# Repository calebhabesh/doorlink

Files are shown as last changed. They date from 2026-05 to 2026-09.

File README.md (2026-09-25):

# Doorlink

Doorlink is a self-hosted smart doorbell built around a custom ESP32-S3 board and a Raspberry Pi. A button press wakes the board, captures a still image, and sends the event to a local gateway. The gateway stores the media, updates the web dashboard, and sends a notification. The doorbell plays a local chime; when configured, the gateway also sends a Home Assistant webhook to play a chime on all configured smart speakers in the home. Visitor recordings and stored, turn-based voice replies are also supported.

<p align="center">
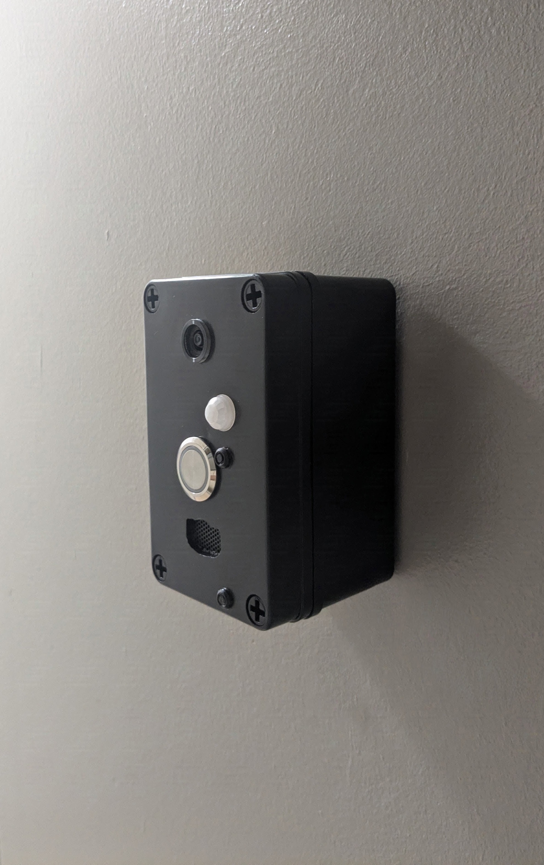
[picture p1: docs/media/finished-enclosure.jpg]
Assembled Doorlink Prototype Mounted on a Wall
  
</p>

## Prototype Status

The assembled Rev C board has completed battery-powered button wake, QXGA image capture, Wi-Fi upload, dashboard display, notification, and return to deep sleep. The microphone, speaker, and stored voice-reply path have been exercised on hardware. The latest session timing and hardened firmware still need a final flashed hardware retest; battery life and closed-enclosure current have not been measured. This is a working prototype, not a qualified outdoor product.

This is my first PCB layout and my first time hand-soldering surface-mount parts, including the ESP32-S3 module and ICS-43434 microphone. It took three revisions to get here: some scope creep, plus a few dumb mistakes that waited until after I ordered the boards to announce themselves.

## How It Fits Together

```mermaid
flowchart LR
    A[Doorbell PCB<br/>ESP32-S3 · camera · audio] -->|Wi-Fi| B[Raspberry Pi gateway<br/>Spring Boot]
    B --> C[(PostgreSQL<br/>events)]
    B --> D[(MinIO<br/>images and audio)]
    B --> E[Next.js dashboard]
    B --> F[ntfy notifications]
    A --> G[Local doorbell chime]
    B -->|Configured webhook| H[Home Assistant]
    H --> I[Smart speaker chimes]
    E -->|Stored voice replies| B
```

The firmware captures the image before joining Wi-Fi, then powers the camera down. Audio is turn-based: the visitor microphone and doorbell speaker do not run as a full-duplex call. The Raspberry Pi also runs Mosquitto for device commands.

## Hardware Gallery

| KiCad Rev C Board | Rev C Schematic |
| :---: | :---: |
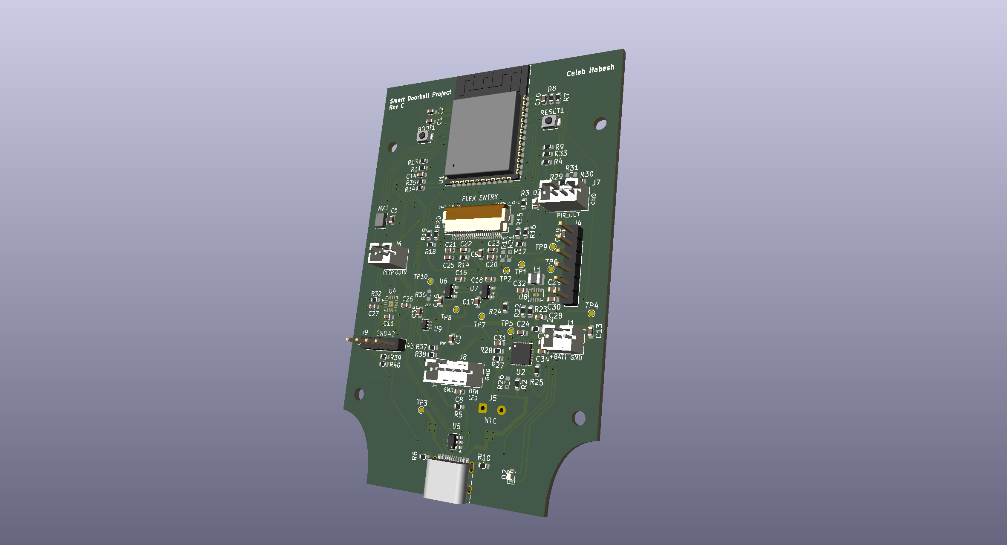
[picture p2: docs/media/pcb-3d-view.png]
KiCad Rev C Board
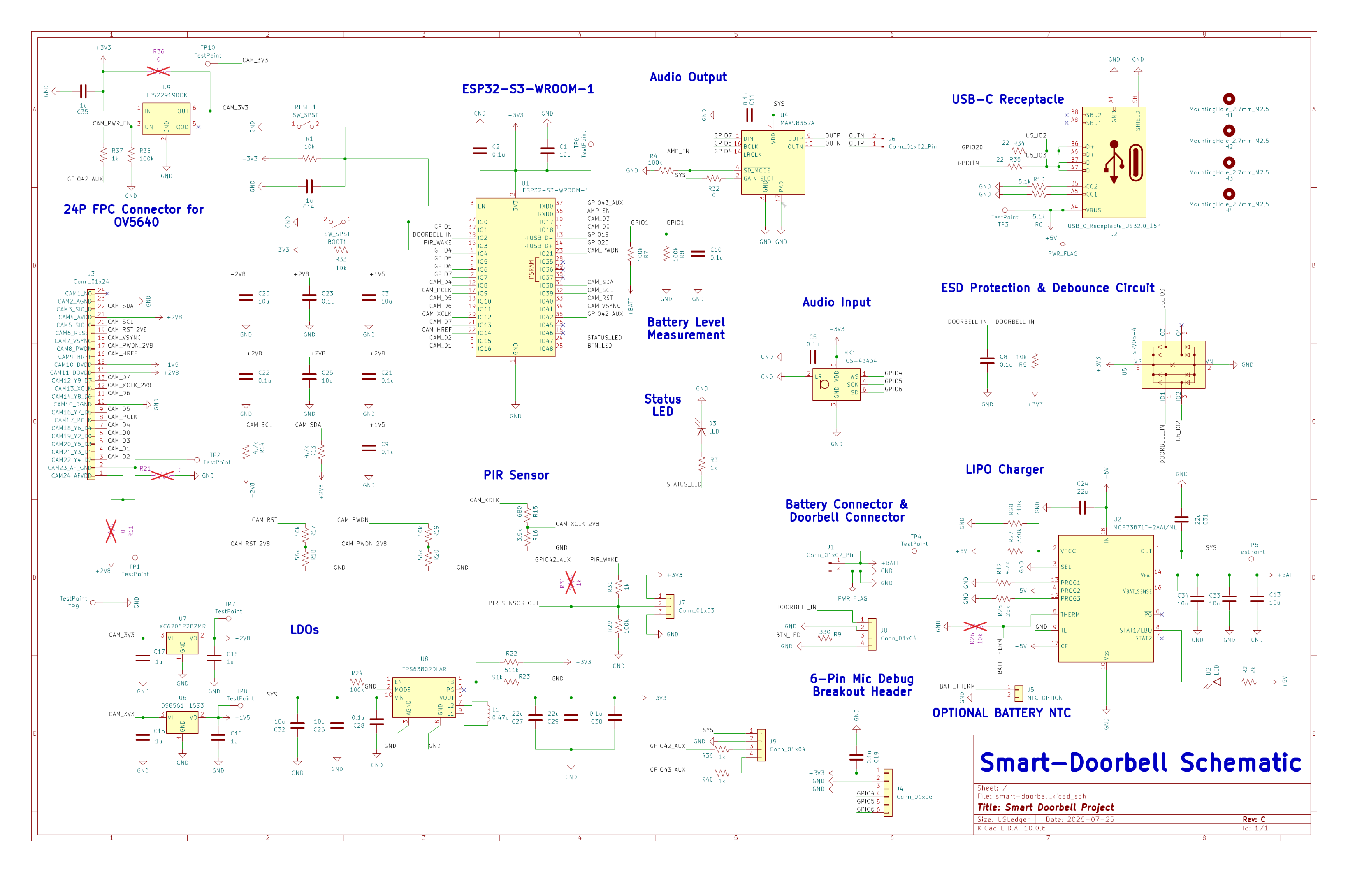
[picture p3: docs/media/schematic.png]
Rev C Schematic
|  |  |

| PCB Copper Layers (F.Cu and B.Cu) | Rev C Board Before ESP32 and Microphone Soldering |
| :---: | :---: |
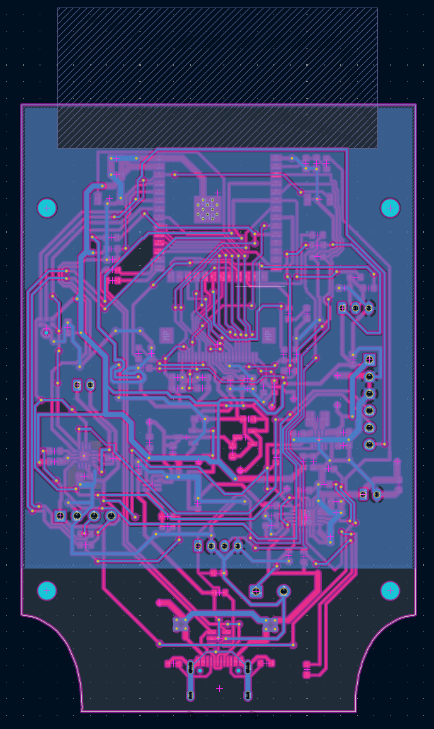
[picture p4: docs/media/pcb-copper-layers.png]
PCB Copper Layers (F.Cu and B.Cu)
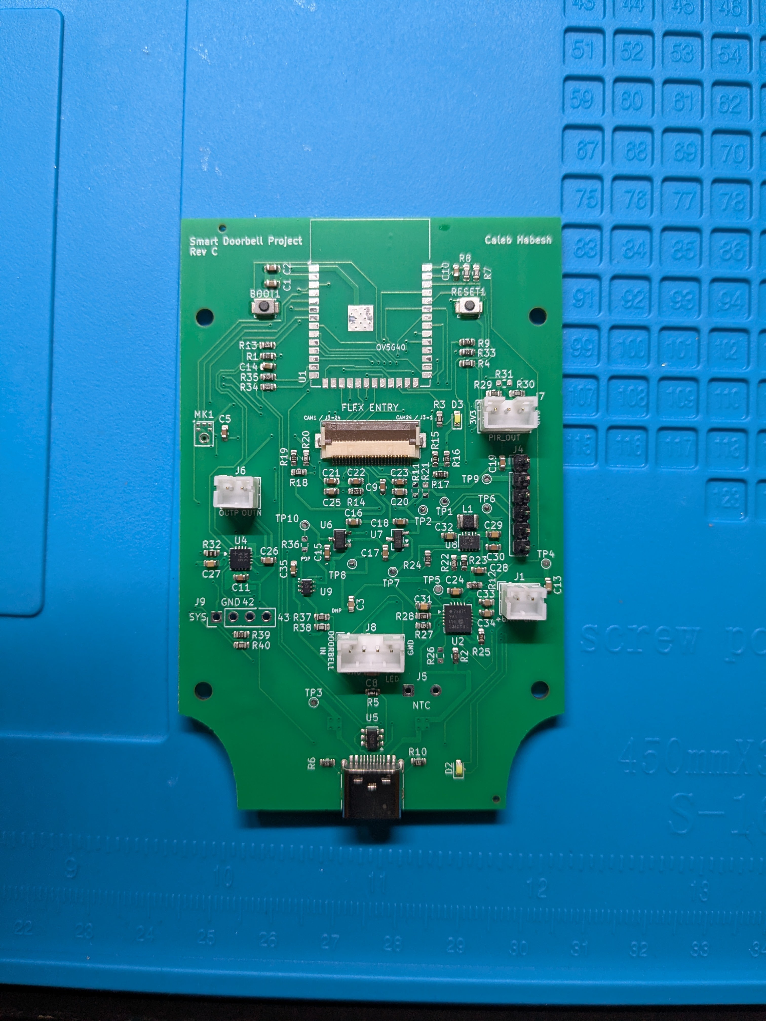
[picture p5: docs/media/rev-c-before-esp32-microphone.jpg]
Rev C Board Before ESP32 and Microphone Soldering
|  |  |

| Bench Bring-Up | Populated PCB | Enclosure Wiring |
| :---: | :---: | :---: |
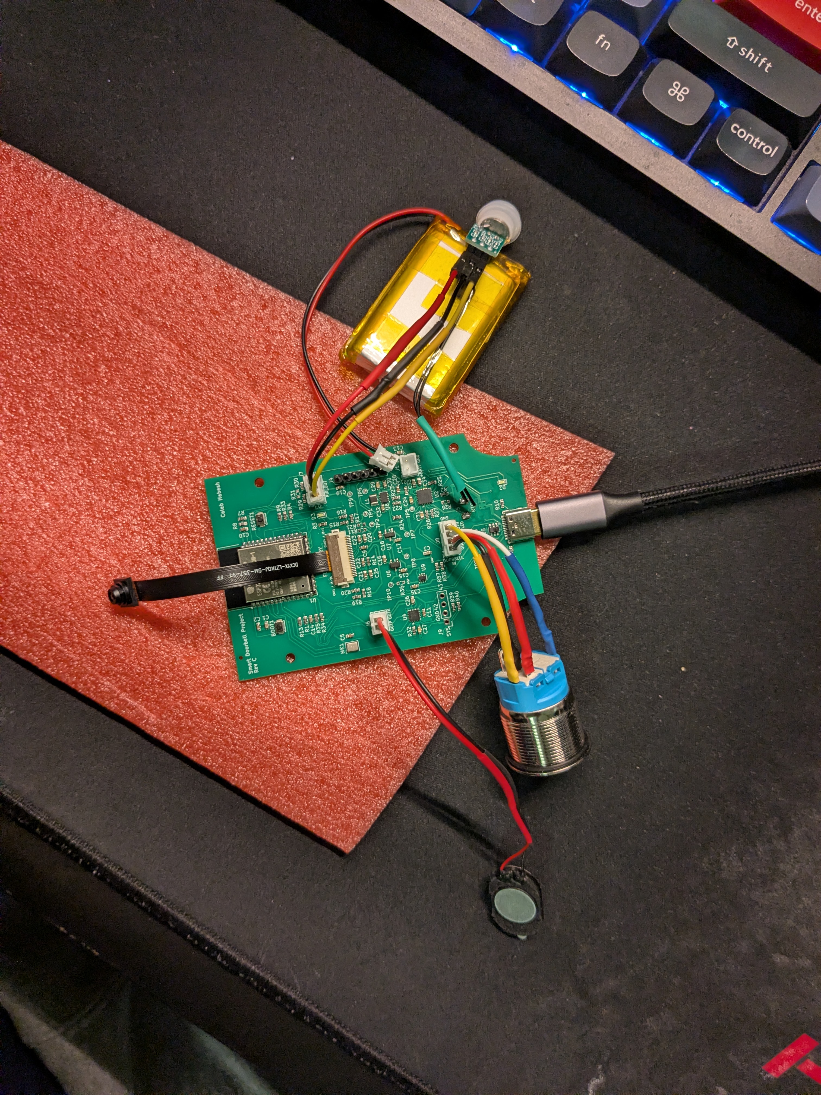
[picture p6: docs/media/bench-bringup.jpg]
Board and Peripherals During Bench Testing
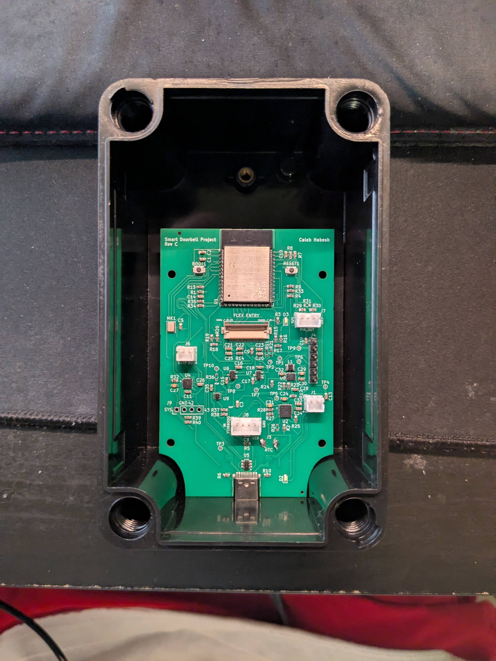
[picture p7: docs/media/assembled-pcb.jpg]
Rev C PCB Fitted in the Open Enclosure
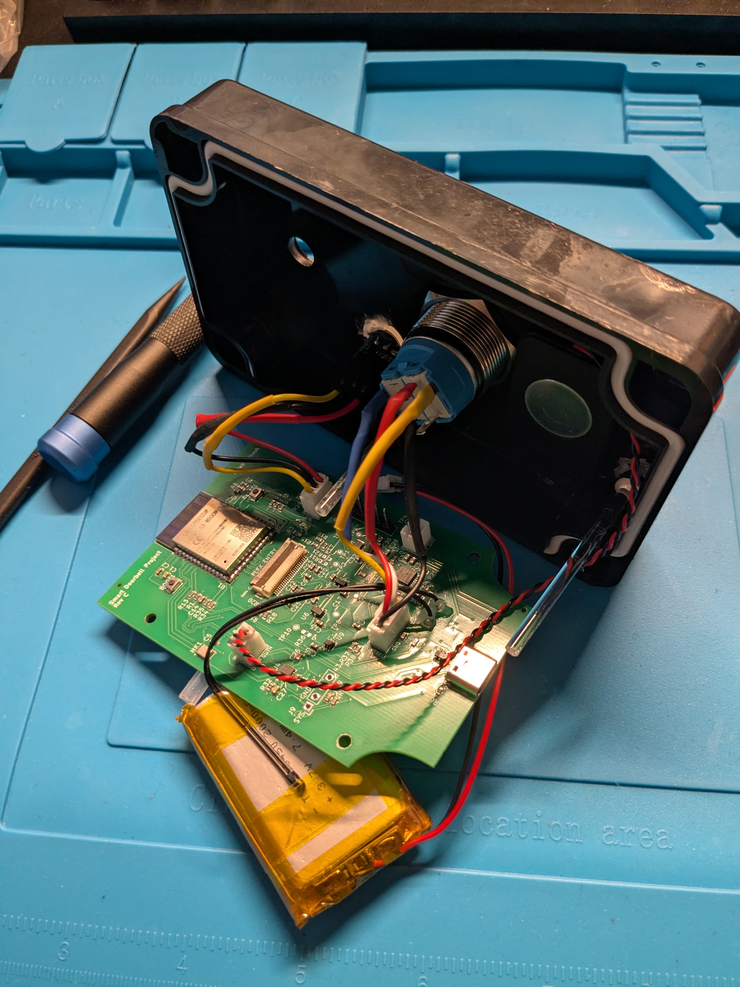
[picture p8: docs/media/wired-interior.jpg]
Board, Battery, Button, and Speaker During Enclosure Assembly
|  |  |  |

The board uses an ESP32-S3-WROOM-1-N16R8, OV5640 camera, ICS-43434 microphone, MAX98357A amplifier, MCP73871 charger, and TPS63802 3.3 V regulator. The [PCB overview](pcb/README.md) links the KiCad source and exact Rev C manufacturing files.

## Explore the Project

| Area | Contents |
| --- | --- |
| [`main/`](main/) | ESP-IDF firmware and routed board pin map |
| [`config/firmware/`](config/firmware/) | Firmware build presets and archived camera configurations |
| [`gateway/`](gateway/) | Spring Boot event API, persistence, media storage, and notifications |
| [`dashboard/`](dashboard/) | Next.js event and intercom interface |
| [`pcb/`](pcb/) | KiCad project and manufacturing records |
| [`docs/parts.md`](docs/parts.md) | Main unit parts and CAD cost |
| [`docs/firmware-architecture.md`](docs/firmware-architecture.md) | Firmware flow and validation status |
| [`docs/hardware-bringup.md`](docs/hardware-bringup.md) | Detailed Rev C hardware test record |

### Dashboard Preview

<p align="center">
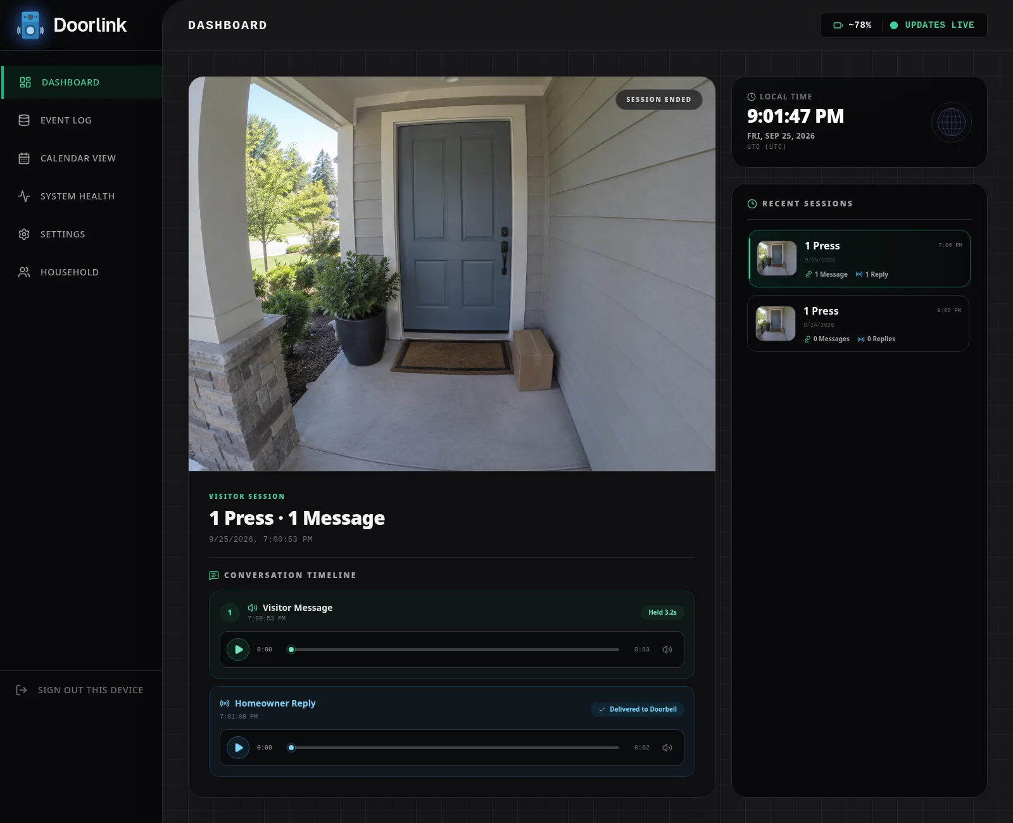
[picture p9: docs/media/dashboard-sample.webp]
Doorlink dashboard showing a sample visitor session, conversation timeline, and recent sessions
  
</p>

The dashboard is shown with synthetic sample sessions and a generated porch image. No visitor or household data is included.

## Run Locally

Install Docker Compose, Java 21, Node.js/npm, and the dashboard dependencies (`cd dashboard && npm ci`). From the repository root, run `./scripts/run-dev.sh` to start the isolated development stack. The gateway uses port 8081 and the dashboard uses [localhost:3001](http://localhost:3001). On first run, enter the setup token printed by the launcher. Ctrl+C stops the stack. The local credentials in `.env.dev` are for development only.

Firmware builds require ESP-IDF. Copy `main/config.example.h` to the ignored `main/config.h`, set your Wi-Fi and gateway values, then see [firmware architecture](docs/firmware-architecture.md) for the safe and production build commands. Raspberry Pi deployment is documented in [docs/pi-deployment.md](docs/pi-deployment.md).

## License

Software and written documentation: [MIT](LICENSE). KiCad hardware designs and manufacturing files under `pcb/`: [CERN-OHL-P-2.0](pcb/LICENSE). [Project photographs](docs/media/README.md): [CC0 1.0](https://creativecommons.org/publicdomain/zero/1.0/).

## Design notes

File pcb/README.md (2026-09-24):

# Doorlink PCB

The routed [KiCad schematic](smart-doorbell/smart-doorbell.kicad_sch) and [PCB](smart-doorbell/smart-doorbell.kicad_pcb) are the source for Rev C connections, footprints, and population intent. The Rev C design uses an ESP32-S3-WROOM-1-N16R8, an OV5640 24-pin camera connector, MCP73871 battery charging and power path, TPS63802 3.3 V regulation, and a GPIO-controlled camera power switch.

## Manufacturing files

The [Rev C ordered release](smart-doorbell/jlcpcb/rev-c/ORDERED_RELEASE.md) identifies the exact Gerber, JLCPCB BOM, and placement files submitted for the assembled prototype. Its BOM contains the 85 JLCPCB-populated references. U1 (ESP32-S3) and MK1 (microphone) were added after PCB assembly; several optional footprints remain unpopulated. The [protected assignment record](smart-doorbell/production/Smart_Doorbell_Project_B_bom-JLCPCB_FINAL.csv) retains per-reference LCSC assignments inherited from Rev B.

The [Rev B ordered release](smart-doorbell/jlcpcb/ORDERED_RELEASE.md) is historical. Its camera connector wiring differs from Rev C, so use the Rev C package for the photographed board. Do not regenerate or overwrite either ordered package.

The Rev C charger expects a suitable external 10 kΩ battery thermistor at J5; no thermistor is included in the PCB assembly BOM. See the [bring-up record](../docs/hardware-bringup.md) for the prototype checks and [board pin map](../main/board_pins.h) for firmware assignments.

Hardware design and manufacturing files in this directory: © 2026 Caleb Habesh, licensed under [CERN-OHL-P-2.0](LICENSE).

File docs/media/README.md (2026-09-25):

# Project Media

The schematic, PCB copper layer, and PCB 3D screenshots show the Rev C hardware design and follow the [hardware license](../../pcb/LICENSE).

`dashboard-sample.webp` shows the real dashboard interface with synthetic session data and a generated porch image. It follows the [software documentation license](../../LICENSE).

The project photographs in this folder are dedicated to the public domain under [CC0 1.0](https://creativecommons.org/publicdomain/zero/1.0/).

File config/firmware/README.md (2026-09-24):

# Firmware Build Configurations

Keep `sdkconfig.defaults` and `partitions.csv` at the project root for the normal ESP-IDF build. The small `sdkconfig.*.defaults` files here are optional overlays for production, microphone, wake, and camera experiments. Pass an overlay after the root defaults file with `SDKCONFIG_DEFAULTS`, as shown in [Firmware Architecture](../../docs/firmware-architecture.md).

The full `sdkconfig.revc-camera-*` files are archived configurations from Rev C camera bring-up. They are retained for reference and are not part of the default build.

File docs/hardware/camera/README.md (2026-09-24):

# OV5640 357-V1 seller documentation

The pinout below is transcribed from a mechanical drawing supplied by the
AliExpress seller for the fixed-focus `DCXYX-LZTKQJ-5M-357-V1` OV5640 camera
module. The seller's original image is not redistributed here.

The drawing identifies the 24 contacts as:

| Pin | Signal | Pin | Signal |
| --- | --- | --- | --- |
| 1 | NC | 13 | XCLK1 |
| 2 | AGND | 14 | Y8 |
| 3 | SIO_D | 15 | DGND |
| 4 | AVDD | 16 | Y7 |
| 5 | SIO_C | 17 | PCLK |
| 6 | RESET | 18 | Y6 |
| 7 | VSYNC | 19 | Y2 |
| 8 | PWDN | 20 | Y5 |
| 9 | HREF | 21 | Y3 |
| 10 | DVDD | 22 | Y4 |
| 11 | DOVDD | 23 | AF_GND |
| 12 | Y9 | 24 | AFVDD |

The seller drawing lists AVDD as 2.8 V, DOVDD as 1.8/2.8 V, and DVDD as
1.5 V. It also depicts a 24-contact, 0.5 mm-pitch FPC tail.

This is seller-provided evidence rather than a manufacturer-controlled
datasheet. The received module has now been compared with the drawing, but that
does not make the module a universal OV5640 mechanical standard. Every future
module must still be checked for physical pin 1, exposed-contact side, all
24 functions, and rail voltages. Pins 23 and 24 remain isolated by the board's
DNP contingency links for the fixed-focus module.

## Received first-article orientation

Front and rear photographs of the received camera were inspected on
2026-07-25. The flex marking reads `DCXYX-LZTKQJ-5M-357-V1 FF`, and the
24 exposed contacts are on the rear/shield side, opposite the lens. This
matches the seller drawing.

Both PCB revisions use J3 `FH12-24S-0.5SH(55)`, a horizontal bottom-contact
connector. With the PCB component side facing up, its antenna at the top, and
USB-C at the bottom:

- approach J3 from the antenna/U1 side;
- keep the camera lens facing up, away from the PCB;
- keep the exposed flex contacts facing down, toward the PCB;
- J3 pin 1 is the right-hand end near J7, and J3 pin 24 is the left-hand end
  near MK1.

This orientation mates the contact surfaces, but it does **not** preserve pin
order. The seller drawing's bottom/contact-side view has the camera body above
the tail, pin 1 at the right, and pin 24 at the left. Viewed from the
lens/printed side, that order is mirrored: pin 1 is at the left. Therefore the
photographed lens-up/contact-down insertion maps camera pin `n` to J3 pin
`25 - n`: camera pin 1 reaches J3 pin 24, and camera pin 24 reaches J3 pin 1.
The camera advertisement's enlarged tail drawing also visibly labels pin 24 at
the left and pin 1 at the right in the depicted contact-side view; it is
additional evidence of the same orientation, not evidence that the lens-side
orders match.

## Rev C physical mapping

Rev C keeps J3 in the mechanically correct Rev B orientation and corrects the
electrical nets on its physical pads. The footprint pad numbers remain honest:
camera pin `n` mates with physical J3 pad `25 - n`.

| Camera pin | Function | Physical J3 pad | Rev C board net |
| ---: | --- | ---: | --- |
| 1 | NC | 24 | NC |
| 2 | AGND | 23 | `GND` |
| 3 | SIO_D | 22 | `CAM_SDA` |
| 4 | AVDD | 21 | `+2V8` |
| 5 | SIO_C | 20 | `CAM_SCL` |
| 6 | RESET | 19 | `CAM_RST_2V8` |
| 7 | VSYNC | 18 | `CAM_VSYNC` |
| 8 | PWDN | 17 | `CAM_PWDN_2V8` |
| 9 | HREF | 16 | `CAM_HREF` |
| 10 | DVDD | 15 | `+1V5` |
| 11 | DOVDD | 14 | `+2V8` |
| 12 | Y9 / D7 | 13 | `CAM_D7` |
| 13 | XCLK1 | 12 | `CAM_XCLK_2V8` |
| 14 | Y8 / D6 | 11 | `CAM_D6` |
| 15 | DGND | 10 | `GND` |
| 16 | Y7 / D5 | 9 | `CAM_D5` |
| 17 | PCLK | 8 | `CAM_PCLK` |
| 18 | Y6 / D4 | 7 | `CAM_D4` |
| 19 | Y2 / D0 | 6 | `CAM_D0` |
| 20 | Y5 / D3 | 5 | `CAM_D3` |
| 21 | Y3 / D1 | 4 | `CAM_D1` |
| 22 | Y4 / D2 | 3 | `CAM_D2` |
| 23 | AF_GND | 2 | Isolated contingency net through DNP R21 |
| 24 | AFVDD | 1 | Isolated contingency net through DNP R11 |

The top silkscreen labels the ends `CAM1 / J3-24` and `CAM24 / J3-1`. The
project-local `ov5640_pinout.kicad_sym` library gives every J3 symbol pin both
the camera-pin identity and physical pad number. Run
`python3 scripts/verify-camera-interface.py` from the repository root to export
a fresh schematic netlist and enforce the complete mirrored map, contingency
links, level networks, and Rev C camera load switch.

Do not insert or power this camera directly in Rev B J3 again. A simple
lens-side flip is not a correction because J3 is bottom-contact and requires
the exposed flex contacts on the bottom. Recovering Rev B requires a verified
24-way crossover/interposer. Rev C needs no J3 rotation or flex twist, but its
first powered camera test still requires a known-good camera and the staged,
current-limited plan in `docs/hardware-bringup.md`.

The Rev C KiCad correction was submitted as the minimum five-board prototype
order on 2026-07-26 after its actual JLCPCB BOM match and top-side assembly
preview passed. Its exact upload files, hashes, and preview evidence are
recorded in `pcb/smart-doorbell/jlcpcb/rev-c/ORDERED_RELEASE.md`. Preserve both
immutable ordered releases: Rev B as fault history and Rev C as the corrected
first-article package. Insert or remove any flex only with every power source
disconnected, and keep R11 and R21 DNP for this fixed-focus module.

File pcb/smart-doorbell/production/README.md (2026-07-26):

# PCB release artifacts

The routed KiCad project is the electrical and population source of truth.
`Smart_Doorbell_Project_B_bom-JLCPCB_FINAL.csv` remains the protected,
authoritative per-reference LCSC assignment record for all references inherited
by Rev C.

The external `bom-JLCPCB Assembly Order.xls` describes the obsolete
MCP73831/AP2112 topology. It is not an upload BOM and may only be consulted for
substitution candidates after every current requirement has been reverified.

## Ordered Rev B release

The exact PCB/PCBA package submitted on 2026-07-15 remains at:

- `../jlcpcb/production_files/GERBER-smart-doorbell.zip`
- `../jlcpcb/production_files/BOM-smart-doorbell.csv`
- `../jlcpcb/production_files/CPL-smart-doorbell.csv`

Its immutable hashes, order identifiers, and provenance are recorded in
`../jlcpcb/ORDERED_RELEASE.md`. Run `sha256sum -c ORDERED_RELEASE.sha256` from
`../jlcpcb/` before using Rev B as comparison evidence.

Rev B contains the known physical J3 camera-pin reversal. Never reorder it and
do not insert the selected lens-up/contact-down camera directly into a Rev B
board. Rev B populated R36, left U9/R37 DNP, and used populated fixed R26 in
place of real cell-temperature sensing; these facts describe only the ordered
historical batch.

## Ordered Rev C release

Rev C has a separate ordered-release directory:

- `../jlcpcb/rev-c/production_files/GERBER-smart-doorbell.zip`
- `../jlcpcb/rev-c/production_files/BOM-smart-doorbell.csv`
- `../jlcpcb/rev-c/production_files/CPL-smart-doorbell.csv`

Exact hashes, generation provenance, local verification results, and the
signed-off JLCPCB BOM/preview evidence are recorded in
`../jlcpcb/rev-c/ORDERED_RELEASE.md`. Run
`sha256sum -c ORDERED_RELEASE.sha256` from that directory whenever verifying
the submitted bytes.

Rev C contains 85 populated references in both BOM and CPL. Existing protected
Rev B references retain their exact value/LCSC assignment. The intentional
population delta is:

- add/populate C35 (`1u`, C15849);
- add/populate R37 (`1k`, C21190);
- add/populate U9 (`TPS22919DCKR`, C2149796);
- remove/DNP R26 and R36.

U9 is the only populated path from `+3V3` to `CAM_3V3`. R38 and the TPS22919
internal pulldown keep it default-off; GPIO42 reaches `CAM_PWR_EN` through
populated R37. R31 must remain DNP so GPIO42 is not also connected to the PIR
fallback. QOD is intentionally open.

Rev C intentionally excludes these references from both BOM and CPL:

- U1 (`ESP32-S3-WROOM-1-N16R8`) and MK1 (`ICS-43434`), hand solder;
- R11 and R21, DNP camera contingency links;
- R26, DNP fixed THERM resistor;
- R31, DNP GPIO42 PIR fallback;
- R36, DNP camera-power bypass;
- J5 and J9, unpopulated hand-solder/expansion connections;
- TP1 through TP10, bare test points;
- H1 through H4, mechanical mounting holes.

J5 is only a connection for an external thermistor. No NTC is present in the
Rev C JLCPCB BOM. Do not charge a battery until a suitable
10 kOhm-at-25-degrees-C NTC is wired to J5 and thermally attached to the cell.

The BOM explicitly targets timer-disabled `MCP73871T-2AAI/ML`; do not substitute
the six-hour-timer `MCP73871T-2CCI/ML` at the present approximately 213 mA
charge current.

## Legacy comparison evidence

`Smart_Doorbell_Project_B.zip` and its adjacent Fabrication Toolkit exports are
retained only as previously reviewed comparison evidence. They were not the
files submitted for the 2026-07-15 order.

Neither a local CPL inspection nor this manifest replaces JLCPCB's rendered
assembly preview. The Rev C order passed that external gate before submission:
all 85 top-side placements, every DNP, package, side, and rotation were checked,
with special attention to U9 pin 1 at the corrected 180-degree CPL rotation.
The retained evidence and sign-off are part of the ordered Rev C release.

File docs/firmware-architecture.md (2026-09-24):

# Firmware architecture

The firmware uses controlled C++ for event orchestration while retaining C for
the proven hardware and ESP-IDF-facing layers. Exceptions and RTTI are disabled.
The default build remains the core-only safe image; production mode is an
explicit, isolated configuration.

## Runtime path

`app_main.cpp` selects either a diagnostic image or `DoorbellController`.
Production mode follows this bounded session sequence:

1. `BOOTING`: reapply the retained camera/audio-safe GPIO state, release the
   sleep holds without a pad glitch, and classify the wake.
2. `LOCAL_CHIME`: start the bounded low-power camera-overlap chime profile. One
   playback claim, including rapid repress retriggers, has a 15-second wall
   limit and a 1.5-second zero-progress I2S limit.
3. `CAPTURING`: with RF off, enable GPIO42/U9, initialize the OV5640, capture QXGA, copy the
   JPEG to owned PSRAM, return the frame, deinitialize the driver, and disable
   U9.
4. `CONNECTING` / `TRIGGERING`: connect Wi-Fi after shutter close and post the
   authenticated session/press trigger.
5. `UPLOADING`: independently POST available JPEG and visitor WAV media under
   stable per-press identifiers. All retries share one stage wall deadline.
6. `VISITOR_RECORDING`: if GPIO2 remains held after the first chime, or on any
   later press, retain 1-15 seconds of release-driven microphone audio.
7. `PTT_SESSION`: accept only HMAC-authenticated MQTT commands for the active
   random session, reject replay IDs, and queue homeowner playback behind any
   active visitor capture. Media and acknowledgement URLs must match the exact
   configured gateway origin and route; redirects are disabled.
8. `SHUTTING_DOWN`: explicitly close the gateway session, release media, stop
   Wi-Fi, drive the load gates and I2S pads safe, latch those states, configure
   wake sources, and enter deep sleep.

Camera and Wi-Fi are deliberately non-overlapping high-load phases. The camera
frame never survives camera-driver shutdown; only the owned PSRAM copy does.
The event ID also makes a retry after a lost HTTP response idempotent at the
gateway and gives media a stable object key.

## Ownership and boundaries

| Layer | Language | Responsibility |
| --- | --- | --- |
| `DoorbellController` | C++ | State machine, retry policy, event type, shutdown orchestration |
| `CameraService` / `CapturedImage` | C++ | RAII ownership of the PSRAM JPEG |
| `ConnectivityManager` | C++ | Bounded Wi-Fi/upload lifecycle and shutdown guard |
| `IntercomService` / `intercom_protocol` | C++ | Signed command validation, fragment assembly, URL policy, and bounded playback |
| `AudioService` / `chime_player` | C++ / C | Deadline-bound I2S ownership, capture, playback, and fail-safe teardown |
| `PowerManager` | C++ | Wake classification, stuck-input handling, and deep-sleep entry |
| `camera_capture` | C | OV5640 configuration and guaranteed frame/driver/power cleanup |
| `camera_power`, `ov5640_mode_fix`, bring-up modules | C | Auditable hardware sequencing and diagnostics |

There is no inheritance hierarchy, exception path, or RTTI dependency.
Follow-up turn metadata is bounded heap state and visitor WAV/JPEG payloads use
PSRAM where available. ESP-IDF errors remain `esp_err_t`.

## Wake behavior

- GPIO2 `DOORBELL_IN`: EXT0, active low, routed 10 kOhm pull-up and debounce
  capacitor.
- GPIO3 `PIR_WAKE`: EXT1, active high, routed 100 kOhm pulldown through the
  populated Rev C R30 path.
- A held button or still-high PIR is excluded from that sleep cycle to prevent
  a rapid wake loop. A 30-second timer is enabled so the input can be checked
  again.
- Cold boot, timer-recovery wake, and unknown wake causes enter sleep without
  taking a picture.
- GPIO48 uses a non-blocking LEDC fade on timer/channel 1. Camera XCLK remains
  on timer/channel 0.
- Before deep sleep, GPIO42, GPIO44, and GPIO4-7 are individually held in their
  safe state. ESP32-S3's global digital deep-sleep hold is enabled for the two
  non-RTC load gates. Wake code programs the same safe state before releasing
  the latches.

## Builds

Safe core-only build:

```bash
idf.py build
```

Production-controller build, isolated from the safe `sdkconfig`:

```bash
idf.py -B build-production -D SDKCONFIG=sdkconfig.production \
  -D 'SDKCONFIG_DEFAULTS=sdkconfig.defaults;config/firmware/sdkconfig.production.defaults' build
```

Both configurations build with ESP-IDF 6.0.1. The hardened production image is
approximately 1.56 MiB and leaves about 48% of the 3 MiB application partition
free.

## Validation status

Implemented and independently proven hardware operations include QXGA capture,
camera shutdown, battery-only Wi-Fi upload, gateway persistence, dashboard
display, notifications, and isolated GPIO2 button and GPIO3 PIR wakes followed
by return to deep sleep. An RTC-fast wake stub gives immediate visual acknowledgement on D3
before the bootloader; GPIO48 begins its nonblocking ring animation as soon as
the application starts. Cold boots still validate the
application image. The pre-fast-trigger production controller has completed QXGA capture, HTTP
upload, cleanup, and return to deep sleep from both button and PIR triggers on
hardware; notification delivery and Doorlink display were observed for both
event types. The fast-trigger/idempotent-upload flow was USB-validated on Rev C
on 2026-08-05. Corrected PIR and button events received HTTP `200` for the early
trigger in approximately 1.2-1.6 seconds, fully stopped Wi-Fi before camera
startup, completed isolated QXGA capture, uploaded under the same event ID, and
returned to deep sleep. The gateway stored one event per ID and did not invoke
the chime again during upload. Production now leaves PIR event wake disabled
unless `CONFIG_SMART_DOORBELL_ENABLE_PIR_EVENTS` is explicitly selected. The
isolated GPIO48 diagnostic and production path both validated an off-to-full
1.8-second fade, 2.5-second hold, and 1.8-second fade-out without delaying Wi-Fi
or camera work. Camera
convergence remains the dominant image-delivery delay.
Deep-sleep current remains unmeasured. The earlier fixed-duration visitor audio
and stored PTT playback path passed hardware tests; release-driven capture and
multi-press arbitration are implemented and build-tested but still require an
instrumented board validation pass.

The 2026-08-23 pre-enclosure hardening pass added strict fragmented-MQTT
assembly, HMAC-SHA256 command authentication and replay rejection, gateway-only
URL policy, redirect suppression, shared wall deadlines for retries, bounded
I2S stall handling, a bounded greeting-task join with fail-safe sleep, and
deep-sleep GPIO retention. The host guard tests, all 42 gateway tests, and a
clean ESP-IDF 6.0.1 production build pass. This revision has not yet been
flashed or battery-cycle tested; see `firmware-release-checklist.md`.

The production controller also takes a calibrated 16-sample +BATT reading from
GPIO1 before starting the speaker, camera, or radio. The gateway retains the
millivolt value and sample time; System Health exposes those authoritative
fields plus a coarse, explicitly estimated one-cell Li-ion percentage. It does
not infer charger state, thermistor temperature, remaining runtime, or a
low-battery cutoff.

The current production flow supersedes the USB-validated trigger-first order:
the first QXGA frame is captured before Wi-Fi starts, then its owned JPEG is
uploaded before the controller waits for a held-button recording. Repress
lifecycle work may remain ordered for persistence, but only the press reserved
for immediate controller handling can dispatch remote alerts; all others are
registered with alerts permanently suppressed. Repress local acknowledgements
remain opportunistic and are never queued behind microphone or homeowner audio.
This revision is compiler- and gateway-test-verified and still needs
flashed-board timing validation. EXT0 is re-armed only after session close,
cleanup, and the existing button-release guard.

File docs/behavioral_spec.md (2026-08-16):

# Smart Doorbell Production Interaction Contract

This is the locked production behavior for the Rev C door-mounted device. It
defines product behavior; hardware-dependent timing and audio quality still
require validation on the assembled board after firmware changes.

## Non-negotiable hardware rules

- `PWR-01`: Wi-Fi RF and `CAM_PWR_EN`/GPIO42 are never active together.
- `PWR-02`: Camera rails and `AMP_EN`/GPIO44 are disabled immediately after use.
- `MEM-01`: the camera frame is copied to owned PSRAM before its driver buffer is
  returned and U9 is disabled.
- `AUDIO-01`: local chime, visitor microphone, and homeowner reply are
  half-duplex users of the shared I2S bus.
- `SLEEP-01`: a button still held at shutdown is handled by the GPIO2
  wake-on-release guard; it must not cause a wake loop or another visitor event.

## Visitor session

The first debounced button press creates a random 32-character `sessionId` and
press ID `<sessionId>-1`. More button-down edges before session expiry create
ordered press IDs `<sessionId>-2`, `<sessionId>-3`, and so on.

The session ends at the earlier of:

- 60 seconds since the last visitor/PTT activity; or
- 90 seconds since the first press.

Firmware explicitly closes the session before sleep when the gateway is
reachable. The gateway and dashboard infer closure from the same 60/90-second
limits if that close request is lost.

Every press is persisted with its own idempotency key. The first press dispatches
the indoor/Home Assistant chime immediately after the initial shutter closes.
Each fresh repress independently requests the whole-home chime; the gateway
drops requests during its playback cooldown instead of retaining a trailing
request. Represses that cannot be handled promptly remain persisted but are
ineligible for a delayed chime.

## First press

1. GPIO2 must remain stable for 20 ms.
2. Start the ring LED and the complete local chime on the camera-safe 12 dB
   profile.
3. Keep RF quiesced and start the initial QXGA snapshot without waiting for the
   camera-safe chime to finish. Capture the first complete frame; do not spend
   several QXGA frame periods on unrequested convergence discards.
4. Return the camera frame, disable U9, connect Wi-Fi, and send the authenticated
   gateway trigger.
5. Upload the owned JPEG immediately, without waiting for button release or a
   visitor recording to finish.
6. If the visitor is still holding when the complete chime releases I2S, start
   the microphone immediately and record until release or the 15-second cap.
   Attach any retained WAV to the existing press in a separate upload.
7. Open the bounded homeowner reply window after the visitor turn finishes.

A visitor recording is retained only when it contains at least 1.0 second of
microphone audio. Releasing during the first chime, or before one second of
post-chime microphone audio, is a normal short press and creates no empty WAV.

## Later presses

- Restart LED acknowledgement on every valid down-edge.
- Start an onboard acknowledgement chime when I2S is idle. Never queue a
  delayed chime behind visitor microphone or homeowner playback. If a local
  chime is already audible, rewind its live stream at the next PCM chunk
  boundary so every valid physical down-edge gets prompt audible feedback.
- Treat repress chimes as interruptible: a visitor still holding after 1,200 ms
  stops the repress chime cleanly and receives the microphone. A tap may let
  its acknowledgement chime finish.
- Until that same down-edge has remained continuously held for 1,200 ms, it
  cannot reserve the microphone or stop a local chime. A newer down-edge
  invalidates every older pending hold classification, so an old tap cannot
  mistake the new press for its own continued hold.
- Retain visitor microphone audio only after the one-second recording threshold
  is crossed. Release creates one logical recording.
- A release followed by another hold creates another ordered press/recording.
- Keep the initial snapshot for the active session. Do not repower the camera
  for a repress: its RF-off capture boundary would make the global chime and
  intercom unavailable during the refresh. The next session takes a new image.
- Each repress launches a separate immediate gateway request from its physical
  edge while RF is available, independently of camera/media lifecycle work.
  A request already in flight causes the new edge to be dropped rather than
  queued. Later lifecycle or media work persists the press with
  `dispatchAlerts=false` and cannot manufacture a delayed whole-home chime.
- There is no three-press product limit. The 60/90-second session bounds and
  memory/queue limits are the safety boundary.

Recordings stay in bounded RAM through their upload attempt; firmware does not
write visitor audio to flash.

## Half-duplex arbitration

The first press starts a complete chime. A later deliberate 1,200 ms hold may
reclassify the active local stream as interruptible so the visitor can claim
the microphone. Established visitor/homeowner turns remain protected except at
the 90-second hard deadline:

1. The first local chime completes unless a subsequent held repress explicitly
   yields it to the microphone.
2. A repress acknowledgement may play only while I2S is otherwise idle; a
   sustained visitor hold or arriving homeowner WAV interrupts it cleanly.
   The repress does not claim the microphone window until its own continuous
   1,200 ms hold qualification completes.
3. An active visitor recording completes on release or at 15 seconds.
4. A homeowner reply received during visitor capture is queued.
5. The microphone is off while the queued homeowner WAV plays through the
   speaker.
6. An already-playing homeowner reply completes; a new visitor hold waits for
   I2S and records afterward if the visitor is still holding.
7. Session cleanup overrides queued work at the hard deadline.

Dashboard PTT records a stored 16 kHz mono PCM WAV; it is not a live phone call.
The gateway reports `ARMING` when it publishes the device command and reports
reply delivery only after the ESP32 playback acknowledgement.

## Speaker and camera power arbitration

The production speaker paths apply 6 dB of digital attenuation by default to
support the 4-ohm enclosure speaker without demanding the full-scale current
used during the failed integrated test. Local chimes and homeowner replies both
use the same setting and a 25 ms linear fade-in/fade-out envelope. These values
are build-time configurable through
`CONFIG_SMART_DOORBELL_SPEAKER_ATTENUATION_DB` and
`CONFIG_SMART_DOORBELL_SPEAKER_RAMP_MS`.

The initial camera capture runs before Wi-Fi startup so network latency cannot
move the shutter toward button release. Its owned JPEG is also uploaded before
joining a held-button recording. Gateway triggers remain idempotent per physical
`pressId`, and the gateway acknowledges and persists each press without waiting
for Home Assistant. Whole-home webhook delivery uses a 1.5-second leading-edge
cooldown: the first request
dispatches immediately, requests during the cooldown are dropped, and the first
request after expiry dispatches immediately. No trailing webhook is retained,
so rapid presses cannot become a delayed playback burst. Repress uploads never
act as fallback chime requests.

The first press claims the bounded 12 dB camera-overlap profile before playback
starts, so RF shutdown and camera startup no longer wait for the complete
waveform. Represses during the boundary restart the same complete quiet
waveform. If that low-power chime already owns AMP_EN, camera rail enable waits
for its 25 ms ramp plus a 5 ms guard before adding the camera load. Camera
startup still refuses overlap with any unverified speaker owner. Visitor
microphone and homeowner playback retain I2S priority. Transient I2S DMA
backpressure during QXGA work is retried in place and is not treated as the end
of the chime.

Normal session expiry stops button monitoring first, then allows an already
audible local chime to drain before entering sleep. Firmware force-stops that
playback only when it remains active past the bounded four-second shutdown
deadline, which indicates a wedged audio path rather than an ordinary session
transition.

## Persisted and UI model

```text
Visitor session
├── Press 1
│   ├── optional snapshot
│   └── zero or more visitor recordings
├── Press 2
│   └── zero or more visitor recordings
└── homeowner reply turns
```

`sessionId`, `pressId`, `recordingId`, and reply `messageId` are stable retry
keys. The gateway emits lifecycle SSE updates (`session-started`,
`press-started`, `press-ended`, `session-updated`, and `session-closed`). Active
Event, Event Log, and Calendar render one grouped session, with an ordered
conversation timeline instead of one card per upload.

Legacy event rows remain readable during rollout; rows with the historical
`<sessionId>-<pressNumber>` pattern are grouped into closed sessions.

## Production constants

| Constant | Value |
| --- | ---: |
| GPIO2 stable debounce | 20 ms |
| Minimum retained visitor audio | 1,000 ms |
| Maximum visitor recording | 15,000 ms |
| Repress chime-to-microphone handoff | 1,200 ms |
| Production speaker attenuation | 6 dB |
| Speaker fade-in/fade-out | 25 ms |
| Camera-overlap chime | Full waveform at 12 dB attenuation |
| Discarded first-snapshot convergence frames | 0 |
| Repress edge-request timeout | 750 ms, no waiting queue |
| Whole-home chime cooldown | 1,500 ms, leading edge, no queue |
| Session idle limit | 60,000 ms |
| Session absolute limit | 90,000 ms |
| Browser homeowner reply limit | 20,000 ms |

## Failure behavior

- Wi-Fi failure never prevents the complete first local chime or LED
  acknowledgement.
- The first chime is not stopped merely because time elapsed. A physical
  repress may restart its live stream from sample zero; a deliberate held
  repress may yield it to the microphone after 1,200 ms.
- After the final quick press, the restarted chime is allowed to complete.
  Repress chimes may also yield to homeowner WAV or safe shutdown.
- Camera failure leaves the early session/press alert intact and cuts camera
  power; the dashboard may show snapshot pending.
- A lost trigger or media response is retried with stable identifiers, so it
  does not create another notification or recording.
- Quiet speech is retained; firmware does not use voice-activity detection to
  discard it.
- The 15-second recording cap does not bypass stuck-button wake-on-release
  protection.

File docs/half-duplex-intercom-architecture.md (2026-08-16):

# Doorlink Half-Duplex Intercom Architecture

The fixed-duration visitor WAV and stored dashboard-to-speaker reply path have
passed on assembled Rev C hardware. The release-driven multi-press policy below
is implemented and build-tested; its thresholds and latency still require a
flashed-board validation pass.

Doorlink is a turn-based voicemail relay, not a full-duplex call. The local
chime, ICS-43434 microphone, and MAX98357A speaker share a half-duplex I2S path,
so only one owns it at a time. MQTT transports small control commands and HTTP
transports stored WAV media.

## Visitor flow

```mermaid
sequenceDiagram
    actor Visitor
    participant ESP as ESP32-S3
    participant GW as Spring Gateway
    participant UI as Dashboard
    actor Homeowner

    Visitor->>ESP: First press / hold
    par Local acknowledgement
        ESP->>ESP: Play one complete local chime
    and Early alert
        ESP->>GW: POST session + press trigger
        GW-->>UI: session-started SSE
    end
    ESP->>ESP: If still held, record until release (1-15 s retained)
    ESP->>ESP: RF off, capture snapshot, camera power off
    ESP->>GW: Upload available JPEG/WAV with stable IDs
    GW-->>UI: session-updated SSE

    Visitor->>ESP: Later press / hold
    ESP->>ESP: LED + interruptible local chime if I2S idle
    ESP->>ESP: If held 1,200 ms, stop repress chime and record
    ESP->>GW: Register press and upload WAV

    Homeowner->>UI: Hold PTT, then release
    UI->>GW: Store canonical 16 kHz mono PCM WAV
    GW->>ESP: MQTT PLAY_AUDIO with HTTP URL
    Note over ESP: Queue behind active visitor recording
    ESP->>ESP: Microphone off; enable amp and play complete reply
    ESP->>GW: Playback acknowledgement
    GW-->>UI: session-updated SSE
```

The initial microphone can start only after the complete local chime. A visitor
who releases during that chime leaves no recording. Later presses request an
immediate local acknowledgement only when I2S is idle. A tap may let that chime
finish; a new valid down-edge while a local chime is audible rewinds the live
stream at its next PCM chunk boundary. A hold continuing for 1,200 ms interrupts
interruptible repress audio and hands I2S to the microphone. Repress chimes are
skipped, not delayed, while visitor or homeowner audio owns the bus. A release
followed by another hold is another ordered press and recording in the same
60/90-second session.

## Arbitration

Priority is:

1. Finish the first local chime.
2. Yield an interruptible repress chime to a sustained visitor hold or an
   arriving homeowner WAV.
3. Finish an active visitor turn on release or at 15 seconds.
4. Play a queued homeowner reply completely.
5. If a visitor presses during that playback, finish the active reply and give
   the microphone to a visitor who is still holding.
6. Enforce the 90-second hard session deadline and safe shutdown.

No voice-activity detector discards quiet speech. Recordings shorter than one
second are discarded solely to avoid empty tap/accidental-hold files.

## Control and data planes

Homeowner replies are stored in MinIO before this command is published on
`doorbell/commands/audio`:

```json
{
  "type": "PLAY_AUDIO",
  "eventId": "0123456789abcdef0123456789abcdef",
  "messageId": "6db2995e-4c0e-4717-9b95-8c0330031eb2",
  "audioUrl": "http://gateway:8080/api/events/media/reply.wav",
  "ackUrl": "http://gateway:8080/api/system/ptt/messages/6db2995e-4c0e-4717-9b95-8c0330031eb2/delivered",
  "durationMs": 3200
}
```

`eventId` is the session target. The ESP32 fetches and streams the canonical WAV
over HTTP, disables the amplifier after its final sample, and POSTs `ackUrl`.
The dashboard distinguishes `Playback queued` from `Played at door` using that
acknowledgement. A successful MQTT publish alone is reported as `ARMING`, not as
confirmed device playback.

## Persistence model

- `visitor_sessions`: session bounds, activity, and explicit close state.
- `events`: ordered physical presses and their snapshot/lifecycle state (kept as
  the table name for compatibility).
- `visitor_recordings`: stable recording ID, press relationship, media key, and
  measured WAV duration.
- `intercom_messages`: homeowner WAV, creation time, and playback delivery time.

Active Event, Event Log, and Calendar consume grouped session DTOs. Legacy rows
using numbered press IDs are grouped into closed sessions during migration.

## Why stored half-duplex turns

- It avoids acoustic echo cancellation and intentional chime contamination.
- It keeps radio activity bounded for a battery-powered device.
- Stable files and identifiers can be retried after intermittent Wi-Fi.
- The UI can present a truthful, durable conversation timeline rather than
  claiming unsupported live audio streaming.

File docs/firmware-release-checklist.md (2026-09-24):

# Firmware release checklist

This is the final pre-enclosure acceptance gate for the Rev C production
firmware. Passing the software checks makes the image a release candidate; it
does not replace current, temperature, supply-droop, or battery-life
measurements on the assembled device.

## Verified in the development checkout

- Fragmented MQTT messages are accepted only when every offset and total is
  contiguous, consistent, and leaves room for the terminator.
- Gateway commands use protocol `v1`, a unique UUID, and HMAC-SHA256 over every
  field consumed by firmware. Altered, unsigned, and recently replayed commands
  are rejected.
- Reply media and acknowledgement URLs must use the exact scheme, host, and
  port from `GATEWAY_API_URL`, plus the expected API path shape. Query strings,
  fragments, escapes, traversal, user-info, and redirects are rejected.
- One chime claim has a 15-second wall limit and a 1.5-second no-progress limit.
  Microphone capture, HTTP playback, stage retries, and the greeting task join
  use finite deadlines. A missed task join proceeds to safe sleep rather than
  returning with a live stack reference.
- `CAM_PWR_EN`, `AMP_EN`, I2S WS/SCK, speaker data, and microphone data are
  latched in their safe states through deep sleep and released glitch-free on
  wake.
- Production samples the populated GPIO1 battery divider before high-current
  peripherals start and reports calibrated millivolts on both the early event
  trigger and media upload. Dashboard percentage is an estimate; it is not a
  measured state of charge or a low-battery cutoff.

Run the reproducible software gates:

```bash
./scripts/test-firmware-guards.sh

cd gateway
./mvnw test

cd ..
source /home/ethioking/.espressif/v6.0.1/esp-idf/export.sh
idf.py -B build-production -D SDKCONFIG=sdkconfig.production \
  -D 'SDKCONFIG_DEFAULTS=sdkconfig.defaults;config/firmware/sdkconfig.production.defaults' build
```

## Rollout order

The hardened firmware deliberately rejects commands from an older gateway.

1. Confirm the Pi and `main/config.h` use the same high-entropy
   `GATEWAY_API_KEY`.
2. Deploy and restart the gateway first:
   `./scripts/build-pi-production.sh --gateway-only --restart`.
3. Flash the production firmware and retain USB access for the first smoke run.
4. Confirm a dashboard PTT start/cancel/reply round trip. The device log must
   show the MQTT subscription and normal playback, with no
   `unauthenticated intercom command` message for gateway-generated commands.

## Required physical acceptance before sealing

1. On USB power, run one complete press, QXGA capture, image upload, optional
   held-button recording, reply playback, session expiry, and return to sleep.
2. Repeat a complete cycle on battery only with the final camera, 4-ohm
   speaker, button, PIR harness state, and enclosure cable routing fitted.
3. During the battery cycle, check 3.3 V droop/reset behavior, image integrity,
   amplifier and regulator temperature, and camera shutdown. Exercise at least
   one repress during the bounded camera-overlap chime.
4. Confirm System Health shows a plausible battery voltage from that event and
   compare it with TP4 using a multimeter. Record the pair; the earlier 4.028 V
   firmware / 4.05 V meter result is only one calibration point.
5. Measure awake and deep-sleep current. Battery life remains unqualified until
   those values are recorded; do not infer it from the earlier one-cycle test.
6. Verify `CAM_PWR_EN` and `AMP_EN` remain low in deep sleep. If practical,
   confirm I2S WS/SCK are also low rather than floating.
7. Power-cycle twice from battery and confirm GPIO2 wakes once per press, the
   held-input guard does not create a wake loop, and every cycle returns to
   deep sleep.

Record the measurements in `docs/hardware-bringup.md`. Only then treat this
firmware and the assembled battery unit as production-signed-off.

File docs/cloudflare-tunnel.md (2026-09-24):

# Cloudflare Tunnel and household device access

Doorlink uses Cloudflare Tunnel for private origin connectivity and its own
revocable household-device sessions for browser authentication. Cloudflare
Access email OTP must not sit in front of the hostname: its one-month maximum
session would reintroduce the login prompt before Doorlink can see the device
cookie.

## Traffic path

`doorbell.example.com` → Cloudflare Tunnel → Next.js on `localhost:3000` →
Spring gateway on `127.0.0.1:8080`

No router port is opened. Cloudflare still provides DNS proxying, TLS, Tunnel,
and normal edge/WAF protections. Doorlink authenticates every dashboard page,
API read/write, event stream, and media response.

## 1. Keep or create the tunnel

In **Cloudflare Zero Trust → Networks → Tunnels**, keep the `doorbell-pi`
connector and its public hostname (replace these examples with yours):

- Hostname: `doorbell.example.com`
- Service: `HTTP`
- URL: `localhost:3000`

If the connector is not installed yet, use the Cloudflare-provided ARM64
installation command on the Raspberry Pi. Never commit its tunnel token.

## 2. Remove the interactive Access challenge

In **Zero Trust → Access → Applications**, remove the existing Smart Doorbell
self-hosted application, or add a highest-priority **Bypass** policy for this
exact hostname. Confirm in a private browser that Cloudflare no longer displays
an email/OTP page and Doorlink displays its own “device needs an invitation”
screen instead.

Do not point the tunnel directly at port 8080. Only the Next.js service on port
3000 should be public through the tunnel.

## 3. Configure the one-time owner bootstrap secret

On a trusted machine, generate a secret:

```bash
openssl rand -base64 32
```

Set it as `HOUSEHOLD_BOOTSTRAP_TOKEN` in the Pi checkout's ignored `.env` file,
then deploy/restart both gateway and dashboard. Visit:

```text
https://doorbell.example.com/setup
```

Enter the secret, owner details, and a recognizable device name. After setup,
remove `HOUSEHOLD_BOOTSTRAP_TOKEN` from `.env`; the bootstrap endpoint is also
permanently disabled by the stored owner record.

For isolated local development, provide the same variable when starting the
stack, for example `HOUSEHOLD_BOOTSTRAP_TOKEN=... ./scripts/run-dev.sh`.

The gateway stores only SHA-256 hashes of session and enrollment tokens.
Browser cookies are Secure, HttpOnly, SameSite=Lax, and renewed while a device
is used. The browser's practical 400-day cookie cap is handled by renewal, so an
active device remains signed in without a monthly prompt.

## 4. Add household devices

Open **Household** in Doorlink:

1. Add a person's name and email.
2. Copy the generated single-use enrollment link and send it privately.
3. They open the link on the exact phone/browser they want to enroll and give
   that device a name.
4. Repeat **New device link** for another browser or phone.

Enrollment links expire after 72 hours by default. They contain a short-lived
secret, so do not post them publicly. ntfy action links contain no bearer token;
they open the ordinary dashboard URL, where the device cookie authenticates the
browser.

The owner can revoke one device or remove a member (which revokes every device).
Revoked devices immediately lose new API and media access, any open event stream
is closed by the next 20-second heartbeat, and the browser is redirected to the
enrollment screen on its next page request.

## ntfy membership

Doorlink's current `ntfy.sh` topic is still a shared, hard-to-guess topic. Device
revocation in Doorlink does not remotely unsubscribe the ntfy mobile app. If
notification subscription must be revoked per person too, use authenticated
ntfy users/topic ACLs (hosted or self-hosted) and manage those subscriptions
separately. Never put a permanent Doorlink session token in an ntfy URL.

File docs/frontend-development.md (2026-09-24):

# Frontend development with live Raspberry Pi data

Use the dashboard-only development mode for rapid UI work. It runs Next.js on
the Arch development server with hot reloading while reading current sessions,
media, health, settings, and server-sent events from the Raspberry Pi gateway.

```bash
SMART_DOORBELL_DEV_GATEWAY_URL=http://192.168.1.10:8080 ./scripts/run-dashboard-dev.sh
```

Replace the example address with your Raspberry Pi gateway's LAN address.

The launcher starts scanning at port 3001 and prints the URL using the first
available port. For example, when another service already owns port 3001, the
dashboard normally starts at `http://localhost:3002`. Changes under
`dashboard/src/` should appear without rebuilding or deploying the production
dashboard.

From another computer, keep the service loopback-only and create an SSH tunnel
using the selected port. For port 3002:

```bash
ssh -L 3002:127.0.0.1:3002 user@dev-machine.local
```

You can then use `http://localhost:3002` in that computer's browser. For direct
access on a trusted LAN, set `SMART_DOORBELL_DEV_HOST=0.0.0.0`. Do not expose
the raw development port to the internet; place a development hostname behind
an authenticated tunnel such as Cloudflare Access.

The browser only talks to the local Next.js server. Next.js proxies reads to the
Pi gateway set in `SMART_DOORBELL_DEV_GATEWAY_URL`, so the browser does not need direct
database, MinIO, API-key, or CORS access. The development proxy blocks writes
to event, device, and settings data. Its one exception is the token-backed
device enrollment request, which creates a revocable browser session. Controls
such as push-to-talk and settings can still be styled in the UI, but cannot
change the Pi system while this launcher is in use.

## Enroll the local development browser

The local URL is a different browser origin from the deployed dashboard. Its
browser profile needs its own household device session to read private gateway
data.

1. Start `./scripts/run-dashboard-dev.sh` and note the URL it prints, including
   its selected port.
2. In an already-enrolled **owner** browser, open the deployed Doorlink
   **Household** page. Click **New device link** beside the owner account and
   copy the resulting single-use URL. Keep the token private.
3. Open the local URL from step 1 in the browser profile used for UI
   development. On the Access page, paste the entire link and click
   **Open enrollment here**. The app opens the enrollment path on `localhost`.
4. Name the browser, such as `Arch frontend dev`, and submit the enrollment
   form. The local origin now has its own revocable household session. Return
   to the printed local URL to view live data with hot reload.

The owner can later revoke this development browser from **Household**. If the
browser still returns to the access page after enrollment, check that the URL
uses the same hostname and browser profile as the enrollment page; cookies are
scoped to a hostname. Browsers that reject `Secure` cookies on a loopback HTTP
origin need an HTTPS local origin for this workflow.

To use a different gateway, host binding, or starting port:

```bash
SMART_DOORBELL_DEV_GATEWAY_URL=https://doorbell.example.com \
SMART_DOORBELL_DEV_HOST=127.0.0.1 \
SMART_DOORBELL_DEV_PORT=3002 \
./scripts/run-dashboard-dev.sh
```

If the requested starting port is occupied, the launcher continues scanning
upward until it finds a free TCP port.

Keep `GATEWAY_READ_ONLY=true` when the target is the production Pi. The existing
`./scripts/run-dev.sh` remains the mode for frontend/backend integration work
that needs writable, isolated Postgres, Mosquitto, and MinIO containers.

## Why the Pi gateway is the data boundary

Do not expose PostgreSQL or MinIO from the Pi to the development machine and do
not run the local Spring gateway against the Pi database. Reusing the gateway's
read APIs keeps schema handling, media access, and session serialization in one
place and makes the read-only boundary enforceable at the frontend proxy.

If stable or destructive test scenarios are needed later, take a one-way,
sanitized snapshot of Pi Postgres and MinIO into the isolated local stack rather
than writing tests against production data.

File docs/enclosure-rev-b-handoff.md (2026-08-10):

# Smart Doorbell Rev B Enclosure Handoff

This document condenses the enclosure/mechanical decisions for the wireless
battery-powered doorbell build. Use it as the starting context before changing
the KiCad Rev B PCB outline, mounting holes, or component placement.

## Target Product Shape

- Apartment-door-mounted, Ring-style doorbell.
- Mounted outside an apartment door using renter-friendly Command strips.
- Corridor is well lit and has decent ventilation.
- Interface is vertical along the longest enclosure dimension.
- Front interface layout:
  - Camera in the upper half, centered.
  - Status LED/light pipe near the camera.
  - Optional PIR below/near the status LED.
  - Main illuminated button near the bottom, centered.
  - Charging LED near the bottom.
  - Speaker, mic, and USB-C cutouts around sides and bottom.

## Enclosure Decision

Use a black, solid-cover `DS-AG-0813`-style ABS enclosure:

- Selected outside size: `80 x 130 x 70 mm` (`W x H x D`), with no external
  mounting ears.
- The catalogued enclosure uses a `50 mm` deep base and `20 mm` lid. Mount the
  PCB to the deep base/back side; use the lid as the hallway-facing front panel
  for the button, camera, PIR, and light-pipe openings.
- This is a compact, vertical doorbell form factor. It is a better visual fit
  than the previously considered `158 x 90 x 60 mm` and `115 x 90 x 55 mm`
  project boxes while retaining useful depth for the button and battery.
- Do not design the PCB around the enclosure's lid-screw pattern or molded
  bosses. Use custom standoffs fixed to the deep base instead.

Why this enclosure:

- The old `100 x 68 x 50 mm` box was too tight.
- The 22 mm button plus battery plus PCB stack caused the lid not to close.
- User dry-fit showed that even with the PCB basically sitting on the 10 mm
  battery, the `100 x 68 x 50 mm` enclosure could not fully close.
- The `80 x 130 x 70 mm` enclosure keeps a much more doorbell-like front
  profile and has more total depth than the old box.
- The present PCB outline is shaped for rounded corners: it is wide through
  its middle and narrow at its USB-C end. Preserve that advantage for the
  first fit instead of converting it to a plain rectangle.

Depth math:

- Old `100 x 68 x 50 mm` box measured roughly:
  - deep base internal depth: `33 mm`
  - lid internal depth: `12 mm`
  - total usable internal depth: about `45 mm`
- The selected enclosure has a catalogued `50 mm` base plus a `20 mm` lid.
- Button internal protrusion when mounted correctly through the front lid is
  about `31 mm`.
- PCB stack on the selected standoffs:
  - `10 mm` standoff + `1.6 mm` PCB + `5 mm` tallest JST = `16.6 mm`
- The available depth works only when the battery uses the side-wall/depth
  volume described below rather than stacking behind the button or PCB.

Catalog fit evidence for the standard `DS-AG-0813`:

- Reference: [Switch Box mechanical document](https://images.100y.com.tw/pdf_file/DMCA.pdf),
  pages 5-6. Treat this as the geometry reference for the standard mould; the
  exact marketplace enclosure may be a compatible clone and still needs
  measurement.
- Published outside dimensions: `130 x 80 x 70 mm` (`H x W x D`).
- Published dimension table: `H1/H2/H3/H4 = 130/124/112/100 mm`,
  `W1/W2/W3 = 80/74/62 mm`, and `D1/D2 = 50/20 mm`; stated tolerance is
  `+/-1 mm`.
- The matching internal mounting plate is `116 x 68 x 1.6 mm`.
- The current roughly `59 x 91 mm` board fits within that mounting-plane
  envelope with about `9 mm` total width margin and `25 mm` total height
  margin. This supports the current outline, but the actual purchased case
  still requires a physical fit check for ribs, bosses, and molding variation.

## Current PCB Context

Current KiCad source of truth:

- PCB file: `pcb/smart-doorbell/smart-doorbell.kicad_pcb`
- Current outline bounding box is roughly `59 x 91 mm`:
  - x range: `107.25..166.25`
  - y range: `55.95..146.95`
- Current mounting holes are M2.5:
  - footprint: `MountingHole_2.7mm_M2.5`
  - positions: `(111.05, 71.425)`, `(162.45, 71.425)`,
    `(111.05, 122.825)`, `(162.45, 122.825)`
  - current pattern: `51.4 x 51.4 mm`
- Current mechanically relevant footprints:
  - `MK1` ICS-43434 mic at `(110.95, 89.442)`
  - `J6` speaker JST-PH 2-pin at `(115.55, 98)`
  - `J7` PIR JST-PH 3-pin at `(155.25, 86.45)`
  - `J8` button/LED JST-PH 4-pin at `(133.65, 122.1)`
  - `J1` battery JST-PH 2-pin at `(158.442, 114.371)`
  - `J2` USB-C receptacle at `(136.85, 143.45)`

Do not stretch or scale the PCB to the enclosure. The existing outline is
already within the documented mounting-plane envelope. The USB-C end tapers to
about `41 mm`, which is useful around the enclosure's rounded end corners.

## Camera Module Target and FPC Contingency

The selected camera is the `DCXYX-LZTKQJ-5M-357-V1 FF`: the 120-degree
distortion-free, fixed-focus OV5640 24-pin DVP module. Fixed focus is the
intended production choice; autofocus is not a requirement for this doorbell.

The first 22 connector positions use the eight-bit DVP/SCCB/power arrangement
documented in the KiCad source. The seller drawing now recorded in
`docs/hardware/camera/README.md` identifies position 23 as `AF_GND` and position
24 as `AFVDD`. Rev B keeps both contacts isolated by default, with test pads and
normally-unpopulated configurable links:

- `J3.23` -> test pad -> `0R`, DNP -> GND (`AF_GND` contingency).
- `J3.24` -> test pad -> `0R`, DNP -> `+2V8` (`AFVDD` contingency).

For the selected fixed-focus camera, both `0R` resistors remain unpopulated and
neither pin connects to power, ground, GPIO, or pull resistors. Populate them
only after a specific autofocus module's pinout confirms pin 23 is `AF_GND`
and pin 24 is `AFVDD`. This is a future AF contingency, not a requirement for
the fixed-focus build.

Before powering the camera, inspect the received module and verify its pin-1
and exposed-contact orientation against the seller drawing. R11 and R21 remain
DNP for the selected fixed-focus camera.

## Recommended PCB Mechanical Direction

Keep the PCB at its current envelope for the first enclosure fit:

- Width target: current `58-59 mm` maximum; do not grow it.
- Height target: current `91 mm`; do not grow it.
- Preserve the tapered/scalloped edge treatment, especially around the USB-C
  end. Do not replace it with a full rectangle before the physical fit test.
- Do not chase the enclosure boss pattern.
- Use custom internal standoffs attached to the enclosure floor.
- Prefer the current M2.5 mounting direction:
  - PCB holes: `2.7-2.8 mm` NPTH.
  - Hardware: M2.5 machine screws, washers, and short threaded standoffs.

Mounting concept:

- Attach custom standoffs to the ABS floor using epoxy/plastic bonder.
- Do not epoxy the PCB itself.
- Do not use RTV silicone as the primary structural mount; it is too flexible.
- Neutral-cure silicone/E6000 is fine for strain relief and non-structural
  retention.
- Avoid acetic/vinegar-cure silicone near electronics.

Standoff process:

1. Screw standoffs loosely to the PCB.
2. Put a small amount of plastic-compatible epoxy on the bottom of each
   standoff.
3. Place the PCB into the enclosure at the exact final position.
4. Let cure with the PCB acting as the alignment jig.
5. Remove the screws and lift the PCB out.
6. Add a small epoxy fillet around each standoff base if needed.
7. Reinstall the PCB with nylon washers.

Standoff height:

- Use `10 mm` M2.5 female-to-female standoffs, OD ideally `<=5 mm`.
- Physical comparison with the received enclosure found that the existing
  `6 mm` standoffs are about `1 mm` shorter than the unused molded bosses.
  The `10 mm` selection provides useful tolerance above those bosses and more
  comfortable clearance for the silicone mic tube.
- The resulting PCB stack is about `16.6 mm` deep. The selected `70 mm`
  enclosure has adequate depth when the battery uses the right-side L-shaped
  placement and the button's rear keepout does not overlap the PCB laterally.
- Confirm actual boss clearance, screw engagement, wiring bends, and lid
  closure with a dry fit before bonding the standoffs.

Consider adding an extra support near the upper-left/mic area if the tube
preload causes board flex.

## Volume Allocation Inside Box

Do not stack everything in one depth column. Separate the mechanical volumes:

- Button barrel: front/lid area, lower center, must have a clear rear keepout.
- PCB: mounted flat to the back floor of the deep base on short standoffs.
- Battery: mounted to the right interior side wall in the forward portion of
  the deep base, not under the PCB and not behind the button.
- Speaker: wired/movable, mounted to bottom or side grille.
- Mic tube: short duct near the left side and `MK1`.
- Wiring gutters: use side/corner space.

The battery and PCB form an L-shaped volume: the PCB occupies the back plane;
the LiPo lies vertically on the right wall, with its `34 mm` dimension running
front-to-back. Keep the battery entirely on the deep-base side of the
lid/base seam. Never bond it to the lid or bridge the seam, because opening the
lid would flex the pouch and its leads.

## Battery

Existing battery:

- Type: `103450` LiPo.
- Dimensions: `50 x 34 x 10 mm`.
- Connector: JST-PH 2.0.
- Nominal voltage: `3.7 V`.
- Advertised capacity: `2000 mAh`.

Nothing is wrong with this battery. `103450` means approximately:

- `10 mm` thick
- `34 mm` wide
- `50 mm` long

Use it as the baseline/prototype battery. Capacity may be optimistic; treat it
as roughly `1500-2000 mAh` until measured.

Recommended placement:

- Mount battery to the right interior wall of the `80 x 130 x 70 mm` deep
  base. The right side keeps the left side free for the short `MK1` mic duct
  and is close to battery connector `J1`.
- Orientation:
  - `50 mm` dimension vertical.
  - `34 mm` dimension front-to-back.
  - `10 mm` thickness protruding inward from the side wall.
- Place it in the forward part of the deep base, away from the lower-centre
  button rear keepout and clear of the PCB's tallest components.

"Battery bay" means a reserved internal keepout/placement zone, not a separate
plastic part. The battery can sit against the ABS side wall, retained by
foam tape, adhesive Velcro, or a light strap.

Battery safety/mechanical notes:

- Do not clamp or compress the pouch.
- Use fishpaper/Kapton/plastic insulation between the LiPo and any PCB
  solder joints or hard edges.
- Do not rely on loose tape permanently.
- Bigger battery is okay only if thickness stays near `10 mm`; larger
  footprint is less risky than greater thickness.

## Button

Current button:

- 22 mm illuminated metal momentary button.
- White LED.
- LED voltage listing: `3-6 V` / `5 V`.
- Rear depth from listing: about `33 mm`.
- When mounted correctly through the front lid with face/gasket outside the
  enclosure, internal protrusion is about `31 mm`.
- Blue rear harness/socket makes total depth too long and should be removed.

Keep the current 22 mm button. The button is not the main problem if the
battery is side-mounted and the PCB does not stack behind it.

Button wiring:

- Use JST-PH 2.0 4-pin 26 AWG pigtail if it matches PCB connector `J8`.
- Solder pigtail wires directly to the button tabs.
- Use heat shrink over each soldered terminal.
- Do not friction-fit bare wires.
- Do not use the original 18 AWG harness wires unless necessary; they are
  mechanically bulky.

Button pinout:

- Red: NC, leave unused and insulated.
- Blue: NO, connect to doorbell signal.
- Black: C/common, connect to button common/GND side.
- Yellow: LED positive.
- Green: LED negative.

PCB `J8` pin mapping:

- `J8 pin 1`: `/DOORBELL_IN` -> button NO/blue.
- `J8 pin 2`: `GND` -> button C/black.
- `J8 pin 3`: button LED positive path via `R9=330` to `/BTN_LED` -> yellow.
- `J8 pin 4`: `GND` -> LED negative/green.

Verify JST pigtail wire order by continuity. Do not assume AliExpress color
order matches the PCB pin order.

## Microphone

Current mic:

- `MK1`: ICS-43434 I2S MEMS microphone.
- It is a bottom-port mic.
- The KiCad footprint includes a small non-plated acoustic hole through the
  PCB under the mic.
- Sound enters from the underside of the PCB, not from the top of the mic
  package.

Existing material:

- Silicone tubing: `2 mm ID x 4 mm OD`, 1 meter.

Accepted mechanical concept:

- Use the silicone tube as a side-tapped acoustic duct/manifold under the PCB.
- The tube should be mic-only. Do not share the speaker grille.
- Because `MK1` is already near the upper-left side of the PCB, the duct can be
  short.

Recommended mic duct:

```text
left side wall mic hole
-> open tube end against side-wall mic hole
-> short tube run under PCB near MK1
-> small upward-facing window/slit in tube wall aligned to PCB mic acoustic hole
-> tube continues 5-10 mm past MK1
-> far end sealed
```

Details:

- Exterior mic hole: about `1.0-1.5 mm`.
- Tube window under mic: start about `1 mm`, enlarge only if needed.
- Align the tube window to the PCB acoustic hole, not just the `MK1` package
  outline.
- Use tape only for dry fit.
- Final sealing/retention: neutral-cure silicone, E6000, or similar flexible
  adhesive.
- Do not let adhesive block the PCB acoustic hole or tube bore.
- Add PCB keepout around the under-board tube path.
- The selected `10 mm` standoffs provide comfortable tube clearance. Retain
  the tube without enough preload to bow the PCB.

Avoid:

- Long curved mic tube paths.
- Routing mic to the speaker grille.
- Leaving the mic to listen only to the sealed enclosure interior.
- Moving the mic off-board unless the PCB-mounted solution fails.

## Speaker

Previously tested speaker:

- 8 ohm, 1 W, small oval speaker.
- Size: `24 x 15 mm`.
- This unit passed the original conservative J6 electrical bring-up but was
  judged too small, quiet, and tinny for the enclosure target.

Current construction target, recorded 2026-08-10:

- One speaker from a five-piece pack described by the seller as `4 ohm`,
  `3 W`, with a `2.0` terminal.
- Outdoor metal speaker cover mounted inside the enclosure between the speaker
  and the cutout in the ABS panel.
- Verify the received speaker dimensions, terminal housing/latch, pin order,
  polarity, and cover geometry before machining. The seller photo is not a
  dimensional drawing, and `2.0` does not by itself prove JST-PH compatibility.
- The 3 W marking is speaker power handling, not guaranteed board output. U4
  is powered from `/SYS`; the MAX98357A's advertised 3.2 W into 4 ohms is a
  5 V condition, while this design does not provide U4 a dedicated fixed 5 V
  speaker rail.

Recommended placement:

- Prefer a bottom- or side-facing grille for water shedding. A forward-facing
  installation is acceptable only with full cover overlap, a perimeter gasket,
  and suitable water protection.
- Keep away from mic grille/tube.
- Use a foam/EVA perimeter gasket to couple the speaker to the metal cover and
  prevent front-to-rear acoustic leakage.
- Cut one controlled opening behind the metal cover rather than improvising a
  visible hole pattern. Size it from the measured diaphragm, cover open area,
  and bonding flange.
- A metal cover is not a water barrier. Add a hydrophobic acoustic membrane if
  outdoor exposure requires one.

Electrical caution:

- Speaker connector `J6` is driven by the MAX98357A bridged output.
- Do not connect either speaker lead to ground.
- Do not connect multiple speakers to J6.
- Retain the populated R32 6 dB gain strap and determine maximum usable output
  through digital level, clipping, current, and temperature testing.

See the [enclosure construction guide](enclosure-construction-guide.md) for
the speaker stack, tools, cutout method, assembly order, and acceptance tests.

## Light Pipe And LEDs

Existing light-pipe parts:

- LPA3.5 light guide column.
- Purchased size: `LPA3.5-21.1 mm`.
- Ten clear acrylic rods, `3 mm x 100 mm`.
- Ten black `3 mm` panel-mount clip LED bezels.

Likely issue:

- `21.1 mm` is a test/spare part, not a presumed final fit. With the PCB
  mounted to the rear/deep base on 10 mm standoffs, the likely LED-to-inner-lid
  distance is roughly `51-56 mm`; confirm this only with the actual enclosure
  and installed PCB.

Final light-pipe construction:

- Use the `3 mm` acrylic rods with the matching `3 mm` black panel-mount
  bezels. The bezel is the intentional, finished front-panel interface; do
  not glue a short LPA3.5 part to a rod.
- The bezel's nominal `3 mm` describes the LED/rod it accepts, not necessarily
  its required panel-hole diameter. Obtain the seller's dimension drawing or
  test one in scrap ABS before drilling the enclosure. Confirm its clip tabs
  work with the actual enclosure wall thickness.
- Cut the finished pipes slightly long and trim in small steps. Use a fine
  hobby/razor saw, then sand the end flat (`400 -> 800 -> 1200` grit). An
  X-Acto knife may score the material but is not the preferred cutter for a
  clean, square optical end.
- Leave about `0.25-0.5 mm` axial clearance rather than preloading the PCB LED
  or front lid.
- Insert the rod from the enclosure interior and retain its rear with a small
  black sleeve/stop plus a tiny neutral-cure silicone dab. Keep adhesive away
  from the visible optical end; do not use Loctite 404 for an optical joint.
- Keep the light pipe path vertical/straight where possible.

## PIR Sensor

Existing PIR:

- AM312 module.
- Dome/head diameter: about `13 mm`.
- Approximate depth from head to end of 3 pins: `25 mm`.

Recommendation:

- Treat PIR as optional/future.
- Do not rigidly plug the AM312 into the PCB if that creates mechanical stress.
- Prefer wiring it to `J7` with a short pigtail and mounting it to the front
  lid.
- Reserve front-panel keepout now if PIR is desired later.

PCB `J7` pin mapping:

- `J7 pin 1`: `+3V3`
- `J7 pin 2`: `PIR_SENSOR_OUT`
- `J7 pin 3`: `GND`

The default Rev B path is J7.2 `PIR_SENSOR_OUT` through populated R30 (1 kohm)
to `PIR_WAKE` on GPIO3. R29 (100 kohm) is the pulldown. GPIO42 is only the DNP
fallback through R31 and must not be treated as the default PIR input.

## USB-C

- USB-C connector is on bottom edge (`J2`).
- Keep bottom enclosure cutout aligned with USB-C.
- Do not place a standoff/boss directly below the USB-C port.
- This is one reason not to use the enclosure's bottom molded boss spacing for
  PCB mounting.

## Holes And Tools

Existing tools/materials:

- 4-32 mm HSS titanium-coated step drill bit for larger ABS holes.
- Smaller Ryobi drill bits for small IO/interface holes.
- Sandpaper for ABS rough edges.
- Heat shrink tubing.
- JST-PH 2.0 pigtails, including 4-pin 26 AWG.

Use:

- Step bit for button and larger clean ABS openings.
- Small bits for speaker grille, mic hole, charging/status LED hole, and pilot
  holes.
- A Dremel 4000 is useful for non-round speaker and USB-C openings when paired
  with a 561/561HP plastic-cutting bit and 565 depth guide. Cut inside the line
  and hand-file to final size; do not freehand the visible finish edge.
- Sandpaper/deburring after drilling.
- Heat shrink on soldered button terminals.

The construction workflow and per-opening methods are maintained in the
[enclosure construction guide](enclosure-construction-guide.md).

## Hardware Shopping List

Core mechanical:

- Black `DS-AG-0813`-style `80 x 130 x 70 mm` solid-cover ABS enclosure;
  preferably buy a spare.
- M2.5 female-to-female threaded standoffs, `10 mm` length, OD ideally
  `<=5 mm`.
- M2.5 machine screw assortment matched to standoff length.
- M2.5 nylon washers.
- Plastic-compatible epoxy or JB Weld Plastic Bonder.
- Optional E6000 or neutral-cure silicone for strain relief and acoustic seals.
- Fishpaper/Kapton/plastic insulation sheet.
- Thin foam tape, adhesive Velcro, or light battery-retention strap.
- Foam/EVA speaker gasket material.
- Optional acoustic vent membrane stickers for mic/speaker dust protection.

Optional replacements/upgrades:

- Bigger LiPo only if thickness remains around `10 mm`; avoid thick packs.

## KiCad Modification Approach

Before editing:

1. Start from a clean checkpoint or commit.
2. Keep `pcb/smart-doorbell/` as source of truth for routed nets.
3. Use current project guide pin mappings:
   - `AMP_EN`: GPIO44
   - `PIR_WAKE`: GPIO3 through populated R30
   - GPIO42: DNP PIR fallback through R31 / AUX contingency
   - USB native D-/D+: GPIO19/GPIO20 only

Recommended KiCad process:

1. Add mechanical reference geometry on a non-fabrication drawing layer:
   - `DS-AG-0813` enclosure mounting plane / inner envelope
   - front/lid plane
   - button rear keepout cylinder
   - side battery bay
   - mic tube path
   - speaker grille region
   - USB cutout region
2. Keep critical electrical layout stable at first:
   - ESP32-S3 module
   - camera FPC connector
   - USB-C connector
   - mic and local support parts
   - power/audio support passives
3. Keep the present outline for the first dry fit. Adjust it only when a
   measured enclosure interference requires a change.
4. Place mounting holes for custom standoffs, not molded enclosure bosses.
5. Preserve or improve support around the mic/tube area.
6. Resolve any routing damage after the mechanical geometry is set.
7. Re-run DRC/ERC.
8. Export a 1:1 paper/cardboard outline and physically test it inside the real
   enclosure with button, battery, speaker, and mic tube.

## Open Items For Next Session

- Measure the received black `80 x 130 x 70 mm` enclosure and confirm its
  internal ribs/bosses against the documented `DS-AG-0813` geometry (which
  permits `+/-1 mm`).
- Dry-fit the unmodified PCB, including its USB-C connector, before changing
  the outline or ordering another board.
- Confirm the final PCB position and USB-C bottom cutout.
- Dry-fit the selected `10 mm` standoffs and confirm molded-boss clearance,
  screw engagement, component clearance, and lid closure.
- Dry-fit the right-wall L-shaped battery placement, the lower-centre button,
  speaker, and left-side mic tube together.
- Confirm whether to add a fifth support point near `MK1`.
- Treat the stock enclosure's ingress rating as void after drilling camera,
  button, USB-C, microphone, and speaker openings unless those openings receive
  appropriate gaskets or acoustic membranes.

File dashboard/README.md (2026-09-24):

# Doorlink dashboard

The Next.js dashboard displays doorbell events, stored media, and turn-based voice replies from the [Spring Boot gateway](../gateway/). See the [project overview](../README.md) for hardware and validation status.

For the complete local stack, install dependencies with `npm ci` in this directory, then run `./scripts/run-dev.sh` from the repository root. The dashboard opens at [localhost:3001](http://localhost:3001).

To run only the dashboard against an already running gateway:

```bash
GATEWAY_URL=http://127.0.0.1:8081 npm run dev -- -p 3001
```

The gateway handles authentication, media, and notifications. [Frontend development notes](../docs/frontend-development.md) cover remote gateway testing.

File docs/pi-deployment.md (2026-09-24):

# Raspberry Pi Deployment Guide

This document outlines the deployment topology for the Smart Doorbell system on the local Raspberry Pi 4 gateway.

## Network Topology

- **Host:** Raspberry Pi 4 (4GB)
- **Local IP Address:** assign the Pi a stable LAN address; examples below use `192.168.1.10`.

### Active Services & Ports

| Service | Port | Description |
| :--- | :--- | :--- |
| **Dashboard (Next.js)** | `3000` | The web interface for viewing events and interacting with the doorbell. |
| **Gateway (Spring Boot)**| `8080` | The main backend API that the firmware communicates with. |
| **Mosquitto (MQTT)** | `1883` | Message broker for half-duplex audio and device commands. |
| **MinIO (S3 Storage)** | `9000` | Local object storage for saving event images and audio. (Console on `9001`) |
| **PostgreSQL** | `5432` | Relational database for storing event metadata. |

## Running the Services

The deployment relies on a hybrid approach: Docker Compose runs infrastructure containers, while systemd manages the Spring Boot gateway and Next.js dashboard services. The unit files are tracked in `scripts/systemd/`.

### 1. Infrastructure (Docker Compose)
The database, message broker, and media storage are containerized. On the Pi, systemd runs `smart-doorbell-infra.service` at boot to execute `docker compose up -d` from the repository root before the gateway starts.

Manual command:

```bash
cd /home/ethioprince/dev/smart-doorbell
docker compose up -d
```

### 2. Build Production Artifacts On Arch

The Raspberry Pi systemd services are production runtime services. They must not run `./mvnw spring-boot:run` or `npm run dev`; those commands keep build/watch tooling alive and can cause large CPU spikes on the Pi.

Build the runtime artifacts in the Arch development checkout. The gateway JAR is
architecture-neutral. The dashboard is built as a traced standalone server
through Docker Buildx. Compilation runs natively on the fast Arch CPU, and the
script refuses to deploy the result if tracing ever introduces an x86 runtime
binary. The current standalone runtime is portable JavaScript and assets.

```bash
cd /home/ethioking/dev/smart-doorbell
./scripts/build-pi-production.sh
```

This creates:

- `dist/pi-production/gateway/gateway.jar`
- `dist/pi-production/dashboard/server.js` and its traced standalone runtime

Native compilation and Docker layer caching make later dashboard builds
substantially faster. The Pi does not need Maven, npm dependency installation,
TypeScript compilation, or a Next.js production build.

Build and deploy both components without restarting them:

```bash
./scripts/build-pi-production.sh --deploy
```

For the quickest edit/build/deploy/restart loop, target only the changed part:

```bash
./scripts/build-pi-production.sh --dashboard-only --restart
./scripts/build-pi-production.sh --gateway-only --restart
```

`--restart` is the only option that restarts Pi services. The default command
only builds local artifacts. The host defaults to the `rpi` SSH alias; override
it with `DOORBELL_PI_HOST` if needed. Releases are installed under
`.pi-production/<component>/releases/`, and an atomic `current` symlink keeps
each systemd service on a complete artifact set. Unchanged files in consecutive
releases are hard-linked to reduce transfer time and disk use.

The first time this workflow is installed, pull the tracked changes on the Pi,
copy the gateway and dashboard units as described below, and run
`sudo systemctl daemon-reload`. The build script checks the installed unit paths
before it permits `--restart`, so an old unit cannot silently launch a stale
artifact.

### 3. Install Or Refresh Systemd Units

After changing files under `scripts/systemd/`, copy them into systemd and reload:

```bash
cd /home/ethioprince/dev/smart-doorbell
sudo cp scripts/systemd/smart-doorbell-gateway.service /etc/systemd/system/
sudo cp scripts/systemd/smart-doorbell-dashboard.service /etc/systemd/system/
sudo cp scripts/systemd/smart-doorbell-infra.service /etc/systemd/system/
sudo systemctl daemon-reload
sudo systemctl enable smart-doorbell-infra.service
```

### 4. Infrastructure Service
The Docker Compose bootstrap is managed by `smart-doorbell-infra.service`.
```bash
sudo systemctl status smart-doorbell-infra.service
sudo systemctl restart smart-doorbell-infra.service
journalctl -u smart-doorbell-infra.service -f
```

### 5. Backend Gateway
The Spring Boot gateway is managed by `smart-doorbell-gateway.service`.
```bash
sudo systemctl status smart-doorbell-gateway.service
sudo systemctl restart smart-doorbell-gateway.service
journalctl -u smart-doorbell-gateway.service -f
```

### 6. Frontend Dashboard
The Next.js dashboard is managed by `smart-doorbell-dashboard.service`.
```bash
sudo systemctl status smart-doorbell-dashboard.service
sudo systemctl restart smart-doorbell-dashboard.service
journalctl -u smart-doorbell-dashboard.service -f
```

Application builds no longer run on the Pi. Pull source changes only when the
tracked deployment configuration changed. Normal application iteration uses the
Arch build command with `--restart` and targets only the changed component.

## Emergency CPU Recovery

If SSH or the local TTY is already sluggish because the old dev-mode services are consuming CPU, stop the app services first, then build and restart them with the production units:

```bash
sudo systemctl stop smart-doorbell-dashboard.service smart-doorbell-gateway.service
cd /home/ethioprince/dev/smart-doorbell
git pull
sudo cp scripts/systemd/smart-doorbell-gateway.service /etc/systemd/system/
sudo cp scripts/systemd/smart-doorbell-dashboard.service /etc/systemd/system/
sudo cp scripts/systemd/smart-doorbell-infra.service /etc/systemd/system/
sudo systemctl daemon-reload
sudo systemctl enable smart-doorbell-infra.service
sudo systemctl restart smart-doorbell-infra.service
```

Then return to Arch and deploy prebuilt artifacts with
`./scripts/build-pi-production.sh --restart`.

If CPU spikes persist after this, capture evidence while the spike is happening:

```bash
cd /home/ethioprince/dev/smart-doorbell
./scripts/pi-cpu-snapshot.sh
```

The script prints the path to a log under `/tmp/smart-doorbell-diagnostics/` with process CPU usage, memory pressure, Docker stats, and recent service logs.

## Gateway environment

Before deploying a gateway build from the public configuration, set these values in the Pi's ignored `.env` file. The checked-in defaults use localhost and leave Home Assistant chimes disabled.

```dotenv
INTERCOM_DEVICE_BASE_URL=http://192.168.1.10:8080
DASHBOARD_URL=https://doorbell.example.com
CHIME_PROVIDER=homeassistant
CHIME_HOMEASSISTANT_WEBHOOK_URL=http://192.168.1.10:8123/api/webhook/your-private-id
```

Replace the addresses and private webhook ID with your own. If Home Assistant is not used, set `CHIME_PROVIDER=none` and omit its webhook URL. Keep the webhook ID out of git.

## Firmware Configuration (`config.h`)

For the ESP32-S3 firmware to successfully communicate with this Pi, ensure your `main/config.h` reflects the following:

```c
#define WIFI_SSID "Your_WiFi_SSID"
#define WIFI_PASSWORD "Your_WiFi_Password"

// Gateway API for image/audio HTTP POSTs
#define GATEWAY_API_URL "http://192.168.1.10:8080/api/events"
#define GATEWAY_API_KEY "the-same-high-entropy-value-as-the-Pi-environment"

// MQTT Broker for half-duplex interaction
#define MQTT_BROKER_URI "mqtt://192.168.1.10:1883"
```

`GATEWAY_API_KEY` is also the HMAC key for MQTT intercom commands. The firmware
rejects unsigned commands, changed command fields, and replayed command IDs.
Deploy the matching gateway build before flashing this firmware:

```bash
./scripts/build-pi-production.sh --gateway-only --restart
```

The gateway's `intercom.device-base-url` and firmware `GATEWAY_API_URL` must use
the same scheme, host, and port. Firmware accepts reply media only from the
gateway's `/api/events/media/<key>` route and acknowledgements only on the
matching `/api/system/ptt/messages/<uuid>/delivered` route. Redirects are not
followed when the hardware API key is attached.

## External Access (WAN)

To securely access the Next.js Dashboard and Gateway API from outside the local network without exposing ports to the public internet, we use **Cloudflare Tunnel** (`cloudflared`) plus Doorlink's revocable household-device sessions.

See `docs/cloudflare-tunnel.md` for the Cloudflare Tunnel and Access configuration.

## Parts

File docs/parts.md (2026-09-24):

# Main unit parts and cost

One assembled Rev C doorbell in its enclosure. Prices are in Canadian dollars and are allocated from the purchase quantities supplied for this build. The PCB row includes five fabricated boards with JLCPCB assembly; the ESP32-S3 and microphone were purchased separately. This is a build cost record, not a shopping list or a quote for a new order.

| Part | Used per unit | Purchase (CAD) | Purchased quantity | Allocated to one unit (CAD) |
| --- | ---: | ---: | ---: | ---: |
| Rev C PCB, fabricated and assembled | 1 | $190.45 | 5 boards | $38.09 |
| ESP32-S3-WROOM-1-N16R8 | 1 | $6.41 | 1 | $6.41 |
| ICS-43434 microphone | 1 | $13.78 | 5 | $2.76 |
| 103450 LiPo battery | 1 | $12.99 | 2 | $6.50 |
| MF52D B3950 10 kΩ battery thermistor | 1 | $1.93 | 10 | $0.19 |
| OV5640 camera module | 1 | $9.43 | 1 | $9.43 |
| 22 mm illuminated button | 1 | $6.02 | 1 | $6.02 |
| 4 Ω, 3 W speaker | 1 | $8.25 | 5 | $1.65 |
| Speaker grille | 1 | $6.43 | 2 | $3.22 |
| ABS enclosure | 1 | $19.08 | 1 | $19.08 |
| AM312 PIR module | 1 | $2.31 | 2 | $1.16 |
| 3 mm light pipes | 2 | $4.52 | 10 | $0.90 |
| Plastic lamp bases | 2 | $2.42 | 10 | $0.48 |
| PCB standoffs | 4 | $2.56 | 10 | $1.02 |
| M2.5 spacers | 4 | $2.27 | 100 | $0.09 |
| Hook-and-loop battery fastening, hard/soft pair | 1 pair | $1.82 | 1 pair | $1.82 |
| **Known allocated subtotal** | | | | **$98.82** |

The thermistor and PIR are installed. PIR event wake is currently disabled in firmware and can be enabled with a firmware update. The subtotal uses unrounded unit allocations, so it can differ by a cent from adding the displayed rows.

Less than 5 cm of the 1 m silicone microphone sound pipe was used. At $3.83 per metre, its share is under $0.20 and is excluded from the subtotal because the exact length was not recorded.

Small assembly consumables and wiring, including screws, washers, connectors, adhesive, and speaker gasket material, are not priced here. The Raspberry Pi gateway, its power supply, and storage are also outside this **main enclosure** cost.

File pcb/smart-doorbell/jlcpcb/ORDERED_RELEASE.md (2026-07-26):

# Smart Doorbell Rev B ordered release

This directory records the exact PCB/PCBA package submitted to JLCPCB and paid
on 2026-07-15. The local files were independently rehashed after submission.

## Ordered upload files

| Purpose | File | SHA-256 |
| --- | --- | --- |
| Fabrication | `production_files/GERBER-smart-doorbell.zip` | `308147675567d52b2c969652221e89e74eb338f233dc546a0f6a8c3fbe2cefe4` |
| Assembly BOM | `production_files/BOM-smart-doorbell.csv` | `259df70355df98f8d69fe8e36467e864358dbc74648b01cfa6c947faa1909097` |
| Placement | `production_files/CPL-smart-doorbell.csv` | `4568b054b96dbd2f7c47d4aba105d7f1d151f0aa36835294cef4a8d51ea8b242` |

Run `sha256sum -c ORDERED_RELEASE.sha256` from this directory for a
machine-readable verification of all three files.

JLCPCB PCB order: `Y7-6841583A`. The signed-in PCBA order page displayed the
prefix `SMT026071560509`. The order contained five PCBs and five top-side
economic PCBA assemblies.

## Delivered hardware

The physical Smart Doorbell Rev B boards now in hand were received on
2026-07-23 from the following retained JLCPCB order:

| Item | Identifier |
| --- | --- |
| JLCPCB web order | `W2026071513150300` |
| PCB order | `Y7-6841583A` |
| PCBA order | `SMT026071560509` |

This is the batch whose final DFM placement review was completed before
shipment. It is the only valid physical baseline for Rev B bring-up. The later
duplicate order (`W2026071513290609`, PCB `Y8-6841583A`, PCBA
`SMT026071560541`) was cancelled and must not be used as a hardware reference.

## Source and generation provenance

| Item | Saved/generated timestamp (America/Toronto) |
| --- | --- |
| Schematic | 2026-07-14 19:24:03.678626984 -0400 |
| PCB | 2026-07-14 23:39:10.332831080 -0400 |
| CPL | 2026-07-14 23:39:10.802850493 -0400 |
| BOM | 2026-07-14 23:39:10.804061473 -0400 |
| Corrected top mask | 2026-07-14 23:39:11.101603061 -0400 |
| Fabrication ZIP | 2026-07-14 23:39:11.161865321 -0400 |

The package was generated with KiCad 10.0.4 and kicad-jlcpcb-tools. Project-local
LCSC assignments and placement corrections are in `project.db`.

The plugin omitted top-mask apertures for NPTH pads. Its configured
post-generation hook, `../../../scripts/fix-jlcpcb-mask.sh`, replaced the top
mask with a KiCad-native plot, verified the 0.5 mm MK1 acoustic aperture and all
four 2.7 mm mounting-hole apertures, rebuilt the 13-member ZIP, and tested the
embedded result.

The assembly package contains 37 BOM groups and 84 unique top-side placements.
Its per-reference LCSC assignments match
`../production/Smart_Doorbell_Project_B_bom-JLCPCB_FINAL.csv`. The intended 23
hand-solder, DNP, test-point, and mechanical references are absent from both BOM
and CPL.

The saved DRC report has one known source-metadata parity warning: R37 has a
blank PCB `LCSC Part #` field while the schematic carries `C21190`. R37 is DNP
and is absent from both ordered assembly files, so this does not change the PCB
or PCBA package. The two excluded J2 silkscreen-to-edge warnings are intentional
for the USB-C connector overhang.

## Post-order rule

Saving or editing the local KiCad project cannot alter the files already held by
JLCPCB. It can, however, make these manufacturing outputs older than the source
files. Do not regenerate, replace, or re-upload an ordered file without treating
the result as a new release candidate and repeating the manufacturing review.

At the time of this snapshot, JLCPCB data preparation was still pending. Final
CAM/DFM files must be checked against this Rev B release before production-file
approval.

The corrected ordered Rev C package is isolated under `rev-c/` with its own
manifest, hashes, and signed-off JLCPCB evidence. None of those files replaces
the three Rev B uploads above.
`sha256sum -c ORDERED_RELEASE.sha256` must continue to pass from this directory;
run the separate `ORDERED_RELEASE.sha256` check from `rev-c/` for Rev C.

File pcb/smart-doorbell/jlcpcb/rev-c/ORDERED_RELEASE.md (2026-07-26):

# Smart Doorbell Rev C ordered release

This directory records the isolated Rev C PCB/PCBA package submitted to JLCPCB
on 2026-07-26 as the minimum five-board prototype batch. It does not replace or
modify the immutable Rev B order recorded in `../ORDERED_RELEASE.md`.

## Exact ordered upload files

| Purpose | File | SHA-256 |
| --- | --- | --- |
| Fabrication | `production_files/GERBER-smart-doorbell.zip` | `7ebd19abdf2506559d982eb9ccf2855b6e97c4294295550f7871b72116f74491` |
| Assembly BOM | `production_files/BOM-smart-doorbell.csv` | `b8c32a878c7caabdf3b9f238a1eec08a2a92a1a69c329369d7b5a2bb62ae5043` |
| Placement | `production_files/CPL-smart-doorbell.csv` | `bb05144a3e20f71e30b5ff7071b05e1eb57f1dc3faacc909f88bdab1a21b15aa` |

Run `sha256sum -c ORDERED_RELEASE.sha256` from this directory whenever checking
the exact submitted package. Do not substitute files from the parent Rev B
paths or from `pcb/smart-doorbell/production/`.

These three hashes define the exact Rev C order identity. The tracked bytes and
hash manifest are immutable order evidence; any later regeneration is a new
release candidate.

## Source and generation provenance

- KiCad source title blocks: Smart Doorbell Project, revision C.
- Gerber generator: KiCad Pcbnew 10.0.5.
- Gerber generation timestamp: `2026-07-26T05:11:30-04:00`.
- Gerber project metadata: revision C.
- Git release tag: `pcb-rev-c-ordered-2026-07-26`.
- Project-local plugin database snapshot: `project.db`
  (`02549d60fb4e8063091f892665035068eef0c9bd039da6491a4b0a322385b46e`).
- Camera symbol library: `../../ov5640_pinout.kicad_sym`, referenced through
  `../../sym-lib-table`.
- Top-mask post-processing: `../../../../scripts/fix-jlcpcb-mask.sh`.

The exact source content used for this freeze was:

| Source | SHA-256 |
| --- | --- |
| `../../smart-doorbell.kicad_pcb` | `a29030c30a896c481777cf684eb9f4e7a3ffd209cc45e68b115e549563aee3d0` |
| `../../smart-doorbell.kicad_sch` | `32523098141959951881cd6337a0f85f3e38096cae66ab706157dfb62308d481` |
| `../../smart-doorbell.kicad_pro` | `f4404cd6d46fe735ec5cfc337edff98ec06ce8cfc56d595d8b6d1a6f49f1079d` |
| `../../ov5640_pinout.kicad_sym` | `064e62d8f5685142a9031123e77b1df5f2efce731c3e43bdf72688f9a9682b8a` |

All 108 PCB footprints are locked in this saved PCB source. Lock flags do not
change fabrication geometry; the regenerated package was independently
compared with a fresh KiCad export using the plugin's solder-mask subtraction
and routed-slot options.

The 13-member fabrication ZIP contains files byte-for-byte identical to the
adjacent `gerber/` directory. The native top mask contains the 0.5 mm MK1
opening and all four 2.7 mm mounting-hole openings, including the corrected
lower-hole Y coordinate of 128.825 mm.

## Assembly record

The BOM and CPL contain the same 85 unique top-side references. All inherited
Rev B references retain the exact value/LCSC assignment recorded by
`../../production/Smart_Doorbell_Project_B_bom-JLCPCB_FINAL.csv`.

The intentional population delta from that protected record is:

| Action | Reference | Value / part | LCSC |
| --- | --- | --- | --- |
| Add | C35 | 1 uF | C15849 |
| Add | R37 | 1 kOhm | C21190 |
| Add | U9 | TPS22919DCKR | C2149796 |
| Remove / DNP | R26 | 10 kOhm fixed THERM resistor | C15401 |
| Remove / DNP | R36 | 0 ohm camera-power bypass | C21189 |

U9 is top-side with a CPL rotation of 180 degrees. The generated top copper and
paste each contain all six U9 pad apertures. R31 remains DNP, so populated R37
dedicates GPIO42 to `CAM_PWR_EN`. R11 and R21 remain DNP camera contingency
links. U1 and MK1 remain hand-soldered.

J5 is only an external thermistor connection. No NTC is included in this BOM;
do not charge a battery until a suitable 10 kOhm-at-25-degrees-C NTC is wired
to J5 and thermally attached to the cell.

## Reproducible local gates

Run from the repository root:

```bash
python3 scripts/verify-camera-interface.py
python3 scripts/verify-rev-c-release.py

kicad-cli sch erc --severity-all --exit-code-violations \
  --output /tmp/smart-doorbell-rev-c-erc.rpt \
  pcb/smart-doorbell/smart-doorbell.kicad_sch

kicad-cli pcb drc --schematic-parity --all-track-errors \
  --severity-all --exit-code-violations \
  --output /tmp/smart-doorbell-rev-c-drc.rpt \
  pcb/smart-doorbell/smart-doorbell.kicad_pcb
```

The ERC report may include only the intentionally excluded MAX98357A exposed-pad
warning. The DRC report may include only the two intentionally excluded USB-C
silkscreen warnings. Any other violation blocks upload.

## JLCPCB BOM and assembly-preview sign-off

Status: **signed off before order**.

- [x] The JLCPCB BOM-matching export contains the same 85 unique references as
      the ordered BOM and CPL.
- [x] All 38 matched rows retain the expected value, package, and JLCPCB/LCSC
      part number.
- [x] All placements are top-side; no bottom designators are present.
- [x] U9 pin 1 matches the PCB pin-1 marker and its 180-degree CPL orientation.
- [x] J3 pin 1 is at the `CAM24 / J3-1` end and the flex opening faces the
      `FLEX ENTRY` label.
- [x] U2, U4, U5, U6, U7, U8, D2, D3, J1-J4, and J6-J8 orientations match the
      Gerber overlay.
- [x] U1, MK1, R11, R21, R26, R31, R36, J5, J9, TP1-TP10, and H1-H4 are not
      placed.
- [x] BOOT1 and RESET1 use the intended B3U-1000P, C231329. The JLCPCB
      multiple-match warning was reviewed and accepted.
- [x] No substitutions, unresolved parts, bottom-side placements, or quantity
      changes remain.

| Field | Sign-off |
| --- | --- |
| Reviewer | Codex independent release audit; BOOT1/RESET1 confirmed by Caleb Habesh |
| Date | 2026-07-26 |
| Order timestamp (as supplied) | `2026-07-26 06:01:45` |
| PCB prototype ID | `Y9-6841583A` |
| PCBA ID | `SMT026072660566-6841583A` |
| Related web-order ID | `W2026072618014602` |
| Assembly quantity | Five top-side PCBAs |
| Preview evidence | `evidence/JLCPCB-assembly-preview-top.png` |
| BOM-match evidence | `evidence/JLCPCB-BOM-matching-2026-07-26.xlsx` |
| Evidence hashes | `ORDER_EVIDENCE.sha256` |
| Result | PASS — approved for the minimum Rev C prototype order |

The BOM evidence was downloaded from JLCPCB at
`2026-07-26 17:48:43`, identifies five assembled boards, and records an
estimated matched-parts total of `$57.3764`. Its 38 groups expand to the same
85 references as the ordered BOM/CPL. The source `JLCPCB Part #` column is
blank because the rows were selected by JLCPCB's matching system, but every
resulting matched part number was independently compared with the protected
assignments and passed.

## Post-order rule

Saving or editing the local KiCad project cannot alter the files already held
by JLCPCB. Do not regenerate, replace, or re-upload any ordered file. Any
future manufacturing output must use a new release directory, manifest, and
complete review.

This order establishes manufacturing-package and preview approval only. It
does not establish successful camera startup, OV5640 capture, current
consumption, charger/thermistor behavior, battery protection or polarity, RF
performance, audio performance, or enclosure fit. Perform the documented
current-limited first-article bring-up with a fresh known-good exact 357-V1
camera.

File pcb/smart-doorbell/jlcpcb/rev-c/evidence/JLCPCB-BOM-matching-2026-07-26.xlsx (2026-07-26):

JLCPCB BOM Tool - BOM Matching
BOM name：BOM-smart-doorbell-JLCPCB Assembly Order.xlsx |  |  | Download Time：2026-07-26 17:48:43 |  |  |  | * Our matching results are updated in real-time, but stock and prices may change. If it's been over 24 hours, please re-match before placing your order.
PCB Assembled Qty：5 |  |  | Est. Total Price：57.3764
Your BOM |  |  |  |  | Matched Parts |  |  |  |  |  |  | Order Information
Top Designator | Bottom Designator | Comment | Footprint | JLCPCB Part # | Matches | Part # | Manufacturer | Footprint | Description | Category | Warning | JLCPCB Part # | Product link | Lib Type | Qty | Source | Total Price ($)
BOOT1,RESET1 |  | SW_SPST | SW_SPST_B3U-1000P |  | Unconfirmed | B3U-1000P | Omron Electronics | SMD,3x2.5mm | -25℃~+70℃ 1.53N 1.6mm 12V 2.5mm 3mm 50mA Round Button SMD(SMT) Tab SPST Surface Mount,Vertical SMD,3x2.5mm Tactile Switches ROHS | Tactile Switches | 1.There may be multiple types of parts, but one type of part has been matched. Please check.; | C231329 | https://jlcpcb.com/partdetail/OmronElectronics-B3U1000P/C231329 | Extended | 12 | 12 JLCPCB | 2.1048
C1,C13,C20,C25,C26,C3,C33,C34 |  | 10u | C_0603_1608Metric |  | Select by System | CL10A106KP8NNNC | Samsung Electro-Mechanics | 0603 | 10V 10uF X5R ±10% 0603 Multilayer Ceramic Capacitors MLCC - SMD/SMT ROHS | Multilayer Ceramic Capacitors MLCC - SMD/SMT |  | C19702 | https://jlcpcb.com/partdetail/20411-CL10A106KP8NNNC/C19702 | Basic | 40 | 40 JLCPCB | 1.632
C10,C11,C19,C2,C21,C22,C23,C28,C30,C5,C8,C9 |  | 0.1u | C_0603_1608Metric |  | Select by System | CC0603KRX7R9BB104 | YAGEO | 0603 | 100nF 50V X7R ±10% 0603 Multilayer Ceramic Capacitors MLCC - SMD/SMT ROHS | Multilayer Ceramic Capacitors MLCC - SMD/SMT |  | C14663 | https://jlcpcb.com/partdetail/YAGEO-CC0603KRX7R9BB104/C14663 | Basic | 60 | 60 JLCPCB | 1.446
C14,C15,C16,C17,C18,C35 |  | 1u | C_0603_1608Metric |  | Select by System | CL10A105KB8NNNC | Samsung Electro-Mechanics | 0603 | 1uF 50V X5R ±10% 0603 Multilayer Ceramic Capacitors MLCC - SMD/SMT ROHS | Multilayer Ceramic Capacitors MLCC - SMD/SMT |  | C15849 | https://jlcpcb.com/partdetail/16531-CL10A105KB8NNNC/C15849 | Basic | 30 | 30 JLCPCB | 2.892
C24,C27,C29,C31 |  | 22u | C_0603_1608Metric |  | Select by System | GRM188R61A226ME15D | Murata Electronics | 0603 | 10V 22uF X5R ±20% 0603 Multilayer Ceramic Capacitors MLCC - SMD/SMT ROHS | Multilayer Ceramic Capacitors MLCC - SMD/SMT |  | C84419 | https://jlcpcb.com/partdetail/MurataElectronics-GRM188R61A226ME15D/C84419 | Extended | 28 | 28 JLCPCB | 3.248
C32 |  | 10u | C_0603_1608Metric |  | Select by System | GRM188R61A106ME69D | Murata Electronics | 0603 | 10V 10uF X5R ±20% 0603 Multilayer Ceramic Capacitors MLCC - SMD/SMT ROHS | Multilayer Ceramic Capacitors MLCC - SMD/SMT |  | C90053 | https://jlcpcb.com/partdetail/MurataElectronics-GRM188R61A106ME69D/C90053 | Extended | 20 | 20 JLCPCB | 1.962
D2,D3 |  | LED | LED_0603_1608Metric |  | Select by System | KT-0603W | Hubei KENTO Elec | 0603 | -40℃~+85℃ 100mW 120° 2.6V~3.1V 360mcd 5mA Discrete Diode Top-mount White Yellow Lens 0603 LED Indication - Discrete ROHS | LED Indication - Discrete |  | C2290 | https://jlcpcb.com/partdetail/Hubei_KENTOElec-KT0603W/C2290 | Basic | 10 | 10 JLCPCB | 0.121
J1,J6 |  | Conn_01x02_Pin | JST_PH_B2B-PH-K_1x02_P2.00mm_Vertical |  | Select by System | B2B-PH-K-S(LF)(SN) | JST | 插件,P=2mm | -25℃~+85℃ 1 100V 1x2P 2 2A 2P 2mm 4.5mm 5.9mm 6mm Brass K Pin PA66 PH Through Hole Tin UL94V-0 White 插件,P=2mm Wire To Board Connector ROHS | Wire To Board Connector |  | C131337 | https://jlcpcb.com/partdetail/JST-B2B_PH_K_S_LF_SN/C131337 | Extended | 11 | 11 JLCPCB | 0.385
J2 |  | USB_C_Receptacle_USB2.0_16P | USB_C_Receptacle_HRO_TYPE-C-31-M-12 |  | Select by System | TYPE-C-31-M-12 | Korean Hroparts Elec | SMD | -30℃~+80℃ 1 10,000 cycles 16P 20V 5A 7.35mm Female Surface Mount, Right Angle Type-C SMD USB Connectors ROHS | USB Connectors |  | C165948 | https://jlcpcb.com/partdetail/Korean_HropartsElec-TYPE_C_31_M12/C165948 | Extended | 5 | 5 JLCPCB | 0.9205
J3 |  | Conn_01x24 | Hirose_FH12-24S-0.5SH_1x24-1MP_P0.50mm_Horizontal |  | Select by System | FH12-24S-0.5SH(55) | HRS(Hirose) | SMD,P=0.5mm,卧贴 | -40℃~+85℃ 0.3mm 0.5mm 24P 2mm Bottom Contact Gold Hinged Lid Phosphor bronze Surface Mount, Right Angle SMD,P=0.5mm,卧贴 FFC, FPC (Flat Flexible) Connector Assemblies ROHS | FFC, FPC (Flat Flexible) Connector Assemblies |  | C202112 | https://jlcpcb.com/partdetail/HRS_Hirose-FH12_24S_0_5SH_55/C202112 | Extended | 5 | 5 JLCPCB | 3.3935
J4 |  | Conn_01x06 | PinHeader_1x06_P2.54mm_Vertical |  | Select by System | 2.54-1x6P直针 | BOOMELE(Boom Precision Elec) | 插件,P=2.54mm | -40℃~+105℃ 1 1x6P 2.54mm 2.5mm 3A 3mm 6P 6mm Black Brass Gold Pin Header Through Hole 插件,P=2.54mm Pin Headers ROHS | Pin Headers |  | C37208 | https://jlcpcb.com/partdetail/38187-2_54_1x6P/C37208 | Extended | 5 | 5 JLCPCB | 0.206
J7 |  | Conn_01x03 | JST_PH_B3B-PH-K_1x03_P2.00mm_Vertical |  | Select by System | B3B-PH-K-S(LF)(SN) | JST | 插件,P=2mm | -25℃~+85℃ 1 100V 1x3P 2A 2mm 3 3P 4.5mm 6mm 7.9mm Brass K Pin PA66 PH Through Hole Tin UL94V-0 White 插件,P=2mm Wire To Board Connector ROHS | Wire To Board Connector |  | C131339 | https://jlcpcb.com/partdetail/JST-B3B_PH_K_S_LF_SN/C131339 | Extended | 6 | 6 JLCPCB | 0.267
J8 |  | Conn_01x04 | JST_PH_B4B-PH-K_1x04_P2.00mm_Vertical |  | Select by System | B4B-PH-K-S(LF)(SN) | JST | 插件,P=2mm | -25℃~+85℃ 1 100V 1x4P 2A 2mm 4 4.5mm 4P 6mm 9.9mm Brass K Pin PA66 PH Through Hole Tin UL94V-0 White 插件,P=2mm Wire To Board Connector ROHS | Wire To Board Connector |  | C131334 | https://jlcpcb.com/partdetail/JST-B4B_PH_K_S_LF_SN/C131334 | Extended | 6 | 6 JLCPCB | 0.2748
L1 |  | 0.47u | L_1008_2520Metric |  | Select by System | MHCH252010A-R47M-Q8 | Chilisin Elec | 1008 | 27mΩ 3.9A 470nH 5A ±20% 1008 Power Inductors ROHS | Power Inductors |  | C2981231 | https://jlcpcb.com/partdetail/ChilisinElec-MHCH252010A_R47MQ8/C2981231 | Extended | 9 | 9 JLCPCB | 0.4761
R1,R17,R19,R33,R5 |  | 10k | R_0603_1608Metric |  | Select by System | 0603WAJ0103T5E | UNI-ROYAL(Uniroyal Elec) | 0603 | -55℃~+155℃ 100mW 10kΩ 75V Thick Film Resistor ±100ppm/℃ ±5% 0603 Chip Resistor - Surface Mount ROHS | Chip Resistor - Surface Mount |  | C15401 | https://jlcpcb.com/partdetail/16079-0603WAJ0103T5E/C15401 | Extended | 35 | 35 JLCPCB | 0.0875
R2 |  | 2k | R_0603_1608Metric |  | Select by System | 0603WAF2001T5E | UNI-ROYAL(Uniroyal Elec) | 0603 | -55℃~+155℃ 100mW 2kΩ 75V Thick Film Resistor ±1% ±100ppm/℃ 0603 Chip Resistor - Surface Mount ROHS | Chip Resistor - Surface Mount |  | C22975 | https://jlcpcb.com/partdetail/23702-0603WAF2001T5E/C22975 | Basic | 5 | 5 JLCPCB | 0.0585
R3,R30,R37,R39,R40 |  | 1k | R_0603_1608Metric |  | Select by System | 0603WAF1001T5E | UNI-ROYAL(Uniroyal Elec) | 0603 | -55℃~+155℃ 100mW 1kΩ 75V Thick Film Resistor ±1% ±100ppm/℃ 0603 Chip Resistor - Surface Mount ROHS | Chip Resistor - Surface Mount |  | C21190 | https://jlcpcb.com/partdetail/21904-0603WAF1001T5E/C21190 | Basic | 25 | 25 JLCPCB | 0.225
R9 |  | 330 | R_0603_1608Metric |  | Select by System | 0603WAF3300T5E | UNI-ROYAL(Uniroyal Elec) | 0603 | -55℃~+155℃ 100mW 330Ω 75V Thick Film Resistor ±1% ±100ppm/℃ 0603 Chip Resistor - Surface Mount ROHS | Chip Resistor - Surface Mount |  | C23138 | https://jlcpcb.com/partdetail/23865-0603WAF3300T5E/C23138 | Basic | 5 | 5 JLCPCB | 0.0695
R10,R6 |  | 5.1k | R_0603_1608Metric |  | Select by System | 0603WAF5101T5E | UNI-ROYAL(Uniroyal Elec) | 0603 | -55℃~+155℃ 100mW 5.1kΩ 75V Thick Film Resistor ±1% ±100ppm/℃ 0603 Chip Resistor - Surface Mount ROHS | Chip Resistor - Surface Mount |  | C23186 | https://jlcpcb.com/partdetail/23913-0603WAF5101T5E/C23186 | Basic | 10 | 10 JLCPCB | 0.084
R12,R13,R14 |  | 4.7k | R_0603_1608Metric |  | Select by System | 0603WAF4701T5E | UNI-ROYAL(Uniroyal Elec) | 0603 | -55℃~+155℃ 100mW 4.7kΩ 75V Thick Film Resistor ±1% ±100ppm/℃ 0603 Chip Resistor - Surface Mount ROHS | Chip Resistor - Surface Mount |  | C23162 | https://jlcpcb.com/partdetail/23889-0603WAF4701T5E/C23162 | Basic | 15 | 15 JLCPCB | 0.1755
R15 |  | 680 | R_0603_1608Metric |  | Select by System | 0603WAF6800T5E | UNI-ROYAL(Uniroyal Elec) | 0603 | -55℃~+155℃ 100mW 680Ω 75V Thick Film Resistor ±1% ±100ppm/℃ 0603 Chip Resistor - Surface Mount ROHS | Chip Resistor - Surface Mount |  | C23228 | https://jlcpcb.com/partdetail/23955-0603WAF6800T5E/C23228 | Basic | 5 | 5 JLCPCB | 0.0125
R16 |  | 3.9k | R_0603_1608Metric |  | Select by System | 0603WAF3901T5E | UNI-ROYAL(Uniroyal Elec) | 0603 | -55℃~+155℃ 100mW 3.9kΩ 75V Thick Film Resistor ±1% ±100ppm/℃ 0603 Chip Resistor - Surface Mount ROHS | Chip Resistor - Surface Mount |  | C23018 | https://jlcpcb.com/partdetail/23745-0603WAF3901T5E/C23018 | Basic | 5 | 5 JLCPCB | 0.043
R18,R20 |  | 56k | R_0603_1608Metric |  | Select by System | 0603WAF5602T5E | UNI-ROYAL(Uniroyal Elec) | 0603 | -55℃~+155℃ 100mW 56kΩ 75V Thick Film Resistor ±1% ±100ppm/℃ 0603 Chip Resistor - Surface Mount ROHS | Chip Resistor - Surface Mount |  | C23206 | https://jlcpcb.com/partdetail/23933-0603WAF5602T5E/C23206 | Basic | 10 | 10 JLCPCB | 0.081
R22 |  | 511k | R_0603_1608Metric |  | Select by System | 0603WAF5113T5E | UNI-ROYAL(Uniroyal Elec) | 0603 | -55℃~+155℃ 100mW 511kΩ 75V Thick Film Resistor ±1% ±100ppm/℃ 0603 Chip Resistor - Surface Mount ROHS | Chip Resistor - Surface Mount |  | C23194 | https://jlcpcb.com/partdetail/23921-0603WAF5113T5E/C23194 | Extended | 20 | 20 JLCPCB | 0.05
R23 |  | 91k | R_0603_1608Metric |  | Select by System | 0603WAF9102T5E | UNI-ROYAL(Uniroyal Elec) | 0603 | -55℃~+155℃ 100mW 75V 91kΩ Thick Film Resistor ±1% ±100ppm/℃ 0603 Chip Resistor - Surface Mount ROHS | Chip Resistor - Surface Mount |  | C23265 | https://jlcpcb.com/partdetail/23992-0603WAF9102T5E/C23265 | Extended | 20 | 20 JLCPCB | 0.058
R24,R29,R38,R4,R7,R8 |  | 100k | R_0603_1608Metric |  | Select by System | 0603WAF1003T5E | UNI-ROYAL(Uniroyal Elec) | 0603 | -55℃~+155℃ 100kΩ 100mW 75V Thick Film Resistor ±1% ±100ppm/℃ 0603 Chip Resistor - Surface Mount ROHS | Chip Resistor - Surface Mount |  | C25803 | https://jlcpcb.com/partdetail/26546-0603WAF1003T5E/C25803 | Basic | 30 | 30 JLCPCB | 0.237
R25 |  | 25k | R_0603_1608Metric |  | Select by System | AR03BTCX2502 | Viking Tech | 0603 | -55℃~+155℃ 100mW 25kΩ 75V Thin Film Resistor ±0.1% ±25ppm/℃ 0603 Chip Resistor - Surface Mount ROHS | Chip Resistor - Surface Mount |  | C2828637 | https://jlcpcb.com/partdetail/VikingTech-AR03BTCX2502/C2828637 | Extended | 20 | 20 JLCPCB | 0.682
R27 |  | 330k | R_0603_1608Metric |  | Select by System | 0603WAF3303T5E | UNI-ROYAL(Uniroyal Elec) | 0603 | -55℃~+155℃ 100mW 330kΩ 75V Thick Film Resistor ±1% ±100ppm/℃ 0603 Chip Resistor - Surface Mount ROHS | Chip Resistor - Surface Mount |  | C23137 | https://jlcpcb.com/partdetail/23864-0603WAF3303T5E/C23137 | Basic | 5 | 5 JLCPCB | 0.0125
R28 |  | 110k | R_0603_1608Metric |  | Select by System | 0603WAF1103T5E | UNI-ROYAL(Uniroyal Elec) | 0603 | -55℃~+155℃ 100mW 110kΩ 75V Thick Film Resistor ±1% ±100ppm/℃ 0603 Chip Resistor - Surface Mount ROHS | Chip Resistor - Surface Mount |  | C25805 | https://jlcpcb.com/partdetail/26548-0603WAF1103T5E/C25805 | Extended | 20 | 20 JLCPCB | 0.142
R32 |  | 0 | R_0603_1608Metric |  | Select by System | 0603WAF0000T5E | UNI-ROYAL(Uniroyal Elec) | 0603 | -55℃~+155℃ 0Ω 100mW 75V Thick Film Resistor ±1% 0603 Chip Resistor - Surface Mount ROHS | Chip Resistor - Surface Mount |  | C21189 | https://jlcpcb.com/partdetail/21903-0603WAF0000T5E/C21189 | Basic | 5 | 5 JLCPCB | 0.0125
R34,R35 |  | 22 | R_0603_1608Metric |  | Select by System | 0603WAF220JT5E | UNI-ROYAL(Uniroyal Elec) | 0603 | -55℃~+155℃ 100mW 22Ω 75V Thick Film Resistor ±1% ±100ppm/℃ 0603 Chip Resistor - Surface Mount ROHS | Chip Resistor - Surface Mount |  | C23345 | https://jlcpcb.com/partdetail/24078-0603WAF220JT5E/C23345 | Basic | 10 | 10 JLCPCB | 0.026
U2 |  | MCP73871T-2AAI/ML | QFN-20-1EP_4x4mm_P0.5mm_EP2.5x2.5mm |  | Select by System | MCP73871-2AAI/ML | Microchip Tech | QFN-20-EP(4x4) | -40℃~+85℃ 1 1.1A 28uA 4.2V 6V Charging IC Support QFN-20-EP(4x4) Battery Management ROHS | Battery Management |  | C144351 | https://jlcpcb.com/partdetail/MicrochipTech-MCP73871_2AAIML/C144351 | Extended | 5 | 5 JLCPCB | 22.504
U4 |  | MAX98357A | MAX98357A_TQFN-16-1EP_3x3mm_P0.5mm_EP1.23x1.23mm |  | Select by System | MAX98357AETE+T | Analog Devices Inc./Maxim Integrated | TQFN-16-EP(3x3) | -40℃~+85℃ 2.4mA 2.5V~5.5V 3.2Wx1@4Ω 77dB 92% Automatic mute/no-noise switch、Enable/disable function、Filterless architecture、Configurable output topology Class D TQFN-16-EP(3x3) Audio Amplifiers ROHS | Audio Amplifiers |  | C910544 | https://jlcpcb.com/partdetail/978950-MAX98357AETET/C910544 | Extended | 5 | 5 JLCPCB | 6.6335
U5 |  | SRV05-4 | SOT-23-6 |  | Select by System | SRV05-4 | hongjiacheng | SOT-23-6L | -55℃~+150℃ 15V 1pF 4A 5V 5uA 6V 80W ESD Four channels IEC 61000-4-2、IEC 61000-4-5 Unidirectional SOT-23-6L ESD and Surge Protection (TVS/ESD) ROHS | ESD And Surge Protection (TVS/ESD) |  | C7420376 | https://jlcpcb.com/partdetail/hongjiacheng-SRV054/C7420376 | Extended | 9 | 9 JLCPCB | 0.7551
U6 |  | DS8561-15S3 | SOT-23-3 |  | Select by System | DS8561-15S3 | DSTECH | SOT23-3 | -40℃~+125℃@(Tj) 1 1.5V 2uA 300mA 5.5V 60mV@(100mA) 75dB@(1kHz) Fixed Over Current Protection、Over Temperature Protection Positive SOT23-3 Voltage Regulators - Linear, Low Drop Out (LDO) Regulators ROHS | Voltage Regulators - Linear, Low Drop Out (LDO) Regulators |  | C5795628 | https://jlcpcb.com/partdetail/DSTECH-DS856115S3/C5795628 | Extended | 9 | 9 JLCPCB | 0.3996
U7 |  | XC6206P282MR | SOT-23-3 |  | Select by System | XC6206P282MR | UMW(Youtai Semiconductor Co., Ltd.) | SOT-23 | -25℃~+80℃ 1 2.8V 240mV@(50mA) 250mA 40dB@(1kHz) 7uA 8V Fixed Over Current Protection、Short Circuit Protection Positive SOT-23 Voltage Regulators - Linear, Low Drop Out (LDO) Regulators ROHS | Voltage Regulators - Linear, Low Drop Out (LDO) Regulators |  | C347374 | https://jlcpcb.com/partdetail/324034-XC6206P282MR/C347374 | Extended | 10 | 10 JLCPCB | 0.196
U8 |  | TPS63802DLAR | TPS63802DLAR_DLA0010A |  | Select by System | TPS63802DLAR | Texas Instruments | VSON-10(2x3) | -40℃~+125℃@(TJ) 1 1.3V~5.5V 1.4MHz、1.6MHz、2.1MHz 1.8V~5.2V 11uA 2A Adjustable Buck-Boost Buck-Boost Built-in Yes VSON-10(2x3) DC-DC Converters ROHS | DC-DC Converters |  | C2845237 | https://jlcpcb.com/partdetail/TexasInstruments-TPS63802DLAR/C2845237 | Extended | 5 | 5 JLCPCB | 4.82
U9 |  | TPS22919DCK | SOT-363_SC-70-6 |  | Select by System | TPS22919DCKR | Texas Instruments | SC-70-6 | -40℃~+125℃ 1 1.5A 1.6V~5.5V 89mΩ Active High Load Switch Output discharge function、Soft-start、Overcurrent Protection、Over temperature protection、Short-Circuit Protection SC-70-6 Power Distribution Switches ROHS | Power Distribution Switches |  | C2149796 | https://jlcpcb.com/partdetail/TexasInstruments-TPS22919DCKR/C2149796 | Extended | 5 | 5 JLCPCB | 0.683

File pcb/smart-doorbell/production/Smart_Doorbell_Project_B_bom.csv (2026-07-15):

Designator | Footprint | Quantity | Value | LCSC Part #
BOOT1, RESET1 | SW_SPST_B3U-1000P | 2 | SW_SPST | C231329
C1, C13, C20, C25, C26, C3, C33, C34 | 0603 | 8 | 10u | C19702
C10, C11, C19, C2, C21, C22, C23, C28, C30, C5, C8, C9 | 0603 | 12 | 0.1u
C14, C15, C16, C17, C18 | 0603 | 5 | 1u
C24, C27, C29, C31 | 0603 | 4 | 22u | C84419
C32 | 0603 | 1 | 10u | C90053
D2, D3 | 0603 | 2 | LED
J1, J6 | JST_PH_B2B-PH-K_1x02_P2.00mm_Vertical | 2 | Conn_01x02_Pin | C131337
J2 | USB_C_Receptacle_HRO_TYPE-C-31-M-12 | 1 | USB_C_Receptacle_USB2.0_16P | C165948
J3 | Hirose_FH12-24S-0.5SH_1x24-1MP_P0.50mm_Horizontal | 1 | Conn_01x24 | C202112
J4 | PinHeader_1x06_P2.54mm_Vertical | 1 | Conn_01x06 | C37208
J7 | JST_PH_B3B-PH-K_1x03_P2.00mm_Vertical | 1 | Conn_01x03 | C131339
J8 | JST_PH_B4B-PH-K_1x04_P2.00mm_Vertical | 1 | Conn_01x04 | C131334
L1 | 1008 | 1 | 0.47u | C2981231
R1, R17, R19, R26, R33, R5 | 0603 | 6 | 10k | C15401
R10, R6 | 0603 | 2 | 5.1k
R12, R13, R14 | 0603 | 3 | 4.7k
R15 | 0603 | 1 | 680
R16 | 0603 | 1 | 3.9k
R18, R20 | 0603 | 2 | 56k
R2 | 0603 | 1 | 2k
R22 | 0603 | 1 | 511k
R23 | 0603 | 1 | 91k | C23265
R24, R29, R38, R4, R7, R8 | 0603 | 6 | 100k | C25803
R25 | 0603 | 1 | 25k
R27 | 0603 | 1 | 330k
R28 | 0603 | 1 | 110k
R3, R30 | 0603 | 2 | 1k | C21190
R32, R36 | 0603 | 2 | 0 | C21189
R34, R35 | 0603 | 2 | 22 | C23345
R39, R40 | 0603 | 2 | 1k | C21190
R9 | 0603 | 1 | 330
U2 | QFN-20-1EP_4x4mm_P0.5mm_EP2.5x2.5mm | 1 | MCP73871T-2AAI/ML | C144351
U4 | MAX98357A_TQFN-16-1EP_3x3mm_P0.5mm_EP1.23x1.23mm | 1 | MAX98357A
U5 | SOT-23-6 | 1 | SRV05-4
U6 | SOT-23-3 | 1 | DS8561-15S3 | C5795628
U7 | SOT-23-3 | 1 | XC6206P282MR
U8 | TPS63802DLAR_DLA0010A | 1 | TPS63802DLAR | C2845237

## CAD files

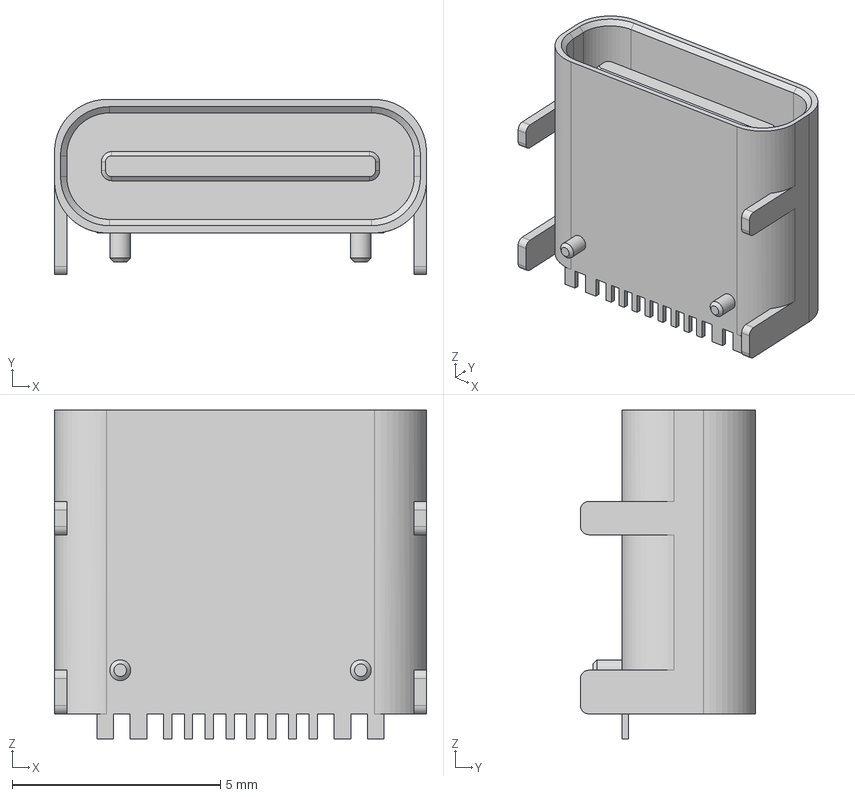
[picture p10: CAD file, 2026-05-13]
pcb/smart-doorbell/3D-Models/HRO TYPE-C-31-M-12.step
8.94 x 4.21 x 7.90 mm

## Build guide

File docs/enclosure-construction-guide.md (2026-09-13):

# Doorlink Indoor Enclosure Construction Guide

This is the build-facing guide for fitting the assembled Rev C doorbell into
the black `DS-AG-0813`-style `80 x 130 x 70 mm` ABS enclosure. The finished
unit will be mounted to an apartment door in a well-lit, ventilated indoor
corridor. It is not intended for rain, direct weather, or outdoor service.

Read the [Rev B enclosure handoff](enclosure-rev-b-handoff.md) for the PCB,
battery, camera, button, microphone, and internal-volume decisions behind this
construction plan. Treat the measured parts and the physical Rev C PCB as the
machining source of truth. Marketplace dimensions are planning dimensions,
not final cut dimensions.

The enclosure loses any original ingress rating after it is machined. That is
acceptable for this indoor installation; weatherproof acoustic membranes,
rain testing, and outdoor drainage features are not required. Dust control,
strain relief, electrical insulation, acoustic separation, and safe LiPo
retention still matter. The corridor being ventilated does not require extra
vent holes in the enclosure.

## Confirmed Mechanical Inputs

| Item | Construction dimension or intent |
| --- | --- |
| Enclosure | Black solid-cover `80 x 130 x 70 mm` ABS, `DS-AG-0813` style |
| Hallway-facing front face | Approximately `77 x 125 mm`, with four existing corner closure holes |
| PCB | Rev C, approximately `59 x 91 mm`, mounted in the deep base |
| PCB hole pattern | Four `2.7 mm` M2.5 mounting holes on a `51.4 x 51.4 mm` pattern |
| PCB supports | Four `10 mm` M2.5 female-to-female standoffs, preferably no more than `5 mm` OD |
| Battery | `103450` LiPo, approximately `50 x 34 x 10 mm`, retained on the right interior wall |
| Camera | Fixed-focus 120-degree OV5640; circular lens base is approximately `7 mm` diameter, while the square camera head is approximately `8.5 mm` wide |
| Button | Selected `22 mm` version: M22 x 1 threaded barrel, approximately `25 mm` face diameter, `15 mm` threaded length, and `33 mm` overall depth |
| Speaker | One `4 ohm`, `3 W` oval speaker, approximately `25 x 32 mm`; received connector has been verified as `2.0`; front-lid mounted below the button and rotated landscape |
| Speaker grille | Cut from one supplied `100 mm` circular metal mesh sheet using aviation snips |
| PIR | AM312-style module; dome is approximately `13 mm` at its widest and tapers toward approximately `8 mm` |
| Light pipes | `3 mm` clear acrylic rods with `3 mm` black plastic panel lamp bases |
| Microphone duct | `2 mm` ID x `4 mm` OD silicone tube from its own `1.0-1.5 mm` exterior port to PCB microphone `MK1` |

Measure the received enclosure wall thickness, corner-hole centers, internal
ribs, screw columns, and every actual component with calipers before marking.
Retain a spare enclosure or make every new opening first in comparable scrap
ABS.

## Parts And Fasteners

Have the complete mechanical set on hand before cutting:

- four `10 mm` M2.5 female-to-female standoffs, OD preferably `<=5 mm`;
- four M2.5 pan-head machine screws; start with M2.5 x 6 mm and keep M2.5 x 4
  or 5 mm alternatives in case the measured standoff thread is shallow;
- four M2.5 nylon washers under the PCB screw heads;
- plastic-compatible structural epoxy or plastic bonder for attaching the
  standoff bases to the enclosure;
- the 22 mm button with its supplied panel gasket, nut, and terminal wiring;
- two `3 mm` clear acrylic light-pipe rods and two black `3 mm` plastic lamp
  bases, one for each intended indicator;
- adhesive-backed hook-and-loop or similar removable adhesive fastener for
  the battery, plus fishpaper/Kapton or a thin battery carrier;
- closed-cell foam/EVA for the speaker perimeter gasket;
- the cut metal speaker mesh, with all cut strands and sharp edges contained;
- neutral-cure electronics-safe silicone for flexible retention, acoustic
  sealing, and strain relief;
- a fine-tip hot-glue gun and hot-melt glue sticks for sealing and retaining
  the microphone tube at the PCB; and
- heat-shrink tubing, cable ties or tie mounts, and the verified JST-PH
  pigtails needed for internal wiring.

Aim for approximately `3-5 mm` of screw engagement in each standoff. A screw
must not bottom out before clamping the washer and PCB, and it must not protrude
through a bonded standoff into the enclosure wall. Do not substitute enclosure
closure screws for PCB screws.

Do not use silicone as the primary structural adhesive for the standoffs. It
is intentionally flexible. Use a structural bonder verified for both the ABS
case and the standoff material; many adhesives do not bond reliably to nylon.
Use neutral-cure silicone for parts that benefit from compliance. Avoid
vinegar-smelling acetic-cure silicone around electronics.

## Panel Layout

Use the `77 x 125 mm` front face in portrait orientation. Preserve generous
no-cut areas around all four existing corner holes, their internal screw
columns, the lid lip, and any gasket. Measure those keepouts rather than
assuming the four holes form a perfect rectangle.

Use this mechanical priority order; appearance does not override it:

1. Position the PCB so the USB-C receptacle is square to the underside opening
   and approximately flush with, or slightly recessed behind, the exterior
   enclosure surface.
2. Confirm PCB wall, boss, button, battery, and cable clearances, then bond the
   four standoffs so that PCB position cannot change.
3. Project the centers of PCB LEDs D3 and D2 perpendicular to the front panel.
   These two points are the fixed axes of the rigid light pipes.
4. Arrange the camera, optional PIR, button, and front speaker around those
   fixed axes and the four enclosure closure-column keepouts.

The resulting visual order should be:

1. Camera centered high on the lid, but no higher than its 70 mm flex can reach
   without a tight bend.
2. Optional PIR dome fitted below the camera as a future contingency.
3. D3 lamp base at its mechanically projected position.
4. Illuminated 22 mm button raised into the middle/lower-middle region and
   adjusted around D3 if necessary.
5. Front-facing speaker immediately below the button, rotated to put its
   approximately `32 mm` dimension left-to-right and `25 mm` dimension
   top-to-bottom.
6. D2 lamp base at its mechanically projected position near the bottom.

The speaker is now deliberately front-facing and below the button. The
microphone remains separate: it uses a `1.0-1.5 mm` pinhole on the left side
wall, in the deep-base/rear portion and at the same height as PCB microphone
MK1. Its silicone duct runs through the 10 mm under-PCB space.

Make full-size front templates of the speaker's complete `32 x 25 mm`
landscape envelope, terminal projection, grille patch, and actual diaphragm
opening. The outer speaker envelope is a clearance template, not the ABS cut
line.

## Microphone And Front-Speaker Placement Map

Use these orientation names throughout the build:

- **rear**: the deep-base wall mounted against the apartment door;
- **front**: the removable `77 x 125 mm` hallway-facing lid;
- **left/right**: as viewed by a visitor facing the installed doorbell; and
- **underside**: the short downward-facing wall containing USB-C only.

```text
LEFT-SIDE SECTION — vertical centerline through the enclosure

door / rear                                             hallway / front
     |                                                        |
     v                                                        v
     +--------------------------------------------------------+
     | rear wall                                              | front lid
     |    10 mm standoffs                                     |
     |       PCB                                               |
     |       |                                                 |
     |       | MK1                                             |
     |       o<==== short 2 mm-ID silicone mic duct            |
     |  side mic port                                   [SPK]  | front lid
     |  1.0-1.5 mm                                      faces  | opening
     +------ USB-C opening ------------------------------front--+
                         UNDERSIDE
```

```text
FRONT ENVELOPE — conceptual order only

     +----------------------------------+
     |             camera               |
     |               PIR                |
     |                         D3       |
     |           22 mm button            |
     |        +----------------+          |
     |        | front speaker  |          |
     |        | 32 mm x 25 mm  |          |
     |        +----------------+    D2    |
     +----------------------------------+
```

The diagrams are conceptual, not drilling templates. The USB-C position still
fixes the PCB first, and the PCB fixes D3/D2. The camera, PIR, wired button, and
lid-mounted speaker must fit around those axes. Keep the speaker landscape and
below the button. Move it a few millimetres left or right only as needed to
clear D2, a closure column, or its own terminal projection; do not move the
USB-aligned PCB.

Because the speaker is attached to the removable lid, provide a flexible
two-wire service loop from J6 and strain relief at the lid. The loop must let
the lid open far enough to unplug J6 without pulling the camera flex, mic duct,
or speaker terminals. The speaker body, mesh, gasket, and terminals must all
clear the button barrel and both rigid light pipes when the lid closes.

## Tentative Recommended Front-Face Layout

Use the following layout as the first full-size paper template. Camera, PIR,
and button coordinates are tentative. The displayed D3 and D2 coordinates are
only predictions of where the fixed PCB geometry will place them. Coordinates
are hole centers measured on the hallway-facing `77 x 125 mm` face, viewed
from the front:

- origin `(0, 0)`: top-left edge;
- `X`: increases toward the right edge;
- `Y`: increases toward the bottom edge; and
- enclosure centerline: `X = 38.5 mm`.

| Feature | Initial center estimate `(X, Y)` | Opening/visible size | Status |
| --- | --- | --- | --- |
| Camera lens | Approximately `(38.5, 30 mm)` | Start undersize; finish just over the measured approximately `7 mm` circular base | Tentative raised position; verify the 70 mm camera flex reaches before drilling |
| PIR dome | Approximately `(38.5, 45 mm)` | Start near `8 mm`; hand-fit to the taper beneath the approximately `13 mm` dome | Tentative; it uses a flexible pigtail and can move around fixed items |
| Status light pipe, D3 | Predicted near `(51.5, 65 mm)` | Hole determined by the actual black `3 mm` lamp base | Fixed by the final PCB/USB position; transfer the physical LED center before drilling |
| Main button | Planning position near `(33, 69 mm)` if the predicted D3 axis is correct | Approximately `22 mm` barrel hole and `25 mm` visible bezel | Raised and slightly left only to clear predicted D3; recenter it if the physical D3 transfer permits |
| Front speaker | Planning position near `(38.5, 98.5 mm)` | Landscape outer envelope approximately `32 x 25 mm`; acoustic cutout is smaller | Below the button; shift slightly only if required by physical D2, closure columns, or terminal clearance |
| Charge/status light pipe, D2 | Predicted near `(51.5, 118.5 mm)` | Hole determined by the actual black `3 mm` lamp base | Fixed by the final PCB/USB position; check the lower lip and screw column before committing |

The LED estimates come from the current KiCad positions and assume the
approximately `59 x 91 mm` PCB is centered laterally behind the `77 mm` face
and its bottom edge is aligned with the bottom for USB-C access. Under that
assumption, D3 projects to approximately `(51.7, 65.3 mm)` and D2 to
approximately `(51.7, 118.7 mm)`. These are predictions, not drilling
coordinates. The physical projection made after the USB and standoffs are
final is authoritative.

```text
                 TOP — 77 mm
        0                                  77
     0  +----------------------------------+
        |  O                            O  |  existing closure holes;
        |                                  |  measure their true centers
        |                C                 |  camera (~38.5, 30)
        |                                  |
        |                P                 |  PIR (~38.5, 45)
        |                      S           |  D3 status pipe (~51.5, 65)
        |             B                    |  22 mm button (~33, 69)
        |          +-------------+         |
        |          |   speaker   |         |  landscape (~38.5, 98.5)
        |          +-------------+         |
        |                      L           |  D2 lower pipe (~51.5, 118.5)
   125  |  O                            O  |
        +----------------------------------+
                 BOTTOM / UNDERSIDE

        C camera     P PIR       S status light
        B button     L charge/status light
```

The sketch is positional, not to scale, and the `O` marks do not assert corner
hole coordinates. Draw the actual hole and internal screw-column keepouts on
the template first. Maintain at least `5 mm` of intact front-face plastic
between finished openings where possible, in addition to the measured column
and lip keepouts.

The lower D2 light-pipe prediction is the main risk in this layout because it
is only about `6.5 mm` above the nominal bottom edge and now sits near the
front-speaker envelope. Do not move the correctly aligned PCB or angle the
rigid rod. First establish the true D2 axis, then verify clearance from the
speaker frame, grille, lamp-base flange, internal lip, and lower-right screw
column. If they conflict, adjust the movable speaker/button arrangement or the
lamp-base/front-panel mechanical method; USB alignment remains the controlling
datum.

Before drilling, tape the paper template to the enclosure, install the button,
camera, PIR, and their wire/flex mock-ups behind it, and hold the closed unit at
its intended door height. Confirm that the camera flex reaches without a sharp
bend, the button is comfortable to press, the PIR can see the corridor, and no
feature overlaps a closure column.

## Optional PIR Future Contingency

It is reasonable to mount the PIR now as a future contingency. The enclosure
is indoors, and the visible unused dome is acceptable for this build. Fitting
it during the initial machining also avoids disassembling a finished enclosure
and generating cutting debris near installed electronics later.

Mount the PIR mechanically to the front panel with a short pigtail rather than
rigidly plugging its three pins into PCB connector J7. Start with an
approximately `8 mm` opening and enlarge it gradually with a hand reamer or
round file to match the point where the panel meets the taper. Do not advance
the large step drill automatically to `10`, `12`, or `14 mm`, and do not jump
directly to the approximately `13 mm` maximum dome diameter. The final opening
depends on the received sensor, panel thickness, and retaining position.

Keep the entire approximately `13 mm` dome unobstructed from the corridor
side. Retain the sensor by its PCB or a small bracket, not by squeezing the
Fresnel dome. Small neutral-cure silicone dabs at the module PCB edges are
acceptable as secondary retention; keep adhesive off the dome and component
side.

Until PIR firmware is intentionally enabled, leave its J7 pigtail disconnected,
labeled, insulated, and secured inside the enclosure. This avoids needless
sensor power draw or an accidental firmware interaction. When it is enabled,
verify the actual pigtail order against both devices rather than relying on
wire colors:

- J7.1: `+3V3`
- J7.2: `PIR_SENSOR_OUT`
- J7.3: `GND`

## Camera Opening

The approximately `7 mm` measurement is the widest circular lens base, not the
width of the complete camera module. The approximately `8.5 mm` square camera
head and ribbon stay behind the front panel. Do not try to pass the complete
module through a 7 mm hole.

Drill below final size and ream/file the circular opening until the lens base
has non-binding clearance. A likely finished opening is only slightly larger
than the measured 7 mm part, but determine it from the received module rather
than adopting a nominal drill size. Keep the lens as close to the inner panel
surface as safely possible. With the camera live, inspect all four image
corners and gradually bevel the opening outward only if the panel causes
vignetting.

Use a removable bracket or compliant retainers for the camera head and provide
strain relief for the flex. Do not put silicone or other adhesive on the lens,
in its field of view, or on the FPC contacts. Check the live image in the
actual well-lit corridor and also under dimmer conditions. In particular,
check whether either light pipe or the button ring reflects into the lens.

## Button Opening

The selected part is the `22 mm` version shown in the size family, not the 16
or 19 mm version. Its M22 x 1 barrel calls for an approximately `22 mm` panel
opening; its front bezel is approximately `25 mm` and covers the cut edge.
Confirm these dimensions on the received button.

On the taped layout, it is useful to trace the complete approximately `25 mm`
bezel so its clearance from D3, the speaker, and the camera can be checked.
That traced circle is a **clearance envelope**, not the cut line. Mark its
center clearly, drill from that center, and stop at the measured approximately
`22 mm` barrel diameter.

Use a pilot and step drill, stopping before the next step enters the panel.
The button should pass through without being forced or rocking excessively.
Deburr by hand, keep the supplied face gasket, and tighten the retaining nut
only enough to prevent rotation. Excess torque can bow or crack the ABS.

The approximate `33 mm` overall depth and rear terminals require a cylindrical
keepout behind the front panel. Fit heat shrink to every soldered terminal and
confirm that the lid can close without a terminal touching the PCB, battery,
speaker, wire, or enclosure screw.

## Light Pipes And Black Lamp Bases

Use the two black `3 mm` plastic lamp bases as the finished front-panel bezels
for the clear acrylic rods. The advertised `3 mm` dimension describes the
light-pipe/LED size; it may not be the enclosure hole diameter. Measure the
barrel and retaining tabs of an actual base, then drill a scrap-ABS test hole
and confirm that it clips securely through the measured panel thickness.

The purchased `3 mm x 100 mm` rods are intentionally oversized. Cut each one
only after its lamp base, the PCB standoffs, and the final PCB position have
been established. Do not calculate the length from the enclosure's advertised
depth.

### Transfer The Required Length

Use the uncut rod itself as a depth gauge:

1. Disconnect USB and the battery. Install the PCB on its final standoffs and
   install the appropriate black lamp base in the front panel.
2. Choose one factory-finished end as the temporary measuring tip. After the
   rod is cut, this end will be flipped around and used as the visible exterior
   end.
3. Temporarily close the enclosure. Insert that measuring tip slowly through
   the lamp base from outside until it only just touches the center of the PCB
   LED. Use no pressure; a 0603 LED is not a mechanical stop.
4. Mark the rod exactly at the intended exterior finished plane, normally
   flush with or slightly proud of the black lamp base. A narrow ring of
   painter's tape makes the mark easier to see.
5. Withdraw the rod and measure the marked contact length. Make a final-length
   mark `0.25-0.5 mm` shorter, toward the end that touched the LED. This is the
   required no-preload clearance.
6. Make the first cut approximately `0.5 mm` beyond the final-length mark on
   its discard side so the retained section remains slightly long. Sawing and
   sanding remove the final excess.

Repeat this transfer separately for D3 and D2. Their rods may not be the same
length because the enclosure, PCB, lamp bases, and adhesive stack have
tolerances. If the uncut rod cannot reach an LED squarely through a proposed
lamp-base position, recheck the projected hole center and panel transfer instead
of forcing the rod to bend or moving the USB-aligned PCB.

### Cut And Finish The Acrylic Rod

The preferred cutter is a fine-tooth razor saw or jeweler's saw:

1. Wrap the cut area with painter's tape and draw a square line around the rod.
   Do not deeply score the acrylic with a knife; a score can start a crack.
2. Support the rod close to the cut in a small miter block, a `3 mm` drilled
   wood guide, or between padded wood jaws. Clamp it only tightly enough to
   prevent rolling. Do not clamp bare acrylic directly in a steel vise.
3. Saw with light, short strokes and keep the blade perpendicular. Let the
   teeth cut; twisting or pushing hard can chip the end.
4. Place `400` grit abrasive on a known-flat block and sand the cut end with
   small figure-eight motions while holding the rod square. Progress through
   approximately `800` and `1200` grit; `2000` grit or plastic polish is
   optional if more optical clarity is needed.
5. Remove only a small amount at a time, clean away abrasive dust, and measure
   the total length with calipers after each grit.

If a fine saw is unavailable, a present and undamaged Dremel 426 reinforced
cutoff wheel on the correct mandrel is an acceptable fallback. Secure the rod,
wear eye protection, use the lowest practical speed, and make several light
passes around the circumference instead of forcing the wheel straight through.
Stop if the acrylic softens, smears, or discolors. Leave extra length for the
same hand-sanding process. Prefer the reinforced 426 over the small brittle 420
discs for this job.

Never cut a light pipe with aviation snips, diagonal/side cutters, pliers, or a
large drill bit. Those tools can crush, craze, or launch the acrylic. Do not
flame-polish the end.

### Final Fit

Install the finished rod with the untouched factory end facing the corridor
and the hand-polished end facing the PCB LED. Close and tighten the enclosure
normally, then verify:

- approximately `0.25-0.5 mm` remains between the rod and LED;
- the rod does not bow the PCB, hold the lid open, or rattle;
- the visible end is flush or only slightly proud of the black lamp base;
- the intended LED is bright and centered with acceptable viewing angle; and
- light from D2 and D3 does not leak into the camera or the other light pipe.

If the pipe is too long, remove it and shorten only the LED-facing end on the
flat abrasive block. If it is too short, replace it from the remaining rod
stock rather than filling the optical gap with structural adhesive. Add a
short black sleeve around the interior portion if needed to reduce light bleed.
Retain the rod, if the lamp base does not hold it sufficiently, with a tiny dab
of neutral-cure silicone on its side near the base. Keep adhesive away from
both optical end faces.

Do not assume the purchased `21.1 mm` LPA3.5 part is the correct finished
length; the actual enclosure and standoff stack determine it.

## Microphone Side Port And Duct

MK1 is near the PCB's upper-left edge and is a bottom-port microphone. Its
acoustic inlet is the small PCB hole directly beneath the package, opening into
the space between the PCB and the enclosure's rear wall. A front-panel hole
aimed at the top of MK1 would not couple correctly.

Place the exterior microphone pinhole on the **left side wall**, not on the
front face or underside. It must remain in the deep-base portion so it stays
with the PCB when the lid is removed. Use these initial transfer estimates only
for planning:

- vertical center: approximately `67.5 mm` down from the top, based on the
  current bottom-aligned PCB estimate;
- depth: approximately level with the under-PCB duct; calculate its exact
  center from the actual PCB clearance and tube diameter as described below;
  and
- port diameter: start at `1.0 mm` and enlarge no further than approximately
  `1.5 mm` after an audio test.

The final port is determined from the bonded PCB position, just like the light
pipes. After the standoff adhesive has fully cured, install the PCB and transfer
the longitudinal position of MK1's actual PCB acoustic hole to the left wall
using common top and rear datum edges. Align to the small acoustic hole through
the PCB, not merely to the `MK1` package outline or silkscreen. The side port
may move slightly along the wall to avoid a rib, but do not place it higher on
the enclosure for appearance: every unnecessary offset lengthens or bends the
duct.

Account for the tube's outside radius when setting the port depth. Let `H` be
the measured distance from the **inside rear floor** of the enclosure to the
underside of the installed PCB. For the `4 mm` OD tube laid horizontally under
the PCB, use:

```text
tube and side-port center above inside rear floor = H - 2 mm
```

If `H` is actually `10 mm`, the nominal tube/port center is therefore about
`8 mm` above the inside rear floor, not `10 mm`. When laying out that point on
the outside wall from the exterior rear surface, add the measured rear-wall
thickness. Confirm the result with a short physical piece of tube: its top
should meet the PCB underside at MK1 without lifting the PCB, flattening the
tube, or requiring a sharp bend.

Use the existing `2 mm` ID x `4 mm` OD silicone tube as a side-tapped duct:

```text
left exterior
  -> 1.0-1.5 mm side-wall pinhole
  -> enclosure-side end of silicone tube remains open and is seated behind that pinhole
  -> short tube run rightward in the under-PCB space
  -> approximately 1 mm side window cut in the tube and aligned upward to MK1's PCB hole
  -> a short section of tube continues just past the window
  -> PCB-side end of the tube is completely sealed with hot glue
```

At the PCB end, first seal the open end of the tube completely with hot glue.
Cut an approximately `1 mm` window in the **side wall of the tube**, slightly
back from that sealed end; do not use the end opening as the microphone pickup.
Turn this side window upward and align it to the actual acoustic hole through
the PCB, not merely to the printed `MK1` outline. Enlarge the window only if
recorded speech is too attenuated.

Fix the tube to the rear-facing underside of the PCB with hot glue, not tape.
Apply a small bead around the tube-to-PCB interface so the upward-facing side
window is acoustically sealed to the PCB hole, then use only the minimum extra
hot-glue dabs needed to stop the tube moving. Keep molten glue out of the tube
bore and MK1 acoustic hole, do not cover pads or test points, and do not use so
much glue that it bows the PCB or makes the board impractical to remove. Let the
glue cool before installing the PCB. The opposite, enclosure-side end of the
tube remains open: seat it directly behind the enclosure's microphone pinhole
and seal around its outside without blocking either the enclosure pinhole or
the tube bore.

Measure duct length along the acoustic path from the exterior side-wall port
to the upward-facing MK1 window. Aim for approximately `10-25 mm`. A direct
run up to about `30-40 mm` is acceptable if the enclosure geometry requires
it; avoid more than about `50 mm`. Do not coil the purchased one-metre tube or
store excess inside the enclosure. Long, narrow runs, tight bends, and
partially flattened sections reduce level and color speech even though the
doorbell operates half-duplex. Dry-fit with about `5 mm` of trimming allowance,
then cut the installed piece to the shortest relaxed route after the PCB
position is final.

Do **not** put the cut metal speaker mesh between the exterior pinhole and the
silicone tube. This indoor `1.0-1.5 mm` port does not need a metal grille, and
mesh can attenuate speech, rattle, shed sharp strands, or prevent the tube from
sealing against the wall. Seat the tube mouth directly behind the deburred
pinhole and seal only around its outside. If later testing demonstrates a real
dust problem, use a purpose-made acoustically transparent membrane only after
comparing recordings; do not improvise with the speaker mesh.

Keep the microphone duct entirely separate from the front speaker opening.
Do not terminate the tube in the speaker cavity, and do not let it touch the
speaker frame or grille; that would mechanically transmit vibration and worsen
speaker-to-microphone leakage.

## Front-Facing Speaker Below The Button

The speaker's approximately `25 x 32 mm` outside envelope is not automatically
the ABS cutout size. The opening follows the sound-producing diaphragm, while
the speaker frame, foam gasket, and mesh require an uncut perimeter land.
Measure the actual diaphragm and draw the opening from it. Rotate the speaker
so its approximately `32 mm` dimension runs left-to-right and `25 mm` dimension
runs top-to-bottom, then place the complete stack on the front lid below the
button using the placement map above.

For the taped first layout, draw three centered landscape outlines:

| Outline | Tentative size | Purpose |
| --- | --- | --- |
| Speaker outside envelope | `32 mm` wide x `25 mm` high | Clearance only; do not cut this full rectangle |
| Finished acoustic opening | Approximately `24 mm` wide x `17 mm` high | Rounded rectangle/oval exposing the diaphragm while retaining about `4 mm` of frame on each side |
| Initial rough opening | Approximately `22 mm` wide x `15 mm` high | First Dremel/file boundary; enlarge only after holding the actual speaker behind it |

For the current pencil layout, the inner rounded outline is the area to be
excavated. The surrounding approximately `32 x 25 mm` rounded rectangle marks
the speaker body and mounting clearance and must remain intact. Put an `X` in
the inner waste area before machining so the two outlines cannot be confused.

The approximately `24 x 17 mm` opening is a conservative estimate from the
seller drawing, not an authoritative received-part dimension. Give it rounded
corners of roughly `4 mm` radius or make it a smooth oval; sharp internal
corners add no useful acoustic area. Center it on the actual diaphragm, not
merely on the wire exit or outside plastic frame. Stop at the `22 x 15 mm`
rough opening, test the real speaker from behind, and file gradually toward the
finished line only where the diaphragm remains unobstructed.

For a finished opening near `24 x 17 mm`, start with a mesh patch around
`28 x 21 mm`. That supplies approximately `2 mm` overlap around the opening
while remaining inside the `32 x 25 mm` speaker envelope. Adjust both sizes to
the received diaphragm and flat mounting land. The mesh, gasket, and adhesive
must stay clear of the moving surround.

The stack from the corridor side toward the enclosure interior is:

```text
indoor corridor
  -> front-lid ABS wall and its acoustic opening
  -> cut metal mesh overlapping the opening from inside
  -> thin closed-cell foam/EVA perimeter gasket
  -> speaker face/frame
  -> speaker body, insulated terminals, and wiring
```

Before cutting, close the empty enclosure with cardboard templates representing
the button's full rear barrel, the speaker body and terminals, both rigid light
pipes, and the camera flex. The speaker may sit visually below the button while
its rear body is shifted a few millimetres laterally to clear D2 or a terminal.
Preserve at least approximately `3-5 mm` between the speaker's outer frame and
the button hardware, lamp-base bodies, and closure-column keepouts.

Cut the ABS opening first, then derive the grille patch from it. The mesh patch
should overlap intact ABS by at least `2-3 mm` around the complete opening,
while still fitting flat beneath the speaker frame/gasket or its separate
retaining bracket. Do not pre-cut the mesh to `25 x 32 mm` solely because that
is the speaker envelope. Cut an oversized rough blank from the `100 mm` mesh
circle, test it against the actual opening, and trim it to its final rounded
shape.

Wear gloves and eye protection when using aviation snips. Short offcuts and
wire strands are sharp and can spring away. After cutting, remove loose strands
and burrs, round every corner, and capture the entire cut perimeter under the
gasket, adhesive, or a folded edge so it cannot abrade wiring. Vacuum and wipe
the work area before bringing the PCB or battery back.

Prefer a removable clamp or small bracket for the speaker. If bonding the mesh,
apply a thin continuous bead of neutral-cure silicone only around its perimeter
and allow it to cure fully before electronics are installed. Keep adhesive and
gasket material off the diaphragm, suspension, acoustic opening, and any rear
speaker vent. The gasket should prevent front sound from leaking around the
frame and cancelling with rear sound. Add compliant retention so the grille
cannot buzz.

Because the speaker is lid-mounted, terminate its lead in the verified `2.0`
plug at J6 and leave a controlled service loop. Add flexible strain relief near
the speaker without gluing its terminals. When opening the enclosure, support
the lid and unplug J6 before allowing the lid to hang; neither the speaker lead
nor camera flex is a hinge or tether.

The speaker is marked `4 ohm`, `3 W`; this is its impedance and power-handling
class, not a promise that the board delivers 3 W. U4 is a MAX98357A powered
from `/SYS`, not a dedicated fixed 5 V rail. Set the usable maximum with
digital volume, clipping, sound-quality, current, and temperature tests.

J6 is a bridged Class-D output:

- J6.1 is `OUTP` and J6.2 is `OUTN`.
- Connect the one speaker only across J6.1 and J6.2.
- Never connect either speaker lead, terminal, or the metal mesh to ground.
- Keep both terminals insulated and mechanically clear of the grille.
- Although the received connector has been verified as `2.0`, confirm its
  housing/latch fit at J6, then verify pin order, polarity, and isolation from
  ground with a meter before power-up.

## Cutting Support And Tools

Sacrificial backing is a **temporary machining aid**, not a structural part of
the finished enclosure. The rigid ABS housing does not need a plywood liner or
permanent reinforcement after machining. Backing reduces local flex, exit-side
chipping, and the chance that a drill grabs as it breaks through; it does not
make an otherwise weak enclosure usable.

Direct backing is not mandatory for every cut. A small pilot, relief, or
`1.0-1.5 mm` microphone hole may be drilled without backing when the local wall
is already rigid, the enclosure is clamped so it cannot move, the bit is sharp,
and low pressure is used near breakthrough. For the `22 mm` step-drilled button
hole, use direct rigid backing whenever it can be fitted. For the camera, lamp
base, and PIR holes, backing is recommended but may be replaced by a padded jig
or clamps that support the wall within a few millimetres of the cut. For the
USB-C and speaker cutouts, use direct backing or support the panel close to the
cut on all practical sides; leave the powered rough cut inside the line and
finish it with hand files. If the ABS chatters, bows, or vibrates, stop and add
closer support rather than applying more tool pressure.

A silicone electronics work mat is not a cutting backer: it does not support
the plastic at breakthrough and can be grabbed, torn, or wrapped by a drill or
rotary cutter. It may remain under the rigid support only as bench protection,
well away from the cutting path.

Because the enclosure has lips and deep walls, a flat sheet under the whole
part may not contact the cutting location. Fit a scrap plywood block inside
the lid or base so it bears directly beneath the marked area. Clamp the ABS
gently against that block without flattening a molded lip or distorting the
panel. Scrap MDF or a smooth hardwood block is also acceptable if it is rigid,
flat, and expendable. Never hold a small backing block by hand behind a powered
bit. Where no block can contact the cut, use padded clamps or a fitted cradle
to restrain the housing close to the work instead.

Available and recommended tools:

- Dremel 4000-2/30, `1.6 A`, corded variable-speed rotary tool;
- Dremel 561 multipurpose spiral-cutting bit from the kit, after confirming it
  is still present and undamaged;
- the available Ryobi variable-speed drill for the large step bit and ordinary
  twist bits, or a drill press if available;
- the available RYOBI A981951 `195-Piece Drill and Driver Bit Set`; use its
  black-oxide twist drills for the ABS work identified below, not similarly
  sized hex driver, masonry, or brad-point bits;
- the available `4-32 mm` HSS titanium-coated step drill for the 22 mm button
  and other larger circles;
- a separate sharp metric `1.0 mm` twist bit for the initial microphone port;
  optional `1.2 mm` and `1.5 mm` bits are also separate purchases if audio
  testing later justifies enlargement;
- fine-tooth razor saw or jeweler's saw, ideally with a small miter block or
  padded wood guide for the `3 mm` acrylic rods;
- flat, half-round, and needle files;
- deburring tool or sharp hand scraper;
- `220`, `400`, `800`, and `1200` grit abrasive paper;
- aviation snips for the loose metal mesh only;
- white china marker/grease pencil for direct marks on black ABS;
- low-tack painter's tape plus a `0.5 mm` mechanical pencil or fine technical
  marker for precise layout lines; and
- calipers, square, awl, clamps, rigid sacrificial plywood, eye protection,
  gloves, and dust collection.

Use gloves only while handling and cutting the loose metal mesh; do not wear
loose gloves near a rotating drill, step bit, or Dremel accessory.

### RYOBI 195-Piece Set Sizes Used Here

The available drill/driver set is RYOBI model `A981951`. The same 195-piece
package is also sold under the `A981952QP` listing. Its black-oxide twist drills
are the set's general-purpose bits intended for plastic. The relevant small
sizes documented for this set are:

| Case label | Metric diameter | Enclosure use |
| --- | ---: | --- |
| `1/16 in` | `1.59 mm` | Smallest twist drill in this set; **too large** for the microphone's `1.0-1.5 mm` limit |
| `5/64 in` | `1.98 mm` | Standard pilot for the step drill and tight USB-C relief holes |
| `3/32 in` | `2.38 mm` | Optional intermediate relief size when the drawn waste area permits it |
| `7/64 in` | `2.78 mm` | Speaker relief holes and roomier USB-C relief holes |
| `1/8 in` | `3.18 mm` | Optional larger relief hole only when it remains safely inside the waste line |
| `9/64 in` | `3.57 mm` | Candidate undersize lamp-base hole after measuring the base |
| `5/32 in` | `3.97 mm` | Candidate undersize lamp-base hole after measuring the base |
| `11/64 in` | `4.37 mm` | Candidate undersize lamp-base hole after measuring the base |
| `3/16 in` | `4.76 mm` | Candidate undersize lamp-base hole after measuring the base |
| `1/4 in` | `6.35 mm` | Available, but the step drill stopped at `6 mm` is preferred for the camera opening |
| `5/16 in` | `7.94 mm` | Available, but the step drill stopped at `8 mm` is preferred for the PIR opening |

Read the size stamped beside the **black-oxide twist-drill** slot in the case
before fitting the bit. The set also contains hex driver bits labeled with
fractional sizes; those are for driving hex-socket fasteners and do not drill
holes. For a measured lamp-base clip-body diameter, subtract `0.5 mm`, then
choose the largest listed twist bit no greater than that result. Drill a scrap
test and hand-ream to the snap fit.

The A981951 set does not replace the separate `4-32 mm` step drill. Use the
step drill for the camera, PIR, and 22 mm button because its gradual enlargement
is easier to control in a thin ABS panel than a large conventional twist bit.
It also does not contain a suitably small microphone bit: `1/16 in` equals
`1.5875 mm`, already beyond the specified `1.5 mm` maximum. Obtain a true
`1.0 mm` bit and preferably turn it in a pin vise; do not substitute `1/16 in`.

### Recommended Bits And Cutters

The sizes below are starting sizes for the measured parts, not permission to
skip the scrap-ABS trial. Use sharp HSS bits intended for metal/plastic. Do not
use masonry bits, spade bits, or a hole saw on this enclosure. A dull bit that
rubs or melts the ABS should be replaced rather than pushed harder.

| Operation | Recommended bit or cutter | Where to stop |
| --- | --- | --- |
| General pilot for the step drill | Set's black-oxide `5/64 in` (`1.98 mm`) twist bit in the Ryobi drill | Through the wall at low speed; the pilot remains smaller than the step bit's `4 mm` first step |
| 22 mm button | `4-32 mm` HSS step bit in the Ryobi drill, after the `5/64 in` pilot | Stop immediately after the `22 mm` step clears the visible face |
| Camera lens | Set's `5/64 in` pilot, then the step bit only to `6 mm`; hand reamer or round needle file afterward | Ream gradually to a non-binding fit slightly over the measured approximately `7 mm` lens base |
| PIR neck | Set's `5/64 in` pilot, then the step bit only to `8 mm`; hand reamer or round file afterward | Stop powered enlargement at `8 mm` and hand-fit the actual tapered neck |
| Black lamp-base hole | Set's `5/64 in` pilot, then the largest available black-oxide twist bit at least `0.5 mm` below the measured clip-body diameter; hand reamer afterward | Select from the conversion table, then ream to the scrap-tested snap fit; do not assume the advertised `3 mm` rod size is the hole size |
| Microphone port | Separate sharp metric `1.0 mm` twist bit, preferably in a pin vise; separate `1.2 mm` and then `1.5 mm` bits only after audio tests | Start at `1.0 mm`; the set's `1/16 in` (`1.59 mm`) bit is too large and must not be used |
| Speaker relief pattern | Set's black-oxide `7/64 in` (`2.78 mm`) twist bit in the Ryobi drill, then Dremel 561 (`3.2 mm`/`1/8 in`) spiral-cutting bit | Keep every relief hole and the 561 path inside the rough waste line; finish with files |
| USB-C corner/relief pattern | Set's black-oxide `5/64 in` (`1.98 mm`) or `7/64 in` (`2.78 mm`) twist bit, selected to preserve the marked corner radius, then Dremel 561 (`3.2 mm`/`1/8 in`) | Keep the powered cut inside the line and finish to the actual plug with needle/flat files |
| ABS edge deburring | Sharp hand scraper or single-flute deburring tool; a countersink may be turned lightly **by hand only** | Remove the burr without forming a visible chamfer or enlarging the opening |
| Acrylic light-pipe fallback | Dremel 426 reinforced cutoff wheel on its correct mandrel | Leave approximately `0.5 mm` extra and finish the LED-facing end on flat abrasive paper |

The Dremel 407 sanding drum may remove a small amount from an inaccessible
rough edge at low speed, but it is not a sizing bit. Grinding stones and the
small brittle 420 cutoff discs are not recommended for the enclosure openings.

### Marking The Black ABS

Manually laying out the features on the received enclosure is useful and is
the final check against the paper template. For direct white marking, use a
**white china marker/grease pencil** intended for glass, plastic, or other
non-porous surfaces. A pull-string china marker is convenient; expose only a
short tip and shape it to a narrow chisel point on scrap abrasive paper. An
ordinary white artist's colored pencil generally will not leave a consistent,
precise line on smooth ABS.

The preferred precision workflow is still to cover the cutting area with one
smooth layer of low-tack painter's tape and draw on the tape with a sharp
`0.5 mm` mechanical pencil or fine technical marker. This gives a thinner line
than a grease pencil, prevents old corrections from remaining on the visible
ABS, and protects the surface from light tool scratches. Use the china marker
directly on uncovered side walls or curved areas where tape will not lie flat.

Use this order:

1. Clean dust and skin oil from the enclosure with a plastic-safe method and
   let it dry. Test the chosen tape and marker on an inconspicuous interior
   area first.
2. Apply tape without wrinkles or overlapping edges through a drilling center.
   Do not stretch the tape because it can relax and move a mark.
3. Mark the measured top-left datum, vertical centerline, enclosure seam,
   closure-column keepouts, USB-aligned PCB outline, and physically projected
   D2/D3 centers.
4. Transfer the camera, PIR, button, mic, speaker, and USB outlines from their
   full-size templates. Trace the actual bezels, grille, and plug shell as a
   second check, but do not use an outside part outline as the cut line unless
   the guide specifically calls for it.
5. Draw both the finished line and a separate rough-cut line `1-2 mm` inside it
   for Dremel work. Mark waste areas with an `X` so the wrong side is not
   removed.
6. Check every center and keepout from the same datum edges with calipers and a
   square. Lightly prick only confirmed drill centers with an awl; do not score
   long lines into the ABS with a knife or metal scriber.
7. Photograph the completed layout with a ruler in frame, close the empty
   enclosure for one last visual check, then machine through the tape.

A fine white or silver water-based paint marker can also mark painter's tape,
but it is not required. Avoid broad paint pens for drill centers, and do not
apply solvent-heavy paint markers directly to the finished ABS without a scrap
test. Grease-pencil marks are for visibility, not measurement: always choose
the cut center from the thin transferred line or awl point rather than from the
edge of a thick white stroke.

The missing A576 sanding/grinding guide and 678 circle/straight-edge guide are
not required for this enclosure. The 565 multipurpose cutting guide shown in
the manufacturer reference below is a different optional attachment and is
not part of the pictured 4000-2/30 contents. It can improve depth control, but
this build does not depend on buying it.

Without a 565 guide, drill closely spaced relief holes well inside the speaker
or USB waste line. Use the 561 only to join those holes and remove central
waste, keeping the bit perpendicular and at least `1-2 mm` inside the final
line. Complete the shape with hand files. The kit's 407 sanding drum and sanding
bands may rough an inaccessible interior edge at low speed, but they remove
material quickly and are not finish tools. Avoid the grinding stones on ABS,
and reserve the cutoff wheels for coarse straight relief cuts where an
overshoot cannot reach the finished outline.

For ABS, start rotary cutting near the low end of the tool manufacturer's
recommended plastic speed and make light passes. Pause if the plastic smears
or melts instead of producing chips. Do not freehand a visible finished edge
with a cutoff wheel. Cut inside the waste line and file to the line.

The `149 g`, `4-32 mm` step bit must be used only in the Ryobi drill or a drill
press. It is too large and heavy for the Dremel 4000's collet, bearings, and
handheld control; never attempt to adapt it to the rotary tool. Seat its shank
fully in a properly sized Ryobi chuck and tighten every chuck position if the
chuck uses a key. Test it at low speed away from the work and do not use it if
the tip or cutting steps visibly wobble. Select the Ryobi's low-speed/high-
torque gear if it has one, disable hammer mode, and use ordinary drilling mode.

For the `22 mm` button hole, clamp the ABS to direct rigid backing so both hands
can control the Ryobi. For smaller round holes, use the support decision above.
Make the `5/64 in` (`1.98 mm`) pilot, begin the step bit at low trigger speed,
keep the drill perpendicular, and let it cut without leaning on it. Identify
the `22 mm` step before starting and stop as soon as that step has passed
through the button opening; the next step will make the hole oversized. The
Dremel remains reserved for the 561 spiral bit, sanding drum, and small
cutoff-wheel work described above.

Manufacturer references:

- [Dremel 4000 specifications](https://www.dremel.com/us/en/p/4000-2-32-f0134000fb)
- [Dremel 561 multipurpose cutting bit](https://www.dremel.com/us/en/p/561-26150561ac)
- [Dremel 565 multipurpose cutting guide](https://www.dremel.com/us/en/p/565-26150565ac)
- [RYOBI A981951 195-piece set identification and intended materials](https://www.homedepot.ca/product/ryobi-drill-and-driver-bit-set-195-piece/1001042704)
- [RYOBI A981952QP detailed set contents](https://www.retailmarket.net/products/ryobi-a981952qp-195-piece-drilling-and-driving-kit-for-wood-plastic-metal-and-masonry-work/)

## Opening Method By Feature

| Feature | Tools | Support | Final-fit requirement |
| --- | --- | --- | --- |
| 22 mm button | Ryobi, set's black-oxide `5/64 in` (`1.98 mm`) pilot, then `4-32 mm` step bit; hand scraper for deburring | Direct rigid backing strongly recommended | Drill from the visible face, stop at 22 mm, retain the supplied gasket, and enlarge only enough for a free, non-rocking fit |
| Camera | Ryobi, set's `5/64 in` pilot, step bit stopped at `6 mm`, then hand reamer/round needle file | Direct backing recommended; a close padded jig is acceptable | Clear the measured approximately 7 mm circular base without binding; live-test and bevel only enough to eliminate vignetting |
| Speaker | Ryobi and set's black-oxide `7/64 in` (`2.78 mm`) relief bit; Dremel 4000 with 561 bit; half-round/flat files | Backing or close panel support recommended | File to the measured diaphragm outline while preserving a continuous mesh/gasket overlap land |
| USB-C | Ryobi and set's black-oxide `5/64 in` (`1.98 mm`) or `7/64 in` (`2.78 mm`) corner/relief bit; Dremel 4000 with 561 bit; needle/flat files | Backing or a fitted cradle supporting the wall close to the cut recommended | File to a cable-tested rounded rectangle; leave clearance for the complete plug shell and strain relief |
| Microphone | Pin vise preferred, or Ryobi, with a separate sharp metric `1.0 mm` bit; separate `1.2/1.5 mm` bits only if testing requires enlargement | Optional if the wall is rigidly clamped and cannot flex | Deburr without enlarging and align it to the separate silicone duct; do not use the set's `1/16 in` bit |
| Black lamp base | Ryobi with the set's `5/64 in` pilot and a measured undersize black-oxide finish bit selected from the conversion table, then hand reamer | Recommended; may be omitted for a rigidly clamped panel and sharp small bit | Validate the actual clip body and panel thickness in scrap; `3 mm` is not necessarily the panel-hole size |
| PIR contingency | Ryobi with the set's `5/64 in` pilot and step bit stopped at `8 mm`, then hand reamer/round file | Direct backing recommended; a close padded jig is acceptable | Fit the actual tapered neck without squeezing it; do not jump directly to the approximately `13 mm` maximum dome size |

## Marking And Cutting Sequence

1. **Tools: correct hand screwdrivers and a parts tray.** Remove the front lid,
   PCB, camera, LiPo, speaker, loose fasteners, and every wire before machining.
2. **Tools: calipers, small square, ruler, painter's tape, and `0.5 mm` pencil.**
   Measure the `77 x 125 mm` front face, its four corner holes, the internal
   screw columns, wall thickness, lips, ribs, and curved areas. Draw explicit
   no-cut keepouts around them.
3. **Tools: M2.5 hand screwdriver, calipers, square, and the actual USB cable.**
   Dry-fit the PCB on loose standoffs with the cable inserted. Move the PCB only
   until USB-C is square, approximately flush or slightly recessed, and free of
   side load. Confirm PCB-to-wall, boss, battery, and button clearances.
4. **Tools: Ryobi drill with the set's black-oxide `5/64 in` (`1.98 mm`) or
   `7/64 in` (`2.78 mm`) relief bit, Dremel 4000 with 561 bit, needle and flat
   files, clamps, and rigid backing or a support cradle.** Mark and machine the
   USB-C opening first with all electronics removed. Keep the powered cut
   inside the line, deburr it, and repeat the cable fit until the final PCB
   position is known.
5. **Tools: M2.5 hand screwdriver, calipers, adhesive mixing stick/applicator,
   masking material, and timer.** Bond and fully cure the four standoffs at that
   exact PCB position using the procedure below. Reinstall the PCB and confirm
   that USB alignment did not move. Do not later move the PCB for appearance.
6. **Tools: calipers, square, ruler, paper template, and sharp pencil.** Project
   the physical centers of D3 and D2 perpendicular to the front lid. Measure
   from common datum edges, mark both axes, and verify them independently.
7. **Tools: calipers, ruler, pencil, and a short `4 mm` OD tube offcut.** With
   the cured PCB installed, transfer MK1's actual acoustic-hole station to the
   left side. Measure clearance `H`, mark the port center at `H - 2 mm` from the
   inside rear floor, and verify it with the tube offcut before drilling.
8. **Tools: full-size paper/cardboard templates, scissors, painter's tape,
   calipers, and square.** Arrange the camera, PIR, button, and landscape speaker
   around the fixed light-pipe axes and closure-column keepouts. Dry-fit every
   component, flex, pigtail, tube, and cable bend; close without force.
9. **Tools: painter's tape, `0.5 mm` pencil or fine marker, calipers, square, and
   awl.** Cover both faces of each remaining cutting area, transfer the template
   to the visible face, and check it against real parts from both sides. Lightly
   prick confirmed centers, then remove every electronic and wired part.
10. **Tools: the same drill, Dremel bits, files, and reamers specified in the
    feature table.** Make the complete remaining pattern in scrap ABS or a spare
    enclosure first. Correct the template before cutting the final enclosure.
11. **Tools: fitted scrap plywood/MDF/hardwood block or padded support jig, plus
    clamps.** Directly back the button hole and other cuts where practical. For
    cuts where backing is optional, confirm the clamped wall cannot flex. Keep
    the silicone work mat out of every powered tool path.
12. **Tools: awl, Ryobi drill, the set's sharp black-oxide `5/64 in` pilot bit
    and `7/64 in` relief bit, plus a separate metric `1.0 mm` microphone bit.**
    Mark centers lightly, use the bit assigned in the table, drill at low
    speed, reduce pressure near breakthrough, and clear chips frequently.
13. **Tools: Ryobi drill and `4-32 mm` step bit.** Drill round holes from the
    visible face at low speed. Approach the final step slowly and stop before
    the next diameter enters the ABS; never put the step bit in the Dremel.
14. **Tools: Ryobi drill and the set's black-oxide `7/64 in` (`2.78 mm`)
    relief bit, Dremel 4000 with 561 bit, then half-round and flat files.** Make
    speaker relief holes inside the waste, join them while remaining `1-2 mm`
    inside the line, and hand-file to final shape. A Dremel 565 guide is
    optional.
15. **Tools: aviation snips, gloves, eye protection, flat file, and pliers for
    folding or containing edges.** Cut and finish the speaker mesh away from all
    electronics. Collect every offcut and loose strand.
16. **Tools: hand scraper/deburring tool, needle files, abrasive paper, vacuum,
    and soft brush.** Remove tape, deburr both faces by hand, and remove all
    plastic and metal debris. Do not flame-polish ABS.
17. **Tools: actual components, actual USB plug, calipers, hand screwdrivers,
    and inspection light.** Trial-fit every interface without adhesive. Confirm
    button travel, camera/PIR view, light-pipe alignment, lamp retention, grille
    overlap, speaker clearance, USB insertion, and closure-screw access.

For the current build, the standoffs were already aligned and bonded while the
USB-C opening was still only marked. Do not disturb or machine near them during
the adhesive's fixture or full-cure interval. After full cure, remove the PCB
and every electronic part, support the wall with fitted plywood or a close-
support cradle, cut the USB opening undersize, and file it to the actual cable
plug. Reinstall the PCB to verify strain-free insertion; do not shift the cured
standoffs to compensate for the opening.

## PCB Standoffs And USB-C Position

The photographed placement is the primary mechanical datum: the PCB is flat
on four standoffs in the deep base, and the USB-C receptacle is aligned with
the underside edge for easy charging and firmware access. Establish this
position before placing any front-panel component. Once the standoffs are
bonded, the two rigid light-pipe axes are consequences of this position and
must not be adjusted independently.

- The PCB must be supported only by its four standoffs. It should not rest on
  the enclosure edge, a molded boss, or the USB-C receptacle.
- Leave approximately `0.5-1 mm` clearance from PCB edges to enclosure walls
  wherever practical so molding variation and vibration do not wedge the
  board.
- Align the USB-C receptacle with the opening, but keep its front edge flush
  with or slightly recessed behind the enclosure's exterior surface. A
  protruding connector is easier to strike and lever off the PCB.
- Size the opening using the actual charging/data cable, including the plug's
  molded shell. The plug must insert straight without the ABS pushing it up,
  down, or sideways.
- Do not place a standoff or adhesive fillet beneath the USB opening. Repeated
  cable insertion loads must be carried by the mounted PCB without flexing it.
- Confirm that all four enclosure closure screws remain accessible with the
  PCB installed.
- Do not shift the PCB for a more symmetrical front-panel arrangement after
  the USB position is correct. Camera, PIR, and button connections provide the
  placement flexibility; the rigid D2 and D3 light pipes do not.

To install the standoffs:

1. **Tools: calipers or depth gauge, M2.5 screws, and hand screwdriver.** Verify
   screw length and approximately `3-5 mm` thread engagement in all four
   standoffs away from the enclosure. Confirm that no screw bottoms out.
2. **Tools: M2.5 hand screwdriver.** Attach the standoffs loosely to the PCB
   with nylon washers and screws. Do not use a powered driver.
3. **Tools: painter's tape or protective film, disposable mixing card, mixing
   stick, and small adhesive applicator.** Cover nearby PCB areas and place only
   a small amount of plastic-compatible bonder on each standoff base. Follow
   the adhesive instructions and wear any gloves they specify.
4. **Tools: calipers, square, actual USB cable, and temporary low-tack tape if
   needed.** Position the PCB at its exact final USB and wall clearances. Use it
   only as a temporary alignment jig while the standoffs set.
5. **Tools: timer and M2.5 hand screwdriver.** Observe the stated fixture and
   full-cure times. Remove the screws and PCB only when doing so cannot shift
   the standoffs. If the PCB must remain as the jig, keep epoxy off it and apply
   no cable, cutting, or side load while curing.
6. **Tools: small adhesive applicator.** After removing the PCB, allow any
   remaining full-cure interval to pass. Add a small fillet only if the adhesive
   instructions and clearances permit it.
7. **Tools: M2.5 hand screwdriver and inspection light.** Reinstall the PCB and
   washers. Tighten evenly just past snug; do not bow the PCB or strip the
   bonded standoffs.

The edge-accessible USB arrangement does make charging and firmware updates
easier. Its success criterion is a receptacle approximately flush with or
slightly recessed behind the exterior, plus strain-free insertion. The PCB
itself must not be physically pressed against the enclosure wall.

## Battery Adhesive Fastener

Retain the `103450` LiPo vertically on the right interior wall with its `50 mm`
dimension vertical, `34 mm` dimension front-to-back, and `10 mm` thickness
projecting inward. Keep it entirely in the deep-base half so opening the lid
does not pull on the pouch or leads.

Use a removable adhesive-backed hook-and-loop fastener or a light strap with
adhesive anchors. Prefer bonding the removable fastener to a thin fishpaper or
plastic carrier around the battery rather than applying an aggressive adhesive
directly to the bare pouch. Provide a pull tab and remove the battery by
separating the fastener, not by prying or sharply bending the cell.

Before applying adhesive, clean the enclosure contact area according to the
fastener manufacturer's instructions and let it dry. Use enough area to resist
the door's repeated acceleration without compressing the pouch. Add a thin
non-compressing pad only where needed to prevent rattle. Do not:

- clamp, bend, puncture, or tightly wrap the pouch;
- place hard PCB solder joints, mesh edges, screw tips, or button terminals
  against it;
- cover a swollen or damaged cell to force it to fit;
- bridge the lid/base seam with the battery or its fastener; or
- trap the battery lead so opening or servicing the enclosure pulls on it.

Keep fishpaper/Kapton between the battery zone and conductive or sharp parts,
and leave a service loop to J1.

## Ventilation And Closed-Enclosure Thermal Check

Do not add dedicated ventilation holes to this indoor enclosure unless closed-
enclosure testing identifies a real thermal problem. The speaker opening,
microphone pinhole, USB-C cutout, button, and lamp-base interfaces already make
the machined case non-hermetic. More holes primarily admit dust and insects,
weaken the ABS, and can create another acoustic path between the front speaker
and microphone.

Bottom-only holes produce little useful convection without a corresponding
upper outlet. They also do not make a damaged or failing LiPo safe. The battery
must instead be protected from puncture and compression, retained without
covering damage or swelling, and operated within the cell and charger
manufacturers' limits.

After assembly, run a representative worst-case closed-enclosure check that
includes charging from a low state, Wi-Fi and camera activity, speaker
playback, and several consecutive doorbell events. Stop for abnormal heating,
odor, swelling, resets, or charging faults. If measurements reveal excessive
temperature, investigate charging current, duty cycle, component dissipation,
and battery placement before considering vents. Add vents only from measured
evidence and keep any eventual opening away from the battery pouch, mic duct,
speaker cavity, USB-C receptacle, and exposed electronics.

## Internal Assembly Order

The USB opening and standoffs are established earlier so the rigid light-pipe
axes can be transferred before the other front holes are cut. After all
remaining machining is complete:

1. **Tools: vacuum, soft brush, inspection light, and lint-free wipe.** Remove
   every plastic chip, metal strand, and abrasive particle, including debris
   around the bonded standoffs. Keep electronics and the LiPo away until the
   work area is clean.
2. **Tools: inspection light, M2.5 hand screwdriver, and actual USB cable.**
   Inspect the four `10 mm` standoff bonds, reinstall the PCB, and verify the
   final USB-C position once more.
3. **Tools: button nut wrench or correctly sized spanner, small hand
   screwdrivers, tweezers, labels, and heat-shrink/heat gun where required.**
   Install the camera and PIR retention, button gasket/nut, and black lamp
   bases. Tighten the button only enough to prevent rotation. Label, insulate,
   and secure the disconnected PIR pigtail.
4. **Tools: painter's tape, calipers, fine-tooth razor/jeweler's saw, padded
   miter block, flat abrasive block, and `400/800/1200` grit paper.** Transfer,
   cut, finish, and fit each light pipe using its dedicated procedure above.
   Remove the PCB before applying any retention silicone.
5. **Tools: scissors or craft knife for the closed-cell gasket, small bracket
   hand tools or silicone applicator, heat-shrink and heat gun, and tweezers.**
   Install the front-lid mesh, gasket, and landscape speaker. Insulate its
   terminals and add the flexible J6 service loop and strain relief. Do not cut
   mesh during final assembly.
6. **Tools: sharp scissors or tube cutter, fine pointed cutter, tweezers, and a
   hot-glue gun with a fine applicator.** Seal the PCB-side tube end with hot
   glue, cut the side window slightly back from that end, align and hot-glue the
   window to the acoustic hole under MK1, and leave the enclosure-side end open
   behind the side-wall pinhole. Seal around both interfaces without blocking
   the tube bore, MK1 hole, or enclosure pinhole, and do not bow the PCB.
7. **Tools: M2.5 hand screwdriver.** Install the PCB with four nylon washers and
   correctly sized M2.5 screws. Tighten evenly just past snug.
8. **Tools: scissors, plastic-safe cleaning wipe specified by the fastener
   maker, ruler, and hand roller or firm finger pressure.** Attach the battery's
   removable fastener/carrier to the right wall, add insulation, and retain the
   battery without compression. Observe the fastener's dwell time.
9. **Tools: tweezers, flush cutters, and cable ties or adhesive tie mounts.**
   Route the speaker wires away from the camera flex and ESP32 antenna. Keep the
   mic tube away from the speaker and every cable away from sharp mesh, button
   terminals, screw threads, and the lid lip. Cut only tie tails, never wiring.
10. **Tools: digital multimeter in continuity/resistance mode.** With all power
    absent, perform the continuity and short checks, including isolation of both
    speaker leads and the metal mesh from ground. Then connect the battery.
11. **Tools: inspection light and the correct enclosure hand screwdriver.**
    Close the enclosure gradually while watching every internal part. Stop if
    the lid presses on the LiPo, PCB, camera flex, speaker, light pipes, or
    button terminals; tighten the four closure screws evenly by hand.

## Mounting To The Apartment Door

Apply renter-safe adhesive mounting strips or another approved removable
fastener to the flat rear of the deep base, not across the removable lid or
its four closure screws. Follow the fastener's surface-cleaning, load, dwell,
and removal instructions. Use multiple separated strips so the enclosure
cannot pivot when the button is pressed or a USB cable is inserted.

Use a tape measure and pencil or removable tape to set the height, a small
level to keep the housing vertical, the surface-cleaning wipes specified by
the mounting-strip maker, and firm hand pressure or a small hand roller to seat
the strips. Do not drill the apartment door unless the owner has approved a
specific mechanical fastener and the door construction has been verified.

Test Wi-Fi/Bluetooth performance with the closed unit held at the exact final
location before committing the door adhesive. A metal apartment door can
affect the ESP32 antenna even though the enclosure is plastic. If reception is
poor, adjust placement or add a non-metallic stand-off layer before making
electrical or PCB changes. Use a discreet secondary safety tether if permitted
and if a falling enclosure could strike someone or damage the LiPo.

## Acceptance Checks

- Inspect the four standoffs for full bonding and verify that the PCB is not
  touching an enclosure edge or boss.
- Insert the real USB-C cable repeatedly. Its shell must not bind on the ABS,
  and the PCB or receptacle must not visibly flex.
- Verify the speaker plug pin positions and continuity. Neither speaker lead
  may have continuity to ground or the metal grille.
- Start playback at low digital volume and increase in small steps. Listen for
  clipping, grille buzz, and air leaks; check U4, the speaker, and power path
  for abnormal heating on both battery and USB power.
- Record visitor speech through the completed mic duct with the speaker silent,
  then test half-duplex operation for acoustic leakage. Do not infer
  full-duplex capability.
- Inspect a live camera frame in the actual corridor. Check all four corners
  for vignetting and check for button/light-pipe reflections.
- Confirm that the contingency PIR dome has an unobstructed view, cannot move
  when the door closes, and has its unused J7 pigtail insulated and secured.
  Perform a functional detection test only after PIR firmware is enabled.
- Verify button travel and ring illumination without panel flex.
- Confirm both lamp bases remain clipped in place and neither rod preloads the
  PCB when the four enclosure screws are tightened.
- Tug wiring and the battery fastener gently. Nothing should approach the
  speaker mesh, button tabs, closure screws, or camera flex, and the battery
  must not shift when the closed enclosure is handled like a door-mounted
  product.
- Run a representative charging and operating cycle with the enclosure closed
  and confirm there is no abnormal temperature rise, odor, swelling, or reset.
- Press the installed button repeatedly and connect/disconnect USB while the
  enclosure is mounted. The mounting strips must not peel, rock, or creep.

Record the final hole diameters, speaker-opening outline, mesh dimensions,
feature center coordinates from the `77 x 125 mm` face, standoff screw length,
adhesives, photographs, and maximum validated playback setting in this file or
a linked as-built record. Until those values are measured on the completed
unit, dimensions identified as approximate remain construction starting points.

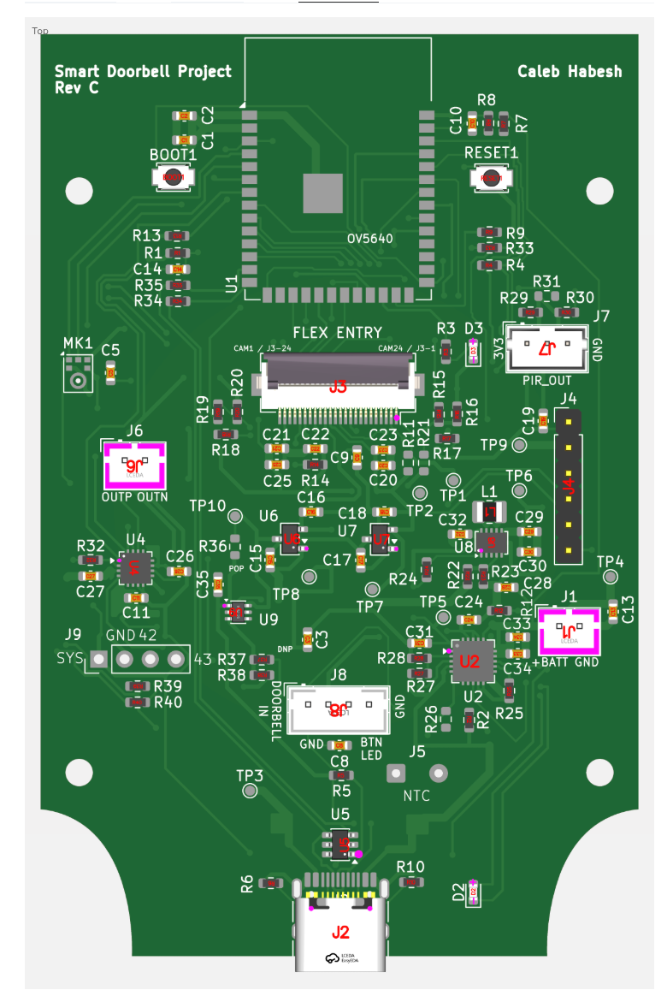
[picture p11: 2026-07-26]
pcb/smart-doorbell/jlcpcb/rev-c/evidence/JLCPCB-assembly-preview-top.png

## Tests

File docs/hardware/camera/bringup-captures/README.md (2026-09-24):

# Camera bring-up capture

The retained color-bar frame is an OV5640 internal test pattern used during Rev C camera bring-up. The person and room test frames were removed from the public working tree; timing and exposure findings remain in the [hardware bring-up record](../../../hardware-bringup.md).

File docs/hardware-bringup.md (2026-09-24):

# Smart Doorbell hardware bring-up

This guide preserves the measured Rev B first-article record and defines the
separate Rev C first-power plan. Revision-specific population and rail behavior
must not be mixed: Rev B has the defective same-number J3 routing and an
always-powered camera rail, while Rev C has the physically mirrored J3 routing
and GPIO42-controlled camera power.

## Scope and hardware baseline

The receiving, rework, and measured-progress sections below apply only to the
delivered Rev B batch:

| Item | Identifier |
| --- | --- |
| JLCPCB web order | `W2026071513150300` |
| PCB order | `Y7-6841583A` |
| PCBA order | `SMT026071560509` |
| Received | 2026-07-23 |

The retained order contains five PCBs with five top-side economic PCBA
assemblies. The JLC assembly installed 84 top-side reference placements on each
board. These two parts were deliberately excluded and must be fitted by hand:

| Reference | Exact part | Method |
| --- | --- | --- |
| U1 | ESP32-S3-WROOM-1-N16R8 | Reflow/hot air |
| MK1 | ICS-43434 bottom-port I2S microphone | Reflow/hot air |

For the delivered Rev B boards only, do not populate the DNP or contingency
parts during this guide: R11, R21, R31, R37, U9, J5, or J9. In particular,
R11 and R21 keep J3 pads 24 and 23 isolated by default. Rev C deliberately
populates R37 and U9 and is covered in the dedicated section below.

### Materials cross-reference

The following status comes from the current repository records plus the latest
receipt report. "Recorded existing" means a prior project record identifies the
item, but it must still be found and inspected before use. It does not prove
that every accessory or connector is present.

| Material | Recorded specification | Status and use in this guide |
| --- | --- | --- |
| Rev B PCBA | Five boards from the retained JLC order above | Received; select one first article |
| Enclosure | Black solid-cover `DS-AG-0813`-style ABS, nominal `80 x 130 x 70 mm` | Received with the housing order; measure the actual clone before drilling |
| Adhesive Velcro | Thin battery-retention material | Received; dry-fit only, do not attach during electrical bring-up |
| PCB standoffs | M2.5 female-to-female, selected height `10 mm`, outside diameter ideally no more than `5 mm` | To order; existing `6 mm` parts are about `1 mm` shorter than the unused molded bosses; verify actual thread, height, screw engagement, and PCB clearance |
| U1 | `ESP32-S3-WROOM-1-N16R8`, previously purchased through AliExpress | Recorded purchased; verify the exact `N16R8` marking before reflow |
| MK1 | TDK InvenSense `ICS-43434`, five previously purchased through AliExpress | Recorded purchased; verify dry-pack condition, package marking, and pin 1 |
| Battery | 1S `103450`, nominal `3.7 V`, `50 x 34 x 10 mm`, JST-PH 2.0, advertised `2000 mAh` | Recorded existing; the record does not establish pack protection, so verify protection and polarity |
| Camera | Fixed-focus `DCXYX-LZTKQJ-5M-357-V1` OV5640, 24-pin 0.5 mm FPC | Recorded selected; leave disconnected in this guide |
| Button | 22 mm white-LED metal momentary button | Recorded existing; reserve its approximately `31 mm` internal depth during dry fit |
| Speaker | Original tested unit: `8 ohm`, `1 W`, approximately `24 x 15 mm`; current enclosure target: one seller-described `4 ohm`, `3 W`, `2.0`-terminal speaker from a five-piece pack | New speaker and metal cover recorded 2026-08-10; dimensions, connector fit, loudness, temperature, and finished-enclosure response remain unvalidated |
| Mic duct | Silicone tube, `2 mm ID x 4 mm OD`, 1 m | Recorded existing; use only for a non-destructive clearance check |
| Light-pipe stock | `LPA3.5-21.1 mm` sample, ten `3 x 100 mm` clear acrylic rods, ten black 3 mm clip bezels | Recorded purchased; do not cut until the measured lid spacing is known |
| Optional PIR | AM312, approximately 13 mm dome and 25 mm overall depth | Recorded existing; leave disconnected in this guide |
| Harness materials | JST-PH 2.0 pigtails including 4-pin 26 AWG, heat shrink | Recorded existing; not needed for rail validation |

Before starting, locate the exact U1, MK1, battery, and a suitable power lead.
The enclosure, Velcro, standoffs, camera, button, speaker, PIR, light pipes, and
wiring are not required to prove the bare PCBA power tree. Missing mechanical
consumables must not delay the electrical first-article test.

The records do **not** confirm receipt of every item in the mechanical shopping
list. Confirm these separately before permanent enclosure work: matching M2.5
screws and nylon washers, plastic-compatible structural epoxy, battery-side
fishpaper/Kapton insulation, flexible neutral-cure sealant, foam/EVA speaker
gasket, and any acoustic vent membrane.

## Equipment and safety

Prepare an ESD-safe work surface, magnification, a multimeter with insulated
probe tips, a regulated 5 V bench supply with adjustable current limit, and a
known-good protected one-cell LiPo. A thermal camera is useful but not required.
Also prepare secure miniature grabbers or soldered temporary power leads,
no-clean flux, suitable solder paste, hot air plus bottom preheat/hot plate as
needed, tweezers, IPA for board surfaces, and a timer. Use a USB-C power source
or USB power meter only after the controlled bench-supply check passes.

Do not hold loose multimeter probes on TP3 and TP9 while reaching for the supply
switch. Use mechanically secure, polarity-marked leads; TP3 is not protected
against a reversed bench connection. Keep USB, the battery, and the bench
supply disconnected whenever resistance mode is selected or soldering is in
progress.

Before every voltage measurement, confirm that the meter lead is in its
`V`/`ohms` jack, not the current jack. Never place a meter configured for
current directly across a rail. Do not probe the closely spaced live USB-C
contacts; use the test points instead.

On Rev B, the populated 10 kOhm R26 makes THERM see a nominal temperature but
does not measure the cell. On Rev C, R26 is DNP and J5 is only an external
thermistor solder-pad connection; no NTC is included in the JLCPCB BOM. Do not
charge a battery on Rev C until a suitable 10 kOhm-at-25-degrees-C NTC has been
wired to J5 and thermally attached to the cell. Any initial charge must be
attended, at room temperature, on a non-flammable surface, with a protected
cell whose datasheet permits the designed approximately 213 mA charge current.
Do not use a swollen, dented, punctured, deeply discharged, unprotected, or
polarity-unknown pouch cell.

J5 connects directly to the MCP73871 `THERM` charging-safety input. It is not
routed to an ESP32 ADC and firmware cannot report thermistor temperature. The
ESP32 can read only battery voltage, through the R7/R8 100 kOhm/100 kOhm
divider and C10 filter on GPIO1.

## First-article record

Create a record for the selected board before changing it:

| Field | Record |
| --- | --- |
| Board label/serial | |
| Top and bottom photographs | |
| U1/MK1/DNP inspection result | |
| Ambient temperature | |
| Bench-supply model and settings | |
| Battery measured voltage and polarity | |
| Resistance readings before U1 | |
| Rail/current readings before U1 | |
| Resistance and rail/current readings after U1 | |
| Resistance and rail/current readings after MK1 | |
| Enclosure and standoff measurements | |

Use the same meter, range, probe polarity, and settling time for all resistance
comparisons:

| Rail | As received | After U1 | After MK1 |
| --- | --- | --- | --- |
| TP3 `+5V` to TP9 | | | |
| TP4 `+BATT` to TP9 | | | |
| TP5 `SYS` to TP9 | | | |
| TP6 `+3V3` to TP9 | | | |
| TP7 `+2V8` to TP9 | | | |
| TP8 `+1V5` to TP9 | | | |
| TP10 `CAM_3V3` to TP9 | | | |

Record powered results at each assembly stage:

| Measurement | As received | After U1 | After MK1 |
| --- | --- | --- | --- |
| Supply voltage/current limit | | | |
| Input current at 5 s / 60 s | | | |
| TP3 `+5V` | | | |
| TP4 `+BATT` | | | |
| TP5 `SYS` | | | |
| TP6 `+3V3` | | | |
| TP7 `+2V8` | | | |
| TP8 `+1V5` | | | |
| TP10 `CAM_3V3` | | | |
| Warmest part and temperature | | | |

Retain at least one untouched PCBA until the first article passes. If a reading
is suspicious but not a hard short, compare it with that untouched board before
rework.

## Test points

Use TP9 as the fixed ground reference. Attach a grabber to TP9 first and use one
hand-held insulated probe for the positive test point. These USB-only
expectations describe Rev B:

| Test point | Net | USB-only expectation |
| --- | --- | --- |
| TP3 | `+5V` / USB VBUS | Near the applied 5 V |
| TP4 | `+BATT` | Do not use as a pass/fail reading with no cell fitted |
| TP5 | `SYS` | Near the active power source; it is not the 3.3 V rail |
| TP6 | `+3V3` | About 3.3 V |
| TP7 | `+2V8` | About 2.8 V |
| TP8 | `+1V5` | About 1.5 V |
| TP9 | `GND` | Ground reference |
| TP10 | `CAM_3V3` | About 3.3 V through populated R36 (Rev B only) |

TP1 and TP2 are not supply test points. On Rev B they expose the contingency
nets at J3 pads 24 and 23; because Rev B is physically mirrored, those pad
numbers must not be called the installed camera-pin numbers. On Rev C, TP1
exposes camera pin 24 through physical J3 pad 1 and TP2 exposes camera pin 23
through physical J3 pad 2.

For the Rev B first powered check, use these as investigation bands rather than
production calibration limits: TP6 `3.20-3.40 V`, TP7 `2.70-2.90 V`, and TP8
`1.45-1.55 V`. TP10 should closely track TP6 because R36 is the populated
zero-ohm bypass.

On Rev C, R36 is DNP and U9 is the only path from `+3V3` to `CAM_3V3`.
GPIO42/R37 must default low. With U1 absent or firmware holding GPIO42 low,
TP10, TP7, and TP8 should be off; TP6 remains about 3.3 V. After controlled
camera-power enable, TP10 should be about 3.3 V, TP7 about 2.8 V, and TP8 about
1.5 V. A grossly wrong, oscillating, or collapsing rail is a failure; record
exact values rather than writing only "pass."

## 1. Receiving inspection and non-destructive fit check

1. Reconcile the shipping label with the retained order identifiers above.
   Do not mix this batch with the cancelled duplicate order.
2. Count the five PCBAs and check each board for shipping damage, bow, cracked
   MLCCs, damaged connectors, or loose parts. Keep each board in its ESD
   packaging except while inspecting it.
3. Label one board as the first article and photograph both sides before any
   rework. Confirm U1 and MK1 are empty. Confirm R11, R21, R31, R37, U9, J5,
   and J9 are unpopulated; bare TP1-TP10 and H1-H4 are intentional.
4. Under magnification, inspect factory placements and joints. Pay particular
   attention to U2, U4-U8, L1, J1-J4, J6-J8, polarized D2/D3, and small parts
   near the empty U1/MK1 lands. The protected per-reference assembly record is
   `pcb/smart-doorbell/production/Smart_Doorbell_Project_B_bom-JLCPCB_FINAL.csv`.
5. Without installing screws, place the unpowered board in the received
   enclosure. Record inside width, height, base depth, lid depth, ribs/bosses,
   seam overlap, and the usable flat mounting area. Confirm that the roughly
   `59 x 91 mm` PCB fits and that the USB-C overhang is not forced against ABS.
6. Test the received standoff/screw stack with the four `2.7 mm` M2.5 mounting
   holes on their `51.4 x 51.4 mm` pattern. Record height, outside diameter,
   screw length, washer stack, and underside clearance. Do not force an
   incorrect thread and do not bond anything yet.
7. Temporarily place the battery on the right wall, button in the lower-centre
   lid volume, speaker at a side/bottom grille candidate, and mic tube under the
   upper-left MK1 area. Check volume only: do not flex the pouch, compress the
   tube enough to bow the PCB, peel adhesive backing, drill, or cut parts.

Photographs and measurements from this step turn the marketplace enclosure and
standoff descriptions into verified first-article dimensions.

## 2. Before soldering: test the assembled PCBA

1. With no USB, battery, camera, speaker, or external connector attached, use
   resistance mode from TP9 to TP3, TP4, TP5, TP6, TP7, TP8, and TP10. A
   capacitance-charging reading is normal. A stable near-zero-ohm reading or
   sustained continuity beep is not; stop and compare with another untouched
   board before applying power. Record the settled reading and probe polarity,
   because semiconductor paths can make the two directions differ.
2. Connect the bench supply while it is off: positive lead to TP3 and negative
   lead to TP9. Verify polarity at the attached leads with the meter before
   connecting them to the PCBA. This powers the same `+5V` net as USB without
   probing USB-C contacts.
3. Set 5.0 V and a 100 mA current limit, then enable the supply. A brief
   capacitor inrush is normal. If the supply remains in current limit, a part
   heats, there is an odour, or a rail is missing, turn it off immediately. If
   there is no fault indication but normal startup is limited by 100 mA, increase
   the limit cautiously to 250 mA and repeat.
4. Record input current after approximately 5 seconds and 60 seconds. There is
   no fixed pass current yet; repeatability and the absence of foldback or
   heating matter more than a guessed number.
5. Measure TP3, TP5, TP6, TP7, TP8, and TP10 against TP9. Record the readings.
   The regulated rails must be close to 3.3 V, 2.8 V, and 1.5 V as listed above.
   `SYS` follows the selected power source, so do not reject it merely because it
   is not 3.3 V.
6. Keep power applied for one minute while checking U2, U8, L1, U6, and U7 for
   abnormal heating. Disconnect power before moving clips or changing meter
   mode. Do not use a finger as the only temperature instrument around a
   suspected fault.
7. Remove the bench supply. Then perform one USB-C connector check without a
   battery: use a normal 5 V USB-C supply or a USB power meter, not loose meter
   probes in the receptacle. Confirm the same rail readings and no abnormal heat.

### Battery and charger check

Do this only after the USB-only test passes.

1. Inspect the pouch and verify that its protection circuit is documented or
   physically present. Measure its open-circuit voltage. If it is swollen,
   damaged, polarity-unknown, unexpectedly below its permitted discharge
   voltage, or protection cannot be established, do not connect it.
2. With all power removed, verify board and harness polarity independently:
   J1 pin 1 must have continuity to TP4 (`+BATT`) and J1 pin 2 to TP9 (`GND`).
   Verify which harness contact reaches battery positive. Do not trust wire
   colour or generic JST-PH polarity.
3. With the camera, speaker, external button, and PIR disconnected, connect the
   protected 1S LiPo with USB disconnected. Verify TP4 matches the cell voltage,
   TP5 follows the battery path, and TP6, TP7, TP8, and TP10 are regulated
   correctly.
4. Flash the bounded battery diagnostic, disconnect USB, attach secure meter
   leads at TP4/TP9, reset the board on battery-only power, and record the meter
   reading. The image takes 64 samples once and then stops sampling. Because
   the native USB console is unavailable during battery-only operation,
   reconnect USB after the measurement; the diagnostic repeats the retained
   result every five seconds without resampling. Do this only after the J5 NTC
   is installed, because reconnecting USB enables the hardware charger. Record
   the GPIO1 ADC result beside the TP4 reading. Calibrated millivolts are
   reported when eFuse calibration is available, with only the nominal 2:1
   divider ratio applied. Do not use this first comparison as a low-battery
   cutoff. Reset the board for each additional comparison point.
5. Disconnect the cell. Reconnect the current-limited 5 V source to TP3/TP9,
   using a limit that permits the approximately 213 mA programmed charge plus
   the measured system load; 400 mA is a reasonable initial ceiling after the
   USB-only check has passed. Reconnect the cell and observe the first few
   minutes of charging. The charge current is designed for approximately
   213 mA but will vary with cell state, input limit, and system load. Watch
   battery voltage and U2 temperature; stop for unexpected heating, smell,
   swelling, or unstable rails.
6. Record TP3-TP10, supply input current, battery voltage before/after, U2
   temperature if measurable, and D2 charge-indicator behavior. Supply current
   is not the same as battery charge current, and a nearly full cell may not
   enter constant-current charge.
7. Do not leave this first charge unattended. Remove input power first, then the
   battery, before soldering either hand-installed component.

## 3. Solder U1: ESP32-S3-WROOM-1-N16R8

Use the exact N16R8 module: 16 MB flash and 8 MB PSRAM. Do not fit a look-alike
WROOM variant.

1. Read the module label under magnification and photograph proof of the exact
   `N16R8` variant. Handle the module with ESD precautions. Ensure USB and the
   LiPo are absent. Clean the U1 footprint with IPA, let it dry fully, and apply
   a small, even amount of solder paste to the castellated pads and segmented
   centre ground pad. Do not flood the pads.
2. Orient the module using physical landmarks, not the text alone: its antenna
   end must point into the large top-board antenna keep-out, and the module's
   pin-1 mark must align with the U1 footprint's pin-1 triangle at the upper
   left corner below the antenna end.
3. Reflow with hot air using controlled, even heating. The module manufacturer
   specifies one lead-free reflow with a 235--250 degrees C peak for 30--70 s;
   use that as the component limit rather than repeatedly reheating the module.
4. Allow the board to cool naturally. Under magnification, inspect every
   visible castellated joint and check alignment. The hidden centre ground joint
   cannot be visually certified after placement; its confidence comes from
   paste control, a proper thermal process, alignment, and the electrical
   checks. Inspect the antenna keep-out and do not place copper tape, wiring,
   standoffs, the battery, or other metal over the antenna region.
5. With power removed, repeat the resistance checks from TP9 to TP3, TP5, TP6,
   TP7, TP8, and TP10 and compare them with the before-U1 record. Repeat the
   5 V smoke test at 100 mA. If no fault is evident but U1 startup causes
   foldback, raise the ceiling in controlled steps, up to 500 mA for this
   no-peripheral test. Record current at 5 seconds and 60 seconds. Stop if U1 or
   any regulator heats abnormally or any regulated rail collapses.
6. Do not interpret USB enumeration or the behavior of an unflashed module as a
   hardware pass/fail in this phase.

## 4. Solder MK1: ICS-43434 microphone

MK1 is a bottom-port microphone. Its acoustic opening must sit directly above
the board's 0.5 mm MK1 acoustic bore. Keep paste, flux, adhesive, tape, and
cleaning liquid out of that bore; the microphone cannot work through an
obstructed port.

1. Verify the part marking and pin-1 convention against the ICS-43434 package
   drawing. Ensure all power sources are absent. Apply minimal paste to the six
   MK1 pads. Align the microphone's pin-1 mark to the triangular pin-1 marker on
   the footprint. Do not infer orientation from package shape alone.
2. Reflow with low airflow and even heating so the small package is not blown
   sideways. Do not direct the air jet through the acoustic bore or repeatedly
   reheat the microphone.
3. After cooling, inspect all six joints under magnification and confirm that
   the bore remains open from the board underside.
4. With power removed, compare resistance from TP6 to TP9 with the pre-MK1
   record and inspect for bridges between adjacent MK1 pads. Repeat the
   current-limited 5 V smoke test; confirm TP6 remains close to 3.3 V and input
   current has not changed unexpectedly.

## 5. Post-solder mechanical dry fit

After the board is fully cool, cleaned, and unpowered:

1. Reinstall only the temporary standoff/screw stack. Confirm no metal hardware
   can touch pads or traces and the PCB does not bow.
2. Recheck the proposed left-side `2 x 4 mm` mic tube path. Its window must
   eventually align to the 0.5 mm PCB acoustic bore, not merely the MK1 package.
3. Recheck the right-wall `50 x 34 x 10 mm` battery volume with insulation and
   Velcro thickness included. Keep the pouch entirely on the deep-base side of
   the seam and out of the antenna keep-out.
4. Check that the 22 mm button's approximately 31 mm rear keep-out, camera FPC,
   USB-C cable approach, speaker, wiring bends, and light-pipe lines do not
   intersect the PCB or battery.
5. Dry-fit and photograph the stack with the selected `10 mm` standoffs.
   Confirm that they clear the unused molded bosses with tolerance, the mic
   tube is not crushed, the PCB remains flat, and the lid closes without the
   button, camera FPC, wiring, or other front-mounted parts touching the PCB.

Do not epoxy standoffs, apply Velcro, cut rods, or drill the enclosure yet.
Camera, speaker, microphone, button, LED, PIR, and USB flashing tests can still
change the best opening locations. Any holes will also invalidate the stock
enclosure's ingress claim unless they are properly sealed.

## 6. Hardware-only exit criteria

Stop here and begin software bring-up only when all of the following are true:

- The received batch and first-article photographs are recorded.
- The enclosure and received standoff dimensions are measured, and all
  unconfirmed accessories are listed rather than assumed present.
- U1 and MK1 are correctly oriented and cleanly soldered.
- USB-only and battery-only tests have stable TP6, TP7, TP8, and TP10 rails.
- USB plus battery charging was observed briefly and safely.
- No rail is shorted, no component overheats, and the current-limited supply did
  not remain in foldback.
- The MK1 acoustic bore is visibly unobstructed.
- Before/after resistance, voltage, current, and fit measurements are retained.

At this point, leave the camera and other external peripherals disconnected
until the software bring-up procedure begins with USB enumeration and flashing.
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

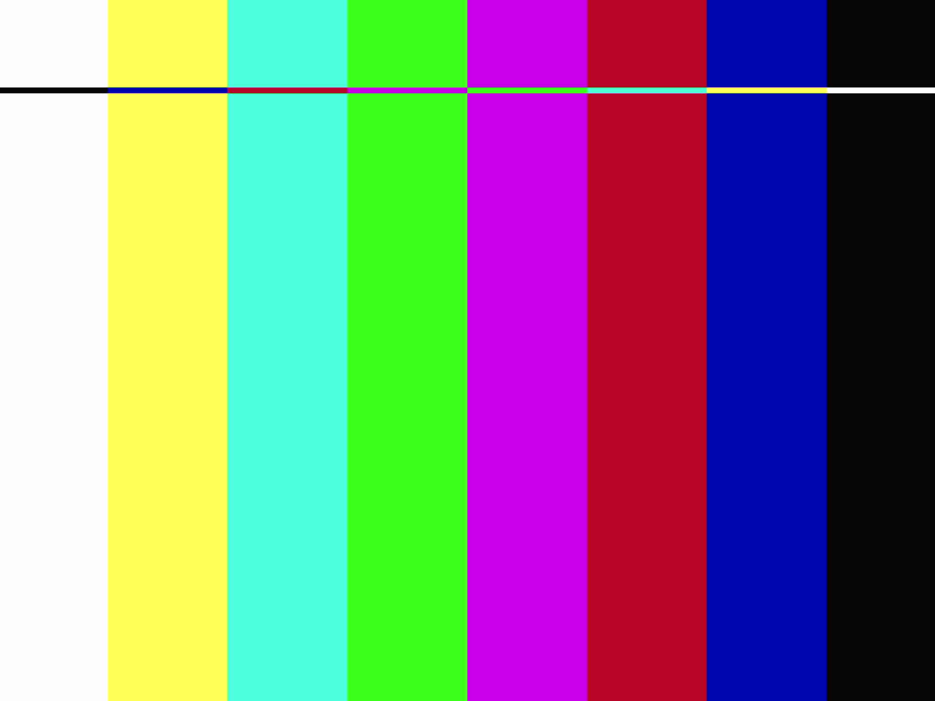
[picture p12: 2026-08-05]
docs/hardware/camera/bringup-captures/qxga-clean-internal-colorbar.jpg

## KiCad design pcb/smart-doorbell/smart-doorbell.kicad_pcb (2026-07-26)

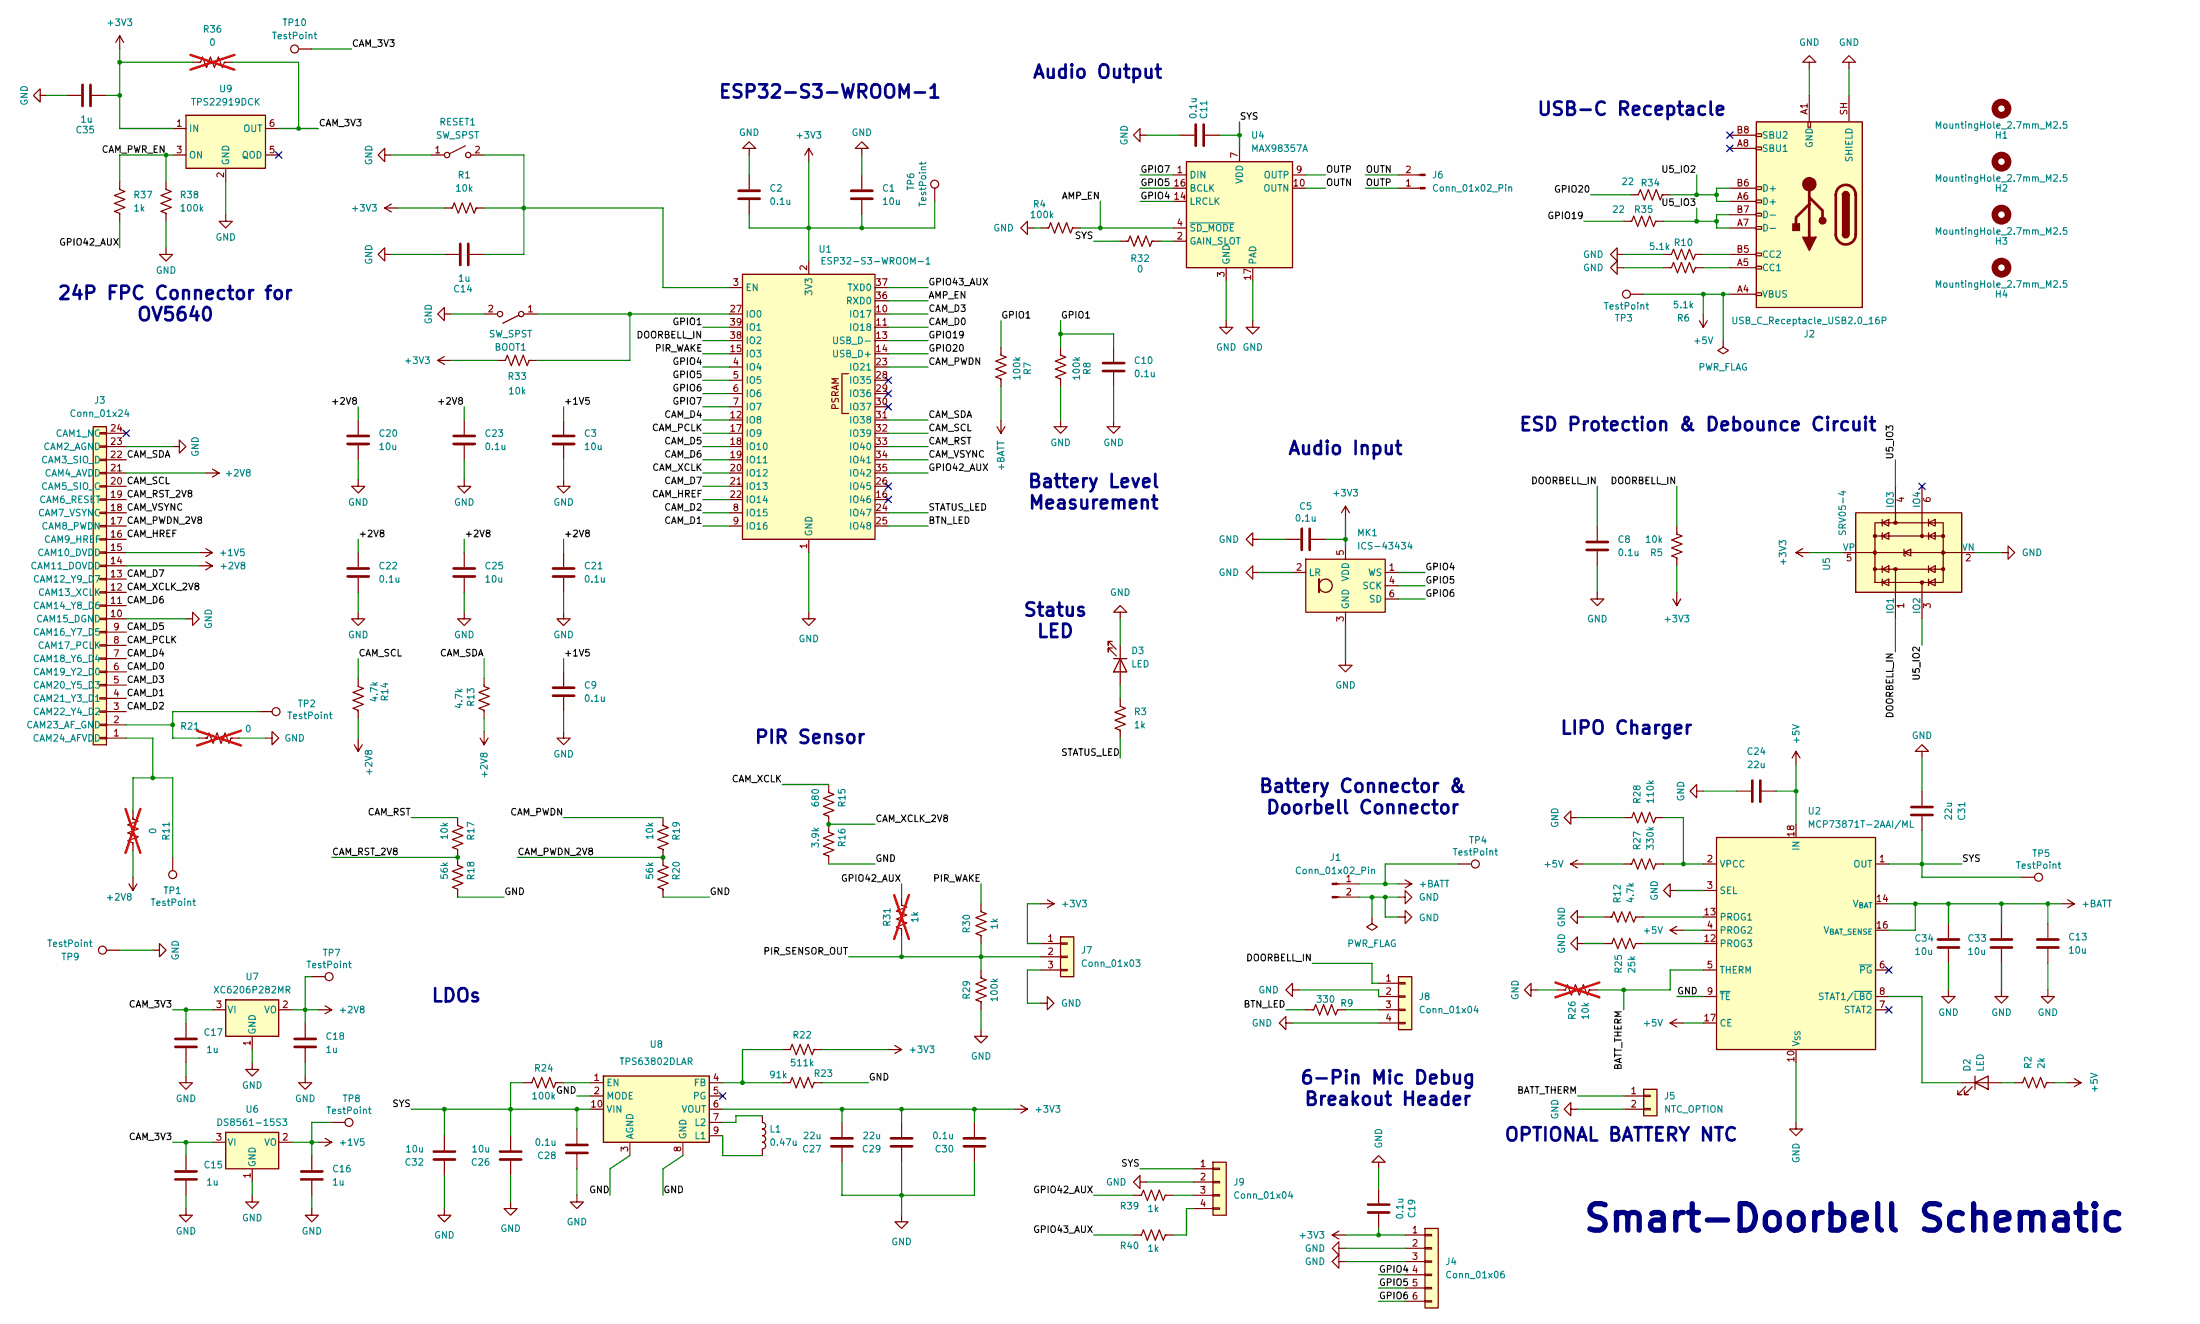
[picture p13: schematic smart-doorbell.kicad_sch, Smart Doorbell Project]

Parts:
BOOT1: SW_SPST; SW_SPST_B3U-1000P; LCSC Part # C231329
C1, C3, C13, C20, C25, C26, C33, C34: 10u; C_0603_1608Metric; LCSC Part # C19702
C2, C5, C8, C9, C10, C11, C19, C21, C22, C23, C28, C30: 0.1u; C_0603_1608Metric
C14, C15, C16, C17, C18, C35: 1u; C_0603_1608Metric
C24, C27, C29, C31: 22u; C_0603_1608Metric; LCSC Part # C84419
C32: 10u; C_0603_1608Metric; LCSC Part # C90053
D2, D3: LED; LED_0603_1608Metric
H1, H2, H3, H4: MountingHole_2.7mm_M2.5
J1, J6: Conn_01x02_Pin; JST_PH_B2B-PH-K_1x02_P2.00mm_Vertical; LCSC Part # C131337
J2: USB_C_Receptacle_USB2.0_16P; USB_C_Receptacle_HRO_TYPE-C-31-M-12; LCSC Part # C165948
J3: Conn_01x24; Hirose_FH12-24S-0.5SH_1x24-1MP_P0.50mm_Horizontal; LCSC Part # C202112
J4: Conn_01x06; PinHeader_1x06_P2.54mm_Vertical; LCSC Part # C37208
J5: NTC_OPTION; SolderWire-0.25sqmm_1x02_P4.2mm_D0.65mm_OD1.7mm
J7: Conn_01x03; JST_PH_B3B-PH-K_1x03_P2.00mm_Vertical; LCSC Part # C131339
J8: Conn_01x04; JST_PH_B4B-PH-K_1x04_P2.00mm_Vertical; LCSC Part # C131334
J9: Conn_01x04; PinHeader_1x04_P2.54mm_Vertical
L1: 0.47u; L_1008_2520Metric; MPN MHCH252010A-R47M-Q8; LCSC Part # C2981231
MK1: ICS-43434; InvenSense_ICS-43434-6_3.5x2.65mm
R1, R5, R17, R19, R33: 10k; R_0603_1608Metric; LCSC Part # C15401
R2: 2k; R_0603_1608Metric
R3, R30, R37, R39, R40: 1k; R_0603_1608Metric; LCSC Part # C21190
R4, R7, R8, R24, R29, R38: 100k; R_0603_1608Metric; LCSC Part # C25803
R6, R10: 5.1k; R_0603_1608Metric
R9: 330; R_0603_1608Metric
R11, R21: 0; R_0603_1608Metric; not fitted
R12, R13, R14: 4.7k; R_0603_1608Metric
R15: 680; R_0603_1608Metric
R16: 3.9k; R_0603_1608Metric
R18, R20: 56k; R_0603_1608Metric
R22: 511k; R_0603_1608Metric
R23: 91k; R_0603_1608Metric; LCSC Part # C23265
R25: 25k; R_0603_1608Metric
R26: 10k; R_0603_1608Metric; LCSC Part # C15401; not fitted
R27: 330k; R_0603_1608Metric
R28: 110k; R_0603_1608Metric
R31: 1k; R_0603_1608Metric; not fitted
R32: 0; R_0603_1608Metric; LCSC Part # C21189
R34, R35: 22; R_0603_1608Metric; LCSC Part # C23345
R36: 0; R_0603_1608Metric; LCSC Part # C21189; not fitted
RESET1: SW_SPST; SW_SPST_B3U-1000P; LCSC Part # C231329
TP1, TP2, TP3, TP4, TP5, TP6, TP7, TP8, TP9, TP10: TestPoint; TestPoint_Pad_D1.0mm
U1: ESP32-S3-WROOM-1
U2: MCP73871T-2AAI/ML; QFN-20-1EP_4x4mm_P0.5mm_EP2.5x2.5mm; MPN MCP73871T-2AAI/ML; LCSC Part # C144351
U4: MAX98357A; MAX98357A_TQFN-16-1EP_3x3mm_P0.5mm_EP1.23x1.23mm
U5: SRV05-4; SOT-23-6
U6: DS8561-15S3; SOT-23-3; MPN DS8561-15S3; LCSC Part # C5795628
U7: XC6206P282MR; SOT-23-3
U8: TPS63802DLAR; TPS63802DLAR_DLA0010A; MPN TPS63802DLAR; LCSC Part # C2845237
U9: TPS22919DCK; SOT-363_SC-70-6; LCSC Part # C2149796

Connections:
+1V5: C3.2, C9.2, C16.1, J3.15 (CAM10_DVDD), TP8.1 (1_1), U6.2 (VO)
+2V8: C18.1, C20.2, C21.2, C22.2, C23.2, C25.2, J3.14 (CAM11_DOVDD), J3.21 (CAM4_AVDD), R11.2, R13.2, R14.2, TP7.1 (1_1), U7.2 (VO)
+3V3: C1.2, C2.2, C5.1, C19.1, C27.1, C29.1, C30.1, C35.2, J4.1, J7.1, MK1.5 (VDD), R1.1, R5.1, R22.2, R33.1, R36.1, TP6.1 (1_1), U1.2 (3V3), U5.5 (VP), U8.6 (VOUT), U9.1 (IN)
+5V: C24.1, J2.A4 (VBUS), J2.A9 (VBUS), J2.B4 (VBUS), J2.B9 (VBUS), R2.2, R27.1, TP3.1 (1_1), U2.4 (PROG2), U2.17 (CE), U2.18 (IN), U2.19 (IN)
+BATT: C13.2, C33.2, C34.2, J1.1, R7.2, TP4.1 (1_1), U2.14 (V_{BAT}), U2.15 (V_{BAT}), U2.16 (V_{BAT_SENSE})
/AMP_EN: R4.2, U1.36 (RXD0), U4.4 (~SD_MODE)
/BATT_THERM: J5.1, R26.2, U2.5 (THERM)
/BTN_LED: R9.1, U1.25 (IO48)
/CAM_3V3: C15.1, C17.1, R36.2, TP10.1 (1_1), U6.3 (VI), U7.3 (VI), U9.6 (OUT)
/CAM_D0: J3.6 (CAM19_Y2_D0), U1.11 (IO18)
/CAM_D1: J3.4 (CAM21_Y3_D1), U1.9 (IO16)
/CAM_D2: J3.3 (CAM22_Y4_D2), U1.8 (IO15)
/CAM_D3: J3.5 (CAM20_Y5_D3), U1.10 (IO17)
/CAM_D4: J3.7 (CAM18_Y6_D4), U1.12 (IO8)
/CAM_D5: J3.9 (CAM16_Y7_D5), U1.18 (IO10)
/CAM_D6: J3.11 (CAM14_Y8_D6), U1.19 (IO11)
/CAM_D7: J3.13 (CAM12_Y9_D7), U1.21 (IO13)
/CAM_HREF: J3.16 (CAM9_HREF), U1.22 (IO14)
/CAM_PCLK: J3.8 (CAM17_PCLK), U1.17 (IO9)
/CAM_PWDN: R19.1, U1.23 (IO21)
/CAM_PWDN_2V8: J3.17 (CAM8_PWDN), R19.2, R20.1
/CAM_PWR_EN: R37.2, R38.2, U9.3 (ON)
/CAM_RST: R17.1, U1.33 (IO40)
/CAM_RST_2V8: J3.19 (CAM6_RESET), R17.2, R18.1
/CAM_SCL: J3.20 (CAM5_SIO_C), R14.1, U1.32 (IO39)
/CAM_SDA: J3.22 (CAM3_SIO_D), R13.1, U1.31 (IO38)
/CAM_VSYNC: J3.18 (CAM7_VSYNC), U1.34 (IO41)
/CAM_XCLK: R15.1, U1.20 (IO12)
/CAM_XCLK_2V8: J3.12 (CAM13_XCLK), R15.2, R16.1
/DOORBELL_IN: C8.1, J8.1, R5.2, U1.38 (IO2), U5.1 (IO1)
/GPIO1: C10.2, R7.1, R8.1, U1.39 (IO1)
/GPIO4: J4.4, MK1.1 (WS), U1.4 (IO4), U4.14 (LRCLK)
/GPIO5: J4.5, MK1.4 (SCK), U1.5 (IO5), U4.16 (BCLK)
/GPIO6: J4.6, MK1.6 (SD), U1.6 (IO6)
/GPIO7: U1.7 (IO7), U4.1 (DIN)
/GPIO19: R35.2, U1.13 (USB_D-)
/GPIO20: R34.2, U1.14 (USB_D+)
/GPIO42_AUX: R31.2, R37.1, R39.1, U1.35 (IO42)
/GPIO43_AUX: R40.1, U1.37 (TXD0)
/OUTN: J6.2, U4.10 (OUTN)
/OUTP: J6.1, U4.9 (OUTP)
/PIR_SENSOR_OUT: J7.2, R29.2, R30.1, R31.1
/PIR_WAKE: R30.2, U1.15 (IO3)
/STATUS_LED: R3.2, U1.24 (IO47)
/SYS: C11.2, C26.1, C28.1, C31.1, C32.1, J9.1, R24.1, R32.2, TP5.1 (1_1), U2.1 (OUT), U2.20 (OUT), U4.7 (VDD), U4.8 (VDD), U8.10 (VIN)
/U5_IO2: J2.A6 (D+), J2.B6 (D+), R34.1, U5.3 (IO2)
/U5_IO3: J2.A7 (D-), J2.B7 (D-), R35.1, U5.4 (IO3)
GND: BOOT1.2 (B), C1.1, C2.1, C3.1, C5.2, C8.2, C9.1, C10.1, C11.1, C13.1, C14.1, C15.2, C16.2, C17.2, C18.2, C19.2, C20.1, C21.1, C22.1, C23.1, C24.2, C25.1, C26.2, C27.2, C28.2, C29.2, C30.2, C31.2, C32.2, C33.1, C34.1, C35.1, D3.1 (K), J1.2, J2.A1 (GND), J2.A12 (GND), J2.B1 (GND), J2.B12 (GND), J2.SH (SHIELD), J3.10 (CAM15_DGND), J3.23 (CAM2_AGND), J4.2, J4.3, J5.2, J7.3, J8.2, J8.4, J9.2, MK1.2 (LR), MK1.3 (GND), R4.1, R6.2, R8.2, R10.2, R12.1, R16.2, R18.2, R20.2, R21.2, R23.2, R25.1, R26.1, R28.1, R29.1, R38.1, RESET1.1 (A), TP9.1 (1_1), U1.1 (GND), U1.40 (GND), U1.41 (GND), U2.3 (SEL), U2.9 (~TE), U2.10 (V_{SS}), U2.11 (V_{SS}), U2.21 (V_{SS}), U4.3 (GND), U4.11 (GND), U4.15 (GND), U4.17 (PAD), U5.2 (VN), U6.1 (GND), U7.1 (GND), U8.2 (MODE), U8.3 (AGND), U8.8 (GND), U9.2 (GND)
unnamed: BOOT1.1 (A), R33.2, U1.27 (IO0)
unnamed: D2.2 (A), R2.1
unnamed: D2.1 (K), U2.8 (STAT1/~LBO)
unnamed: D3.2 (A), R3.1
unnamed: J2.A5 (CC1), R6.1
unnamed: J2.B5 (CC2), R10.1
unnamed: J3.2 (CAM23_AF_GND), R21.1, TP2.1 (1_1)
unnamed: J3.1 (CAM24_AFVDD), R11.1, TP1.1 (1_1)
unnamed: J8.3, R9.2
unnamed: J9.3, R39.2
unnamed: J9.4, R40.2
unnamed: C14.2, R1.2, RESET1.2 (B), U1.3 (EN)
unnamed: R12.2, U2.13 (PROG1)
unnamed: R25.2, U2.12 (PROG3)
unnamed: R27.2, R28.2, U2.2 (VPCC)
unnamed: R32.1, U4.2 (GAIN_SLOT)
unnamed: R24.2, U8.1 (EN)
unnamed: R22.1, R23.1, U8.4 (FB)
unnamed: L1.2, U8.9 (L1)
unnamed: L1.1, U8.7 (L2)

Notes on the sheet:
Battery Level Measurement
LDOs
Audio Input
USB-C Receptacle
Audio Output
ESD Protection & Debounce Circuit
6-Pin Mic Debug Breakout Header
Battery Connector & Doorbell Connector
24P FPC Connector for OV5640
PIR Sensor
OPTIONAL BATTERY NTC
Smart-Doorbell Schematic
LIPO Charger
Status LED
ESP32-S3-WROOM-1

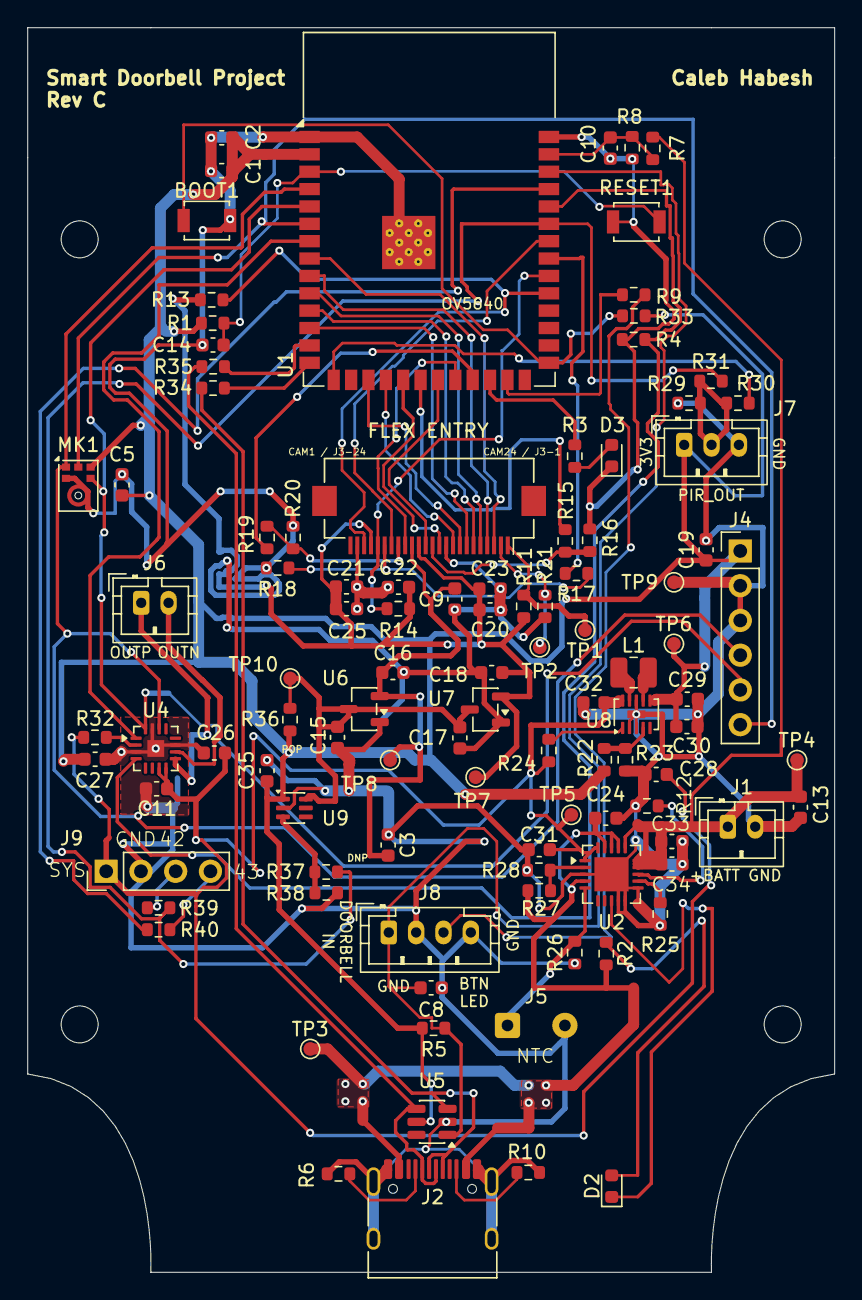
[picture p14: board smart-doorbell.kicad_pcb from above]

Board: 2 copper layers, 59.0 x 91.0 mm, 108 parts (0 on the bottom side), 68 nets.

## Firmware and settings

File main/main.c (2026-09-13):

#include <stdio.h>
#include <stdbool.h>
#include <string.h>
#include "esp_log.h"
#include "freertos/FreeRTOS.h"
#include "freertos/task.h"
#include "freertos/event_groups.h"
#include "esp_sleep.h"
#include "driver/gpio.h"
#include "driver/rtc_io.h"
#include "esp_camera.h"
#include "driver/i2s_std.h"
#include "nvs_flash.h"
#include "esp_wifi.h"
#include "esp_event.h"
#include "mqtt_client.h"
#include "config.h"
#include "esp_http_client.h"
#include "board_pins.h"
#include "camera_power.h"
#include "ov5640_mode_fix.h"
#include "camera_power_gate_bringup.h"
#include "core_bringup.h"
#include "battery_bringup.h"
#include "battery_camera_upload_bringup.h"
#include "camera_bringup.h"
#include "mic_bringup.h"
#include "speaker_bringup.h"
#include "button_bringup.h"
#include "pir_bringup.h"
#include "wifi_bringup.h"

#ifndef SMART_DOORBELL_CORE_BRINGUP
#define SMART_DOORBELL_CORE_BRINGUP 1
#endif

#ifndef SMART_DOORBELL_BATTERY_BRINGUP
#define SMART_DOORBELL_BATTERY_BRINGUP 0
#endif

#ifndef SMART_DOORBELL_BATTERY_CAMERA_UPLOAD_BRINGUP
#define SMART_DOORBELL_BATTERY_CAMERA_UPLOAD_BRINGUP 0
#endif

#ifndef SMART_DOORBELL_CAMERA_ATTACHED_IDLE
#define SMART_DOORBELL_CAMERA_ATTACHED_IDLE 0
#endif

#ifndef SMART_DOORBELL_CAMERA_BRINGUP
#define SMART_DOORBELL_CAMERA_BRINGUP 0
#endif

#ifndef SMART_DOORBELL_CAMERA_POWER_GATE_BRINGUP
#define SMART_DOORBELL_CAMERA_POWER_GATE_BRINGUP 0
#endif

#ifndef SMART_DOORBELL_WIFI_BRINGUP
#define SMART_DOORBELL_WIFI_BRINGUP 0
#endif

#ifndef SMART_DOORBELL_MIC_BRINGUP
#define SMART_DOORBELL_MIC_BRINGUP 0
#endif

#ifndef SMART_DOORBELL_SPEAKER_BRINGUP
#define SMART_DOORBELL_SPEAKER_BRINGUP 0
#endif

#ifndef SMART_DOORBELL_BUTTON_BRINGUP
#define SMART_DOORBELL_BUTTON_BRINGUP 0
#endif

#ifndef SMART_DOORBELL_PIR_BRINGUP
#define SMART_DOORBELL_PIR_BRINGUP 0
#endif

#ifndef SMART_DOORBELL_CAMERA_XCLK_HZ
#define SMART_DOORBELL_CAMERA_XCLK_HZ 10000000
#endif

#ifndef SMART_DOORBELL_CAMERA_MAINS_HZ
#define SMART_DOORBELL_CAMERA_MAINS_HZ 60
#endif

#ifndef SMART_DOORBELL_CAMERA_AUTO_GAIN_CEILING
#define SMART_DOORBELL_CAMERA_AUTO_GAIN_CEILING 0x0020
#endif

static const char *TAG = "smart_doorbell";

static i2s_chan_handle_t rx_chan; // Microphone
static i2s_chan_handle_t tx_chan; // Speaker
static bool s_camera_initialized;

static esp_err_t __attribute__((unused)) init_camera(void)
{
    camera_config_t camera_config = {
        .pin_pwdn = CAM_PIN_PWDN,
        .pin_reset = CAM_PIN_RESET,
        .pin_xclk = CAM_PIN_XCLK,
        .pin_sccb_sda = CAM_PIN_SIOD,
        .pin_sccb_scl = CAM_PIN_SIOC,

        .pin_d7 = CAM_PIN_D7,
        .pin_d6 = CAM_PIN_D6,
        .pin_d5 = CAM_PIN_D5,
        .pin_d4 = CAM_PIN_D4,
        .pin_d3 = CAM_PIN_D3,
        .pin_d2 = CAM_PIN_D2,
        .pin_d1 = CAM_PIN_D1,
        .pin_d0 = CAM_PIN_D0,
        .pin_vsync = CAM_PIN_VSYNC,
        .pin_href = CAM_PIN_HREF,
        .pin_pclk = CAM_PIN_PCLK,

        .xclk_freq_hz = SMART_DOORBELL_CAMERA_XCLK_HZ,
        .ledc_timer = LEDC_TIMER_0,
        .ledc_channel = LEDC_CHANNEL_0,

        .pixel_format = PIXFORMAT_JPEG, // YUV422,GRAYSCALE,RGB565,JPEG
        .frame_size = FRAMESIZE_QXGA,

        .jpeg_quality = 12, // 0-63, lower number means higher quality
        .fb_count = 1,
        .fb_location = CAMERA_FB_IN_PSRAM,
        .grab_mode = CAMERA_GRAB_WHEN_EMPTY,
    };

    esp_err_t err = camera_power_enable();
    if (err != ESP_OK) {
        ESP_LOGE(TAG, "Camera rail enable failed: %s", esp_err_to_name(err));
        camera_power_disable();
        return err;
    }

    // Initialize the camera only after CAM_3V3, +2V8, and +1V5 have settled.
    err = esp_camera_init(&camera_config);
    if (err != ESP_OK) {
        ESP_LOGE(TAG, "Camera Init Failed: %s", esp_err_to_name(err));
        camera_power_disable();
        return err;
    }

    sensor_t *sensor = esp_camera_sensor_get();
    if (!sensor) {
        ESP_LOGE(TAG, "Camera sensor handle unavailable after initialization");
        esp_camera_deinit();
        camera_power_disable();
        return ESP_FAIL;
    }

    int sensor_err = sensor->set_vflip(sensor, 1);
    sensor_err |= sensor->set_hmirror(sensor, 1);
    if (sensor_err != 0) {
        ESP_LOGE(TAG, "Camera orientation setup failed: %d", sensor_err);
        esp_camera_deinit();
        camera_power_disable();
        return ESP_FAIL;
    }

    err = ov5640_apply_full_readout_fix(
        sensor,
        camera_config.frame_size,
        OV5640_FULL_READOUT_BLC_FRAMES,
        false);
    if (err != ESP_OK) {
        ESP_LOGE(TAG, "OV5640 full-readout setup failed: %s",
                 esp_err_to_name(err));
        esp_camera_deinit();
        camera_power_disable();
        return err;
    }

    ov5640_aec_timing_t aec_timing = {0};
    err = ov5640_configure_aec_timing(
        sensor,
        camera_config.xclk_freq_hz,
        SMART_DOORBELL_CAMERA_MAINS_HZ,
        0,
        &aec_timing);
    if (err != ESP_OK) {
        ESP_LOGE(TAG, "OV5640 AEC timing setup failed: %s",
                 esp_err_to_name(err));
        esp_camera_deinit();
        camera_power_disable();
        return err;
    }
    ESP_LOGI(TAG,
             "OV5640 AEC timing: mains=%dHz sysclk=%u HTS=%u VTS=%u "
             "max_exposure=%u B50=%u/%u B60=%u/%u",
             SMART_DOORBELL_CAMERA_MAINS_HZ,
             (unsigned)aec_timing.sysclk_hz,
             (unsigned)aec_timing.hts_lines,
             (unsigned)aec_timing.vts_lines,
             (unsigned)aec_timing.max_exposure_lines,
             (unsigned)aec_timing.band_step_50hz,
             (unsigned)aec_timing.max_bands_50hz,
             (unsigned)aec_timing.band_step_60hz,
             (unsigned)aec_timing.max_bands_60hz);

    err = ov5640_set_auto_gain_ceiling(
        sensor, SMART_DOORBELL_CAMERA_AUTO_GAIN_CEILING);
    if (err != ESP_OK) {
        ESP_LOGE(TAG, "OV5640 automatic gain ceiling setup failed: %s",
                 esp_err_to_name(err));
        esp_camera_deinit();
        camera_power_disable();
        return err;
    }
    ESP_LOGI(TAG, "OV5640 automatic gain ceiling: 0x%03x",
             SMART_DOORBELL_CAMERA_AUTO_GAIN_CEILING);

    if (ov5640_uses_full_readout(camera_config.frame_size)) {
        for (int i = 0; i < OV5640_FULL_READOUT_BLC_FRAMES; ++i) {
            camera_fb_t *settling_fb = esp_camera_fb_get();
            if (!settling_fb) {
                ESP_LOGE(TAG, "OV5640 BLC settling frame %d/%d failed",
                         i + 1, OV5640_FULL_READOUT_BLC_FRAMES);
                esp_camera_deinit();
                camera_power_disable();
                return ESP_FAIL;
            }
            esp_camera_fb_return(settling_fb);
        }
        ESP_LOGI(TAG, "OV5640 full-readout/BLC fix settled over %d frames",
                 OV5640_FULL_READOUT_BLC_FRAMES);

        err = ov5640_finish_blc_recalibration(sensor);
        if (err != ESP_OK) {
            ESP_LOGE(TAG, "OV5640 BLC recalibration finish failed: %s",
                     esp_err_to_name(err));
            esp_camera_deinit();
            camera_power_disable();
            return err;
        }
    }

    s_camera_initialized = true;
    ESP_LOGI(TAG, "Camera Init Succeeded");
    return ESP_OK;
}

static void shutdown_camera(void)
{
    if (s_camera_initialized) {
        esp_camera_deinit();
        s_camera_initialized = false;
    }

    esp_err_t err = camera_power_disable();
    if (err != ESP_OK) {
        ESP_LOGE(TAG, "Camera rail shutdown failed: %s", esp_err_to_name(err));
    }
}

static esp_err_t init_i2s(void)
{
    gpio_reset_pin(AMP_EN_PIN);
    gpio_set_direction(AMP_EN_PIN, GPIO_MODE_OUTPUT);
    gpio_set_level(AMP_EN_PIN, 1);

    // 1. Allocate I2S channels
    i2s_chan_config_t chan_cfg = I2S_CHANNEL_DEFAULT_CONFIG(I2S_NUM_AUTO, I2S_ROLE_MASTER);
    esp_err_t err = i2s_new_channel(&chan_cfg, &tx_chan, &rx_chan);
    if (err != ESP_OK) {
        ESP_LOGE(TAG, "Failed to create I2S channels: %s", esp_err_to_name(err));
        return err;
    }

    // 2. Configure standard I2S for Speaker (TX)
    i2s_std_config_t tx_std_cfg = {
        .clk_cfg  = I2S_STD_CLK_DEFAULT_CONFIG(16000), // 16 kHz sample rate
        .slot_cfg = I2S_STD_PHILIPS_SLOT_DEFAULT_CONFIG(I2S_DATA_BIT_WIDTH_16BIT, I2S_SLOT_MODE_MONO),
        .gpio_cfg = {
            .mclk = I2S_GPIO_UNUSED,
            .bclk = I2S_AUDIO_SCK,
            .ws   = I2S_AUDIO_WS,
            .dout = I2S_SPK_SD,
            .din  = I2S_GPIO_UNUSED,
            .invert_flags = {
                .mclk_inv = false,
                .bclk_inv = false,
                .ws_inv   = false,
            },
        },
    };
    err = i2s_channel_init_std_mode(tx_chan, &tx_std_cfg);
    if (err != ESP_OK) {
        ESP_LOGE(TAG, "Failed to initialize I2S TX channel: %s", esp_err_to_name(err));
        return err;
    }

    // 3. Configure standard I2S for Microphone (RX)
    i2s_std_config_t rx_std_cfg = {
        .clk_cfg  = I2S_STD_CLK_DEFAULT_CONFIG(16000), // 16 kHz sample rate
        .slot_cfg = I2S_STD_PHILIPS_SLOT_DEFAULT_CONFIG(I2S_DATA_BIT_WIDTH_16BIT, I2S_SLOT_MODE_MONO),
        .gpio_cfg = {
            .mclk = I2S_GPIO_UNUSED,
            .bclk = I2S_AUDIO_SCK,
            .ws   = I2S_AUDIO_WS,
            .dout = I2S_GPIO_UNUSED,
            .din  = I2S_MIC_SD,
            .invert_flags = {
                .mclk_inv = false,
                .bclk_inv = false,
                .ws_inv   = false,
            },
        },
    };
    err = i2s_channel_init_std_mode(rx_chan, &rx_std_cfg);
    if (err != ESP_OK) {
        ESP_LOGE(TAG, "Failed to initialize I2S RX channel: %s", esp_err_to_name(err));
        return err;
    }

    // 4. Enable both channels
    i2s_channel_enable(tx_chan);
    i2s_channel_enable(rx_chan);

    ESP_LOGI(TAG, "I2S Init Succeeded (TX/RX at 16kHz)");
    return ESP_OK;
}

#define WIFI_CONNECTED_BIT BIT0

static EventGroupHandle_t s_wifi_event_group;
static int s_retry_num = 0;
#ifndef WIFI_MAX_RETRY
#define WIFI_MAX_RETRY 5
#endif

static void wifi_event_handler(void* arg, esp_event_base_t event_base,
                                int32_t event_id, void* event_data)
{
    if (event_base == WIFI_EVENT && event_id == WIFI_EVENT_STA_START) {
        esp_wifi_connect();
    } else if (event_base == WIFI_EVENT && event_id == WIFI_EVENT_STA_DISCONNECTED) {
        if (s_retry_num < WIFI_MAX_RETRY) {
            esp_wifi_connect();
            s_retry_num++;
            ESP_LOGI(TAG, "retry to connect to the AP (%d/%d)", s_retry_num, WIFI_MAX_RETRY);
        } else {
            xEventGroupSetBits(s_wifi_event_group, WIFI_CONNECTED_BIT); // Give up and let the main task handle it
            ESP_LOGE(TAG, "Failed to connect to WiFi after %d retries", WIFI_MAX_RETRY);
        }
    } else if (event_base == IP_EVENT && event_id == IP_EVENT_STA_GOT_IP) {
        ip_event_got_ip_t* event = (ip_event_got_ip_t*) event_data;
        ESP_LOGI(TAG, "got ip:" IPSTR, IP2STR(&event->ip_info.ip));
        s_retry_num = 0;
        xEventGroupSetBits(s_wifi_event_group, WIFI_CONNECTED_BIT);
    }
}

static esp_err_t init_wifi(void)
{
    s_retry_num = 0;
    s_wifi_event_group = xEventGroupCreate();

    ESP_ERROR_CHECK(esp_netif_init());
    ESP_ERROR_CHECK(esp_event_loop_create_default());
    esp_netif_create_default_wifi_sta();

    wifi_init_config_t cfg = WIFI_INIT_CONFIG_DEFAULT();
    ESP_ERROR_CHECK(esp_wifi_init(&cfg));

    esp_event_handler_instance_t instance_any_id;
    esp_event_handler_instance_t instance_got_ip;
    ESP_ERROR_CHECK(esp_event_handler_instance_register(WIFI_EVENT,
                                                         ESP_EVENT_ANY_ID,
                                                         &wifi_event_handler,
                                                         NULL,
                                                         &instance_any_id));
    ESP_ERROR_CHECK(esp_event_handler_instance_register(IP_EVENT,
                                                         IP_EVENT_STA_GOT_IP,
                                                         &wifi_event_handler,
                                                         NULL,
                                                         &instance_got_ip));

    wifi_config_t wifi_config = {
        .sta = {
            .ssid = WIFI_SSID,
            .password = WIFI_PASSWORD,
            .threshold.authmode = WIFI_AUTH_WPA2_PSK,
        },
    };
    ESP_ERROR_CHECK(esp_wifi_set_mode(WIFI_MODE_STA));
    ESP_ERROR_CHECK(esp_wifi_set_config(WIFI_IF_STA, &wifi_config));
    ESP_ERROR_CHECK(esp_wifi_start());

    ESP_LOGI(TAG, "wifi_init_sta finished. Waiting for connection...");

    // Wait until connection is established or timeout (15 seconds)
    EventBits_t bits = xEventGroupWaitBits(s_wifi_event_group, WIFI_CONNECTED_BIT, pdFALSE, pdFALSE, pdMS_TO_TICKS(15000));
    
    if (bits & WIFI_CONNECTED_BIT) {
        if (s_retry_num >= WIFI_MAX_RETRY) {
            return ESP_FAIL;
        }
        return ESP_OK;
    } else {
        ESP_LOGE(TAG, "WiFi connection timeout");
        return ESP_ERR_TIMEOUT;
    }
}

static void mqtt_event_handler(void *handler_args, esp_event_base_t base, int32_t event_id, void *event_data)
{
    esp_mqtt_event_handle_t event = event_data;
    switch ((esp_mqtt_event_id_t)event_id) {
    case MQTT_EVENT_CONNECTED:
        ESP_LOGI(TAG, "MQTT_EVENT_CONNECTED");
        // Subscribe to PTT audio topic
        esp_mqtt_client_subscribe(event->client, "doorbell/commands/audio", 1);
        break;
    case MQTT_EVENT_DISCONNECTED:
        ESP_LOGI(TAG, "MQTT_EVENT_DISCONNECTED");
        break;
    case MQTT_EVENT_DATA:
        if (strncmp(event->topic, "doorbell/commands/audio", event->topic_len) == 0) {
            ESP_LOGI(TAG, "Received PTT audio data: %d bytes", event->data_len);
            // In a real implementation, we would write this to the I2S tx_chan
            // i2s_channel_write(tx_chan, event->data, event->data_len, &bytes_written, portMAX_DELAY);
        }
        break;
    default:
        break;
    }
}

static esp_mqtt_client_handle_t init_mqtt(void)
{
    esp_mqtt_client_config_t mqtt_cfg = {
        .broker.address.uri = MQTT_BROKER_URI,
    };

    esp_mqtt_client_handle_t client = esp_mqtt_client_init(&mqtt_cfg);
    esp_mqtt_client_register_event(client, ESP_EVENT_ANY_ID, mqtt_event_handler, NULL);
    esp_mqtt_client_start(client);
    ESP_LOGI(TAG, "MQTT Init Succeeded");
    return client;
}
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
void app_main(void)
{
#if SMART_DOORBELL_CORE_BRINGUP
    run_core_bringup(SMART_DOORBELL_CAMERA_ATTACHED_IDLE);
    return;
#elif SMART_DOORBELL_BATTERY_BRINGUP
    run_battery_bringup();
    return;
#elif SMART_DOORBELL_BATTERY_CAMERA_UPLOAD_BRINGUP
    run_battery_camera_upload_bringup();
    return;
#elif SMART_DOORBELL_CAMERA_POWER_GATE_BRINGUP
    run_camera_power_gate_bringup();
    return;
#elif SMART_DOORBELL_CAMERA_BRINGUP
    run_camera_bringup();
    return;
#elif SMART_DOORBELL_WIFI_BRINGUP
    run_wifi_bringup();
    return;
#elif SMART_DOORBELL_MIC_BRINGUP
    run_mic_bringup();
    return;
#elif SMART_DOORBELL_SPEAKER_BRINGUP
    run_speaker_bringup();
    return;
#elif SMART_DOORBELL_BUTTON_BRINGUP
    run_button_bringup();
    return;
#elif SMART_DOORBELL_PIR_BRINGUP
    run_pir_bringup();
    return;
#endif

    // Initialize NVS (Required for WiFi)
    esp_err_t ret = nvs_flash_init();
    if (ret == ESP_ERR_NVS_NO_FREE_PAGES || ret == ESP_ERR_NVS_NEW_VERSION_FOUND) {
      ESP_ERROR_CHECK(nvs_flash_erase());
      ret = nvs_flash_init();
    }
    ESP_ERROR_CHECK(ret);

    ESP_LOGI(TAG, "Initializing Smart Doorbell System");

#if BRINGUP_TEST_MODE
    run_bringup_tests();
#endif

    // 1. Determine wakeup cause
#pragma GCC diagnostic push
#pragma GCC diagnostic ignored "-Wdeprecated-declarations"
    esp_sleep_wakeup_cause_t wakeup_cause = esp_sleep_get_wakeup_cause();
#pragma GCC diagnostic pop

    // For testing without the button, run on normal boot or EXT0
    if (wakeup_cause == ESP_SLEEP_WAKEUP_EXT0 || wakeup_cause == ESP_SLEEP_WAKEUP_UNDEFINED) {
        ESP_LOGI(TAG, "Woke up from deep sleep (or normal boot). Starting network flow.");
        
        // 2. Initialize Hardware Peripherals
        esp_err_t camera_err = init_camera();
        init_i2s();
        
        // 3. Capture Photo
        ESP_LOGI(TAG, "Capturing real-time JPEG...");
        camera_fb_t *fb = camera_err == ESP_OK ? esp_camera_fb_get() : NULL;
        if (!fb) {
            ESP_LOGE(TAG, "Camera capture failed");
            // Fallback to empty if needed, but here we just continue
        }

        // 4. Record Audio (5 seconds)
        ESP_LOGI(TAG, "Recording audio for %d seconds...", AUDIO_RECORD_TIME_SEC);
        size_t audio_samples = 16000 * AUDIO_RECORD_TIME_SEC;
        int16_t *audio_buf = malloc(audio_samples * sizeof(int16_t));
        size_t bytes_read = 0;
        if (audio_buf) {
            i2s_channel_read(rx_chan, audio_buf, audio_samples * sizeof(int16_t), &bytes_read, pdMS_TO_TICKS(AUDIO_RECORD_TIME_SEC * 1000 + 500));
            ESP_LOGI(TAG, "Recorded %zu bytes of audio", bytes_read);
        }

        // 5. Initialize WiFi Station
        if (init_wifi() == ESP_OK) {
            // 6. Upload Event
            if (fb) {
                ESP_LOGI(TAG, "Uploading event (Image: %zu bytes, Audio: %zu bytes)...", fb->len, bytes_read);
                upload_event_to_gateway(fb->buf, fb->len, audio_buf, bytes_read);
                esp_camera_fb_return(fb);
            } else {
                ESP_LOGW(TAG, "Skipping upload due to camera failure");
            }
        } else {
            ESP_LOGE(TAG, "Skipping upload due to WiFi failure");
            if (fb) esp_camera_fb_return(fb);
        }
        
        if (audio_buf) free(audio_buf);

        // Camera rails are not needed during the audio-only interactive window.
        shutdown_camera();

        // 7. Connect to MQTT Broker for Interactive Window
        esp_mqtt_client_handle_t mqtt_client = init_mqtt();

        // 8. Interactive Window (60 seconds)
        ESP_LOGI(TAG, "Entering 60-second interactive window...");
        gpio_set_level(STATUS_LED_PIN, 1); 

        for (int i = 60; i > 0; i--) {
            if (i % 10 == 0) {
                ESP_LOGI(TAG, "Interactive window: %d seconds remaining", i);
            }
            vTaskDelay(pdMS_TO_TICKS(1000));
        }

        ESP_LOGI(TAG, "Interactive window expired.");
        esp_mqtt_client_stop(mqtt_client);
        esp_mqtt_client_destroy(mqtt_client);
        gpio_set_level(STATUS_LED_PIN, 0);

    } else {
        ESP_LOGI(TAG, "Woke up from reset (cause: %d). Going to sleep immediately.", wakeup_cause);
    }

    ESP_LOGI(TAG, "Preparing to enter deep sleep...");
    gpio_set_level(AMP_EN_PIN, 0);
    shutdown_camera();

    // 4. Configure wakeup source
    // Enable pullup on the button pin so it defaults to HIGH
    rtc_gpio_pullup_en(DOORBELL_BUTTON_PIN);
    rtc_gpio_pulldown_dis(DOORBELL_BUTTON_PIN);
    
    // Configure EXT0 wakeup on LOW level (0) for the button press
    esp_sleep_enable_ext0_wakeup(DOORBELL_BUTTON_PIN, 0);

    ESP_LOGI(TAG, "Entering deep sleep now");
    
    // 5. Enter Deep Sleep
    esp_deep_sleep_start();
}

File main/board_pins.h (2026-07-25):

#pragma once

#include "driver/gpio.h"

/*
 * Board pin map generated from pcb/smart-doorbell/smart-doorbell.net.
 * The ESP32-S3 GPIO matrix makes many peripherals remappable, but after PCB
 * fabrication these constants must match the routed nets.
 */

// Wake/button and indicators
#define DOORBELL_BUTTON_PIN GPIO_NUM_2   // /DOORBELL_IN
#define BATTERY_ADC_PIN     GPIO_NUM_1   // /GPIO1, 100k/100k divider
#define PIR_WAKE_PIN        GPIO_NUM_3   // /PIR_WAKE, J7.2 through populated R30
#define PIR_OUT_PIN         PIR_WAKE_PIN // Compatibility alias for existing firmware
#define STATUS_LED_PIN      GPIO_NUM_47  // /STATUS_LED
#define BUTTON_LED_PIN      GPIO_NUM_48  // /BTN_LED

// MAX98357A amplifier control
#define AMP_EN_PIN          GPIO_NUM_44  // /AMP_EN -> MAX98357A SD_MODE

// OV5640 camera on 24-pin FPC J3
#define CAM_PWR_EN_PIN      GPIO_NUM_42  // /GPIO42_AUX -> R37 -> /CAM_PWR_EN (Rev C)
#define CAM_PIN_D0          18           // /CAM_D0
#define CAM_PIN_D1          16           // /CAM_D1
#define CAM_PIN_D2          15           // /CAM_D2
#define CAM_PIN_D3          17           // /CAM_D3
#define CAM_PIN_D4          8            // /CAM_D4
#define CAM_PIN_D5          10           // /CAM_D5
#define CAM_PIN_D6          11           // /CAM_D6
#define CAM_PIN_D7          13           // /CAM_D7
#define CAM_PIN_PCLK        9            // /CAM_PCLK
#define CAM_PIN_XCLK        12           // /CAM_XCLK
#define CAM_PIN_HREF        14           // /CAM_HREF
#define CAM_PIN_PWDN        21           // /CAM_PWDN
#define CAM_PIN_SIOD        38           // /CAM_SDA
#define CAM_PIN_SIOC        39           // /CAM_SCL
#define CAM_PIN_RESET       40           // /CAM_RST
#define CAM_PIN_VSYNC       41           // /CAM_VSYNC

/*
 * Rev C populates R37 and leaves R31 DNP, dedicating GPIO42 to camera power.
 * Do not enable the GPIO42 PIR fallback while R37 is populated.
 */

// I2S audio
#define I2S_AUDIO_WS        GPIO_NUM_4   // /GPIO4 -> ICS WS, MAX LRCLK
#define I2S_AUDIO_SCK       GPIO_NUM_5   // /GPIO5 -> ICS SCK, MAX BCLK
#define I2S_MIC_SD          GPIO_NUM_6   // /GPIO6 -> ICS SD
#define I2S_SPK_SD          GPIO_NUM_7   // /GPIO7 -> MAX DIN

// Native USB. Reserved for USB only.
#define USB_D_MINUS_PIN     GPIO_NUM_19
#define USB_D_PLUS_PIN      GPIO_NUM_20

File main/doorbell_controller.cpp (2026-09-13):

#include "doorbell_controller.hpp"

#include <cstdio>
#include <cstring>
#include <inttypes.h>
#include <new>

#include "board_pins.h"
#include "battery_monitor.h"
#include "driver/gpio.h"
#include "esp_app_desc.h"
#include "esp_log.h"
#include "esp_random.h"
#include "esp_system.h"
#include "esp_timer.h"
#include "freertos/FreeRTOS.h"
#include "freertos/semphr.h"
#include "freertos/task.h"
#include "chime_player.h"
#include "ring_fade.h"
#include "wake_stub.h"

namespace doorbell {
namespace {
constexpr const char *kTag = "DoorbellController";
constexpr unsigned kCaptureAttempts = 2;
constexpr unsigned kTriggerAttempts = 2;
constexpr unsigned kUploadAttempts = 2;
constexpr std::uint32_t kRingFadeInMs = 1800;
constexpr std::uint32_t kRingHoldMs = 2500;
constexpr std::uint32_t kRingFadeOutMs = 1800;
constexpr std::uint32_t kVisitorRecordingMaxMs =
    DoorbellPolicy::kVisitorRecordingMaxMs;
constexpr std::uint32_t kVisitorHoldMinimumMs =
    DoorbellPolicy::kVisitorHoldMinimumMs;
constexpr std::uint32_t kRepressChimeHoldHandoffMs =
    DoorbellPolicy::kRepressChimeHoldHandoffMs;
constexpr std::uint32_t kChimeDrainBeforeSleepMs = 4000;
constexpr std::int64_t kGreetingTaskHardLimitUs = 35000000LL;
constexpr std::uint32_t kGreetingStopGraceMs = 750;
portMUX_TYPE s_button_turn_lock = portMUX_INITIALIZER_UNLOCKED;

class CameraSpeakerPowerBoundary final {
public:
    CameraSpeakerPowerBoundary()
    {
        chime_player_set_camera_overlap_mode(true);
    }

    ~CameraSpeakerPowerBoundary()
    {
        release();
    }

    void release()
    {
        if (active_) {
            chime_player_set_camera_overlap_mode(false);
            active_ = false;
        }
    }

    CameraSpeakerPowerBoundary(const CameraSpeakerPowerBoundary &) = delete;
    CameraSpeakerPowerBoundary &operator=(const CameraSpeakerPowerBoundary &) = delete;

private:
    bool active_{true};
};

#ifdef CONFIG_SMART_DOORBELL_ENABLE_PIR_EVENTS
constexpr bool kPirEventsEnabled = true;
#else
constexpr bool kPirEventsEnabled = false;
#endif

#ifndef DEVICE_ID
#define DEVICE_ID "smart-doorbell"
#endif

const char *state_name(DeviceState state)
{
    switch (state) {
    case DeviceState::Booting:
        return "BOOTING";
    case DeviceState::EarlyNotify:
        return "EARLY_NOTIFY";
    case DeviceState::RfQuiesce:
        return "RF_QUIESCE";
    case DeviceState::CameraPowerUp:
        return "CAMERA_POWER_UP";
    case DeviceState::Capturing:
        return "CAPTURING";
    case DeviceState::CameraPowerDown:
        return "CAMERA_POWER_DOWN";
    case DeviceState::RecordingVisitor:
        return "RECORDING_VISITOR";
    case DeviceState::WifiReconnect:
        return "WIFI_RECONNECT";
    case DeviceState::Uploading:
        return "UPLOADING";
    case DeviceState::ListeningForReply:
        return "LISTENING_FOR_REPLY";
    case DeviceState::ReplyArmed:
        return "REPLY_ARMED";
    case DeviceState::PlayingReply:
        return "PLAYING_REPLY";
    case DeviceState::PreparingSleep:
        return "PREPARING_SLEEP";
    case DeviceState::WaitingForRelease:
        return "WAITING_FOR_RELEASE";
    }
    return "UNKNOWN";
}

void make_event_id(char (&event_id)[33])
{
    std::snprintf(event_id, sizeof(event_id),
                  "%08" PRIx32 "%08" PRIx32 "%08" PRIx32 "%08" PRIx32,
                  esp_random(), esp_random(), esp_random(), esp_random());
}

void log_elapsed(const char *stage, std::int64_t started_us)
{
    ESP_LOGI(kTag, "Latency %s: %.1f ms since controller start", stage,
             static_cast<double>(esp_timer_get_time() - started_us) / 1000.0);
}

int remaining_deadline_ms(std::int64_t deadline_us)
{
    const std::int64_t remaining_us = deadline_us - esp_timer_get_time();
    if (remaining_us <= 0) return 0;
    return static_cast<int>((remaining_us + 999LL) / 1000LL);
}

bool delay_with_deadline(std::uint32_t delay_ms, std::int64_t deadline_us)
{
    if (remaining_deadline_ms(deadline_us) <=
        static_cast<int>(delay_ms)) {
        return false;
    }
    vTaskDelay(pdMS_TO_TICKS(delay_ms));
    return esp_timer_get_time() < deadline_us;
}

struct GreetingCaptureTaskContext {
    AudioService *audio_service;
    RecordedAudio *greeting;
    SemaphoreHandle_t completion;
    std::uint32_t duration_ms;
    std::uint32_t recorded_duration_ms;
    std::int64_t session_start_us;
    std::int64_t absolute_deadline_us;
    std::atomic_bool *capture_window_active;
    esp_err_t result{ESP_FAIL};
};

void record_greeting_task(void *arg)
{
    auto *context = static_cast<GreetingCaptureTaskContext *>(arg);

    // The first chime owns I2S until its final sample. A visitor who wants to
    // leave a message keeps holding; the microphone starts immediately after.
    while (chime_player_is_playing() &&
           esp_timer_get_time() < context->absolute_deadline_us) {
        vTaskDelay(pdMS_TO_TICKS(20));
    }

    const std::int64_t remaining_us =
        context->absolute_deadline_us - esp_timer_get_time();
    if (remaining_us <=
        static_cast<std::int64_t>(kVisitorHoldMinimumMs) * 1000LL) {
        context->result = ESP_ERR_TIMEOUT;
        context->capture_window_active->store(false);
        xSemaphoreGive(context->completion);
        vTaskDelete(nullptr);
        return;
    }
    const std::uint32_t capture_duration_ms =
        static_cast<std::uint32_t>((std::min)(
            static_cast<std::int64_t>(context->duration_ms),
            remaining_us / 1000LL));

    ESP_LOGI(kTag,
             "[MONOTONIC_TIMING] t=%.1f ms | STAGE_START: Visitor microphone recording",
             static_cast<double>(esp_timer_get_time() - context->session_start_us) /
                 1000.0);
    (void)ring_animation_start(100, capture_duration_ms, 150);
    context->result = context->audio_service->record_button_hold(
        *context->greeting, capture_duration_ms, kVisitorHoldMinimumMs,
        context->recorded_duration_ms, context->absolute_deadline_us);
    ring_fade_stop();
    context->capture_window_active->store(false);
    xSemaphoreGive(context->completion);
    vTaskDelete(nullptr);
}

struct FollowupTurn {
    AudioService *audio_service;
    ConnectivityManager *connectivity;
    DoorbellController *controller;
    std::atomic_bool *capture_window_active;
    std::atomic_bool *shutting_down;
    std::atomic_bool *alert_request_in_flight;
    std::atomic_uint32_t *alert_tasks_active;
    std::atomic_uint32_t *latest_press_number;
    const char *session_id;
    const char *firmware_version;
    std::uint32_t press_number;
    std::int64_t press_started_us;
    std::atomic_bool edge_alert_finished{false};
    esp_err_t edge_alert_result{ESP_FAIL};
    std::uint32_t recorded_duration_ms{0};
    std::uint32_t max_duration_ms{0};
    RecordedAudio recording;
    esp_err_t result{ESP_FAIL};
};
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

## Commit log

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2026-05-01 feat(firmware): implement deep sleep, custom partitioning, and camera init
    - Added sdkconfig.defaults to target esp32s3, enable PSRAM, and set FreeRTOS tick rate to 1000Hz
    - Created custom partitions.csv to allocate 3MB to the app partition
    - Added espressif/esp32-camera dependency in idf_component.yml
    - Replaced main loop with deep sleep and EXT0 wakeup on button press
    - Implemented OV5640 camera initialization and placeholder logic for image capture
    [partitions.csv]
2026-05-01 feat(firmware): implement I2S audio initialization
    - Added driver/i2s_std.h include
    - Defined I2S pins for INMP441 mic and MAX98357A speaker
    - Created init_i2s() to configure 16kHz 16-bit Mono channels
    - Integrated audio initialization into app_main
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2026-05-03 fix: timezone offset bug and wrap filteredEvents in useMemo
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2026-05-05 fix: update Speaker DIN pin to GPIO 42 (22 is not exposed on DevKitC)
    [main.c]
2026-05-13 feat: integrate custom PCB design and architecture updates
    - Add KiCad project files, gerbers, and production files for the custom PCB
    - Update .gitignore to exclude KiCad backups, temp scripts, and superpower states
    - Update README.md and GEMINI.md to reflect the shift to the ESP32-S3-WROOM-1-N16R8, including its specific trace-optimized camera and audio pinout mappings
    - Add development plans and updated gateway wrapper/lock files
    - Minor firmware UI/settings tweaks to support updated component mappings
    [HRO TYPE-C-31-M-12.step, bom.csv, designators.csv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]
2026-05-15 chore: execute hardware bring-up prep checklist
    - update sdkconfig for N16R8 target
    - create hardware bring-up and pcb README docs
    - clean main README claims
    - add bring-up test modes to firmware
    - fix maven tests for Java 21 dynamic agents
    - implement secure media proxy endpoint
    - explicitly label mocked UI components
    [board_pins.h, main.c]
2026-05-16 build: remove devtools to fix classloader crash on ARM/Java21
2026-05-16 docs: sync project state, correct pinouts, and document workflow
    This commit saves the documentation and configuration cleanups performed by the subagent, ensuring the README, bring-up checklist, and deployment docs accurately reflect the current Arch/Pi workflow and hardware reality.
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2026-05-16 feat: implement 60s interactive window and MQTT audio streaming in firmware
    Updates backend notification URL to public domain and adds the interactive state machine to the ESP32-S3 firmware.
2026-05-16 style(dashboard): add smooth fade-in transition and loading state for event images
    This prevents the black flicker when loading larger JPEG payloads from the doorbell camera by displaying a loading spinner and applying a CSS blur/opacity transition once the Next.js Image component finishes loading.
2026-05-18 feat(dashboard): add responsive event preview drawer to event log
    Clicking the action button in the Event Log now opens a slide-over preview showing the full image, metadata, and an audio player if audio was recorded for that event.
2026-05-18 fix(dashboard): restore missing onNavigate prop definition in Sidebar component
2026-05-18 feat(dashboard): enhance calendar view with date jumper and preview drawer
    Fixes the Event Log wrapper flicker by deferring the animate-flash-event class until loading completes. Adds an HTML month input to the Calendar header to quickly jump dates, and upgrades the Calendar's side panel events into clickable buttons that open the Event Preview Drawer.
2026-05-18 style(dashboard): fix layout clipping and mobile header spacing
    Adds overflow-hidden to MainLayout to prevent the grid background from bleeding out of the rounded corner. Adjusts the flex wrapping and padding on the mobile headers in Event Log and Calendar views so the search bar and date selectors stack cleanly instead of smushing. Re-aligns the toggle switch in Settings.
2026-05-18 style(dashboard): finalize mobile header branding and fix dropdown alignment
    Uses the correct speaker logo in the mobile header, expands the mobile status indicator with full text, fixes the toggle switch alignment in Settings, and corrects lopsided dropdown arrows by using custom icons and width constraints.
2026-05-18 style(dashboard): finalize UI branding and alignment fixes
    Cleans up Sidebar.tsx JSX structure, fixes toggle switch alignment in Settings, and implements custom dropdown arrows for better visual balance.
2026-05-19 style(dashboard): revert toggle switch and fix lopsided date arrows
2026-05-19 style(dashboard): improve mobile UI for date pickers and toggle switch
    Overhauls the date pickers in Event Log and Calendar views to be more prominent and clearly labeled with icons. Standardizes the toggle switch in Settings for a better mobile look and feel.
2026-05-19 style(dashboard): move date picker arrows further left for better alignment
    Increases the right margin on the native calendar indicator and increases input padding-right to ensure the dropdown arrow sits in a more balanced position on mobile devices.
2026-05-19 style(dashboard): refine scrollbar and custom date picker arrows
    Darkens the recent log scrollbar track to match the site theme. Replaces the native browser date picker arrow with a custom Lucide ChevronDown icon to ensure perfect alignment across all mobile browsers.
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2026-05-23 fix(dashboard): resolve mobile touch hold behavior for PttButton & update KiCad files
2026-05-23 fix(dashboard): prevent text selection on Push to Talk button during long press
2026-05-23 style(dashboard): enlarge Play Audio and Push to Talk buttons slightly on mobile for better ergonomics
2026-05-23 style(dashboard): enlarge mobile buttons to full size and format active event timestamp with a comma after the day of the week
2026-05-23 style(dashboard): enlarge Play Audio and Push to Talk buttons for easier tap targets on all devices
2026-05-23 style(dashboard): capitalize AM/PM in dates and switch action buttons to vertical layout
2026-05-23 style(dashboard): set spacious fixed heights and equal widths on mobile action buttons
2026-05-23 style(dashboard): restore original horizontal layout and size for desktop viewports on action buttons
2026-05-28 feat(dashboard): add battery, clock/globe, shipments, and preset widgets to active event page
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2026-05-29 style(dashboard): move mobile battery/wifi widgets below media and fix system live text centering
2026-06-20 feat: optimize production services and systemd configurations for Raspberry Pi
    [smart-doorbell.kicad_pcb]
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2026-07-08 Update Rev B camera hardware outputs
    [bom.csv, designators.csv, positions.csv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]
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2026-07-11 Correct Rev B enclosure dimensions
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2026-07-15 Release Smart Doorbell Rev B PCB order snapshot
    Record the exact JLCPCB Gerber, BOM, and CPL files submitted on 2026-07-15, including project-local part/placement corrections and the verified native top-mask repair. Preserve the routed KiCad sources, production netlists, custom power footprints, camera documentation, assembly exclusions, and release hashes used for the five-board first-article order.
    [BOM-smart-doorbell.csv, Smart_Doorbell_Project_B_bom-JLCPCB_FINAL.csv, Smart_Doorbell_Project_B_bom.csv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]
2026-07-15 Record KiCad footprint text defaults
    Saving the ordered Rev B board with KiCad 10 materializes the existing 0.15 mm default thickness on 42 footprint text properties. Gerber geometry and IPC connectivity remain identical to the tagged o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
    [smart-doorbell.kicad_pcb]
2026-07-25 Prepare Smart Doorbell Rev C reorder
    Correct and verify the mirrored OV5640 interface, add switched camera power control and hardware bring-up modes, preserve the ordered Rev B artifacts, and add an isolated integrity-locked Rev C JLCPCB release candidate with updated documentation.
    [BOM-smart-doorbell.csv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]
2026-07-26 Record ordered Smart Doorbell Rev C release
    Freeze the exact five-board JLCPCB upload package, order identifiers, BOM matching export, and signed-off assembly preview. Preserve the immutable Rev B release, record the locked PCB state and regen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
    [JLCPCB-BOM-matching-2026-07-26.xlsx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]
2026-08-05 feat(firmware): add Rev C hardware bringup, camera power gating, and deep sleep routines
2026-08-05 feat(gateway): implement device telemetry tracking, event alert services, and system health endpoints
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2026-08-05 docs: add hardware bringup reports, firmware architecture guide, and camera capture tooling
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2026-08-07 feat(firmware,gateway): add local chime playback, Wi-Fi speedups, and alert latency fixes
    - Implement asynchronous local audio chime playback via MAX98357A on button press
    - Add Wi-Fi fast scan, static IP config support, and disable modem sleep for lower connection latency
    - Dispatch alert notifications before DB save to reduce webhook trigger latency
    - Set RestTemplate timeouts for backend alert service calls
    - Enable bootloader skip validation on deep sleep wake in sdkconfig.defaults
    [chime_player.c, doorbell_controller.cpp, wifi_bringup.c]
2026-08-08 feat(firmware): optimize chime retriggering, Ring LED breathing pulse, and EXT0 wake reliability
    - Eliminate robotic audio repeating by adding a silent DMA buffer flush and 50ms drain delay in chime_player.c.
    - Implement Ring-style continuous 3-second LED breathing pulse (25% to 100% duty) on GPIO48 with smooth 400ms fade-out on sleep entry.
    - Ensure re-triggering during active wake immediately flashes LED back up to 100% brightness before resuming breathing pulse.
    - Enable RTC internal pull-up on GPIO2 and register EXT0 wakeup unconditionally in power_manager.cpp to fix multi-ring broadcast lockouts.
    [chime_player.c, ring_fade.c]
2026-08-08 fix(gateway,firmware): support DOORBELL_REPRESS trigger and lock-free mailbox queueing
    [camera_capture.c, chime_player.c, doorbell_controller.cpp]
2026-08-08 fix(firmware): set kMaxAlertCyclesPerSession to 3 for baseline production real-world test
    [camera_capture.c, doorbell_controller.cpp, system_events.hpp]
2026-08-08 feat(firmware): restore 3:06 AM camera settings (0x0020 gain ceiling, full AEC shutter integration) for low vertical line noise
    [camera_capture.c]
2026-08-10 fix(firmware): move main task buffers off stack to prevent heap corruption
    - Move DoorbellController in app_main to static storage (app_main stack frame 1264B -> 32B).
    - Move microphone I2S scratch storage off-stack into AudioService class members (mic recording stack frame 2128B -> 80B).
    - Move intercom WAV playback conversion buffers off-stack into IntercomService class members (WAV playback stack frame 4368B -> 368B).
    - Fixes main-task stack overflow that led to delayed TLSF heap corruption during Wi-Fi re-initialization.
    [audio_service.cpp]
2026-08-10 fix(dashboard): handle CORS validation in proxy middleware to prevent origin rejection
    - Validate incoming requests in Next.js middleware using same-origin check.
    - Reject foreign origins with HTTP 403.
    - Remove Origin header on proxied internal rewrite requests to Spring Gateway to avoid CORS rejection.
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2026-08-10 feat(firmware): shorten local chime and start visitor audio capture early
    - Add chime_player_request_stop() to interrupt chime playback cleanly and release shared I2S bus.
    - Target ~400 ms local acknowledgement chime before transferring I2S bus priority to visitor microphone.
    - Overlap early notification trigger and camera path with visitor microphone recording.
    - Update architecture docs and hardware bringup notes for immediate visitor audio capture schedule.
    [chime_player.c, doorbell_controller.cpp]
2026-08-10 feat(firmware): suppress speaker during visitor capture and fix controller stack overflow
    - Add chime_player_set_suppressed() to drop chime requests while visitor mic is active.
    - Move production controller execution to a 16 KiB dedicated FreeRTOS task to prevent stack overflow during HTTP upload.
    - Filter button represses during active visitor recording to provide LED-only feedback without queueing delayed capture cycles.
    - Restrict visitor greeting capture to initial DOORBELL_PRESS event per session.
    - Update architecture documentation and bringup log.
    [chime_player.c, doorbell_controller.cpp]
2026-08-10 feat: implement multi-burst visitor session grouping and gateway session tracking
    - Add VisitorSession and VisitorRecording entities, repositories, and VisitorSessionService in gateway.
    - Update EventController with session-aware event processing, multi-burst event correlation, and retention cleanup.
    - Refactor dashboard timeline pages and components to group events into visitor sessions.
    - Enhance ESP32-S3 firmware controller, audio service, and Wi-Fi connectivity manager for multi-burst session lifecycle and fast reconnects.
    - Update behavioral spec and architecture documentation.
2026-08-10 feat(dashboard): add session timeline component, audio player, and enclosure docs
    - Add SessionTimeline component for displaying visitor session timelines with multi-burst event details.
    - Add AudioPlayer component for inline visitor greeting playback.
    - Update dashboard styles, event drawer, and calendar views for session grouping.
    - Add enclosure construction guide and update Rev B handoff documentation.
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2026-08-13 fix(dashboard): use Title Case for Household Access, protect cookies during backend restarts, and ignore .pi-production
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2026-08-13 fix(dashboard): check bootstrap status on setup page and clean up revoked device cookies
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2026-08-16 feat(firmware): permit complete chime waveform during camera overlap and avoid muting chime on intercom stop
    [chime_player.c, doorbell_controller.cpp]
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2026-10-24 Reconnect stalled dashboard event streams and add presentation mode
    The browser gave up on the event stream after any non-stream response
    (proxy 502/524, service restart) and never noticed silent drops after
    sleep or network changes, so new presses only appeared after a reload.
    Watch the gateway heartbeat, reconnect on stalls, errors and network
    recovery, and reload history after each reconnect.
    ?present hides sessions that started before the page was opened, for
    screen recordings that should only show new visitors.
2026-10-24 Mirror visitor photos in the dashboard to undo the camera's hmirror
    Production capture sets hmirror=1, so stored photos are mirrored left to
    right and text in frame reads backwards. Flip them at display time until
    the firmware is changed to hmirror=0; remove .visitor-photo then.
2026-11-08 Show Rev A, B, and C board renders as a revision timeline
    Replace the single Rev C render with matching KiCad 3D renders of each revision, caption the design history, and move the schematic to its own row.
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2026-11-08 Describe the Rev C camera FPC pin mapping fix accurately
